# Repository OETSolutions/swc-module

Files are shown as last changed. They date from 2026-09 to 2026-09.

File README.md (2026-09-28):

# SWC — Steering Wheel Controls Adapter

A programmable interface between a vehicle's factory steering-wheel buttons and
an aftermarket Android head unit, so the buttons can be re-mapped, combined, or
given press behaviours the factory wiring never had.

**Status:** design complete and routed; 0 DRC errors, 0 unconnected, 0
schematic/PCB parity errors. **Not yet ordered.**

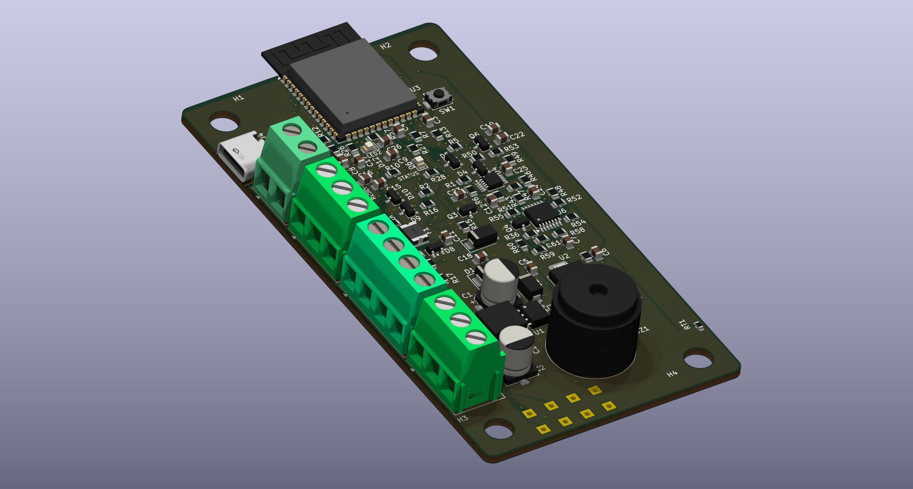
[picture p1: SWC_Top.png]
SWC adapter, top
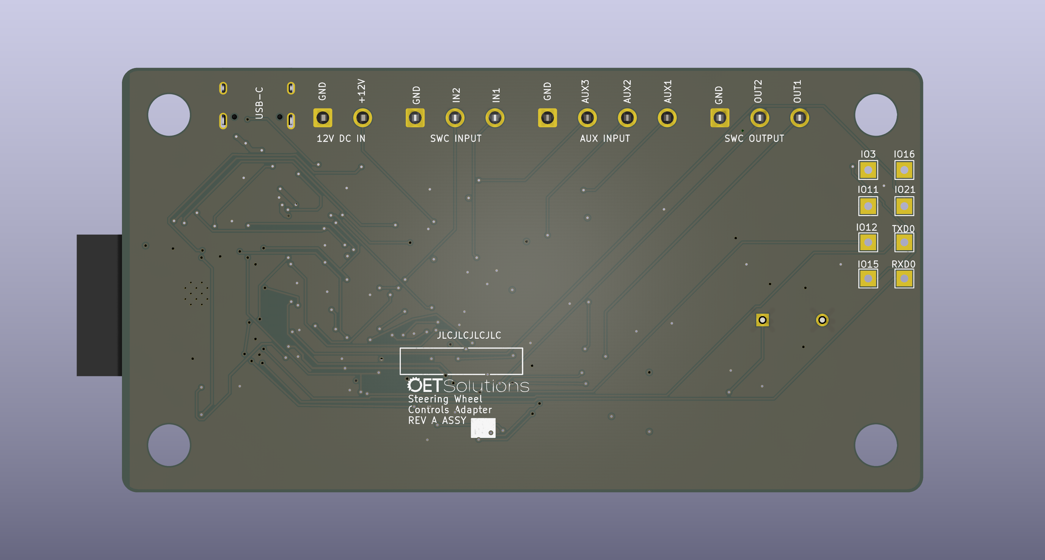
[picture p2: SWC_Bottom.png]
SWC adapter, bottom
|  |  |
| :--: | :--: |
| **Top** — ESP32-S3 module, four left-edge screw terminals, USB-C | **Bottom** — connector pinouts silkscreened on the back |

| Item | Value |
| --- | --- |
| **Board** | 54.0 × 102.0 mm, 4-layer, 1.6 mm, rounded corners r ≈ 2.83 mm |
| **EDA** | KiCad 10 (`SWC.kicad_pcb` / `.kicad_sch` / `.kicad_pro`) |
| **Assembly** | JLCPCB, Economic PCBA, 5-off |
| **Parts** | 34 unique LCSC part types, JLCPCB-assembled |
| **MCU** | DOIT ESPS3-32-N4 (ESP32-S3-WROOM-1 clone), native USB-CDC + USB-JTAG |

## Why this exists

A steering-wheel button is not a digital switch. It is a resistor dropped across
a single analog **KEY** line; the head unit pulls that line up and identifies the
pressed button from the voltage it reads. There are usually two such lines —
this board calls them **SWC1** and **SWC2** — with the buttons split between
them.

That arrangement is cheap and robust, and also completely fixed: the resistor
values, and therefore the head unit's behaviour, live in the factory button pod.
An aftermarket head unit wants a specific resistance it was taught, or one the
user can program. This adapter supplies it by reading the ladder on one side and
*servoing* the head unit's KEY line on the other, so the mapping becomes
software. It can additionally send commands to the head unit over USB when a
button is pressed, for actions the head unit's own steering-wheel input cannot
express.

## Architecture at a glance

Two identical channels. The factory ladder is read by the ESP32-S3's ADC; the
head unit's KEY line is driven by a closed-loop servo, so the output tracks what
the board actually senses rather than what it assumes.

```text
  SWC1  J2.3 ─R1 10k─┬─ /SWC1_ADC ─────────► U3 ADC1
  SWC2  J2.2 ─R2 10k─┴─ /SWC2_ADC ─────────► U3 ADC1
        (R15/R16 10k pull-ups to +3V3 · D4/D5 BAT54S clamp · C3/C4 100nF)

  AUX1  J5.4 ─R23 1k─┬─ /AUX1_F ───────────► U3 ADC
  AUX2  J5.3 ─R24 1k─┤   /AUX2_F
  AUX3  J5.2 ─R25 1k─┴─ /AUX3_F
        (R17/R18/R19 10k pull-ups to +3V3 · D8/D9/D10 BAT54S · C15–C17 100nF)

  U3 ESP32-S3 ══ I2C, 3.3 V, R5/R6 10k pull-ups ══ U4 MCP4728  (VDD = +3V3,
       │                                              VREF = VDD, 0–3.3 V FS)
       │                                              ┌ A ─ signal, ch 1
       │                                              ├ B ─ gain mode, ch 1
       │                                              ├ C ─ signal, ch 2
       │                                              └ D ─ gain mode, ch 2
       │
       └─ per channel:  U4.VOUTx ─R46 100k─► U6x− ─(C24 100nF fb)─► U6x out
                                          U6x+ ◄─ R58 82k ─ V_buf
                                              ◄─ R61 100k ─ V_ADJ (VOUTB/D)
                        U6x out ─R52 1k─► Q4 gate ─► Q4 drain = KEY line
                        KEY ─R36 1M─► U6y buffer ─┬─► R54 10k / R50 10k ─► /SENSEx ─► U3 ADC
                                                   └─► R58 (feedback above)

  12 V ─ J1 ─ F1 PPTC ─► /+12V_SW ─► D1 SMBJ18A ─► U1 XL1509-5.0 ─► L1 47µH ─┐
                                                  (D7 SS34 freewheel)         │
  USB VBUS ─ J4 ─ F2 PPTC ─► /VBUS_FUSED ─► D3 SS34 ─┐                        │
                                                     ├─► +5V ─► U2 AMS1117 ─► +3V3
                              /+5V_BUCK ─► D2 SS34 ──┘
  NTC RT1 on /TEMP_ADC · buzzer BZ1 via Q3 · LEDs D6 / D12 · VBUS detect /VBUS_VALID
```

The three ideas that make it work:

- **The ladder is read, not re-created.** 10 kΩ series (1 kΩ on the AUX inputs),
  a BAT54S clamp to +3V3/GND, a filter, and a pull-up — so a bare
  switch-to-ground button works as well as a resistor ladder.
- **The output is a servo, not a buffer.** `V_KEY = (1 + R58/R61)·V_DAC −
  (R58/R61)·V_ADJ`, so the gain is a resistor ratio and the offset is a second
  DAC channel. That gives runtime range switching between 3 V and 5 V head
  units, and it is why the ESP32 needs no DAC of its own (the S3 has none).
- **Idle is inherently high-impedance.** The sink FET only pulls down; a command
  above the head unit's own idle voltage turns it off and the line floats back up
  through a 1 MΩ sense resistor.

Full description, including the analog detail, the power path, the USB front end,
and the reasoning behind each component choice: **[DESIGN.md](DESIGN.md)**.

## Repository guide

| Document | Contents |
| --- | --- |
| **[MANUAL.md](MANUAL.md)** | How to install and use the adapter — wiring, learning buttons, bindings, the app, firmware updates, troubleshooting |
| **[DESIGN.md](DESIGN.md)** | Requirements, block diagram, theory of operation, design rules, key design decisions |
| **[MANUFACTURING.md](MANUFACTURING.md)** | BOM generation, part list, assembly-cost analysis, fabrication output, ordering decisions |
| **[CHANGELOG.md](CHANGELOG.md)** | Revision history, accepted limitations, open items |
| **[AGENTS.md](AGENTS.md)** | How to work on the files — rules, MCP servers, skills, verify loop, gotchas. `CLAUDE.md` points here. |
| **[tools/README.md](tools/README.md)** | The sanctioned direct-write scripts, in detail |

The live project is `SWC.kicad_sch` / `SWC.kicad_pcb` / `SWC.kicad_pro` /
`SWC.kicad_sym` / the two library tables. `3dmodels/` and
`footprints/logo.pretty/` are required project-local assets; `tools/` holds the
sanctioned direct-write scripts; `SWC-backups/` and `SWC2-backups/` are the
restore path; `old/` is the 2022 RP2040 design, kept for reference only. The
full annotated layout, including what is git-ignored, is in
**[AGENTS.md](AGENTS.md)**.

## Toolchain and credits

This board was developed with a small set of external tools, all worth citing:

- **[KiCad 10](https://www.kicad.org/)** — the EDA suite. All file manipulation
  in this project goes through an MCP server rather than hand-editing.
- **[mcp-server-kicad](https://github.com/ProductOfAmerica/mcp-server-kicad)**
  (`uvx --from mcp-server-kicad mcp-server-kicad`) — the MCP server providing
  byte-preserving schematic, PCB, ERC/DRC and manufacturing-export tools. It is
  the reason every change here is scriptable and repeatable.
- **[pcbparts-mcp](https://github.com/Averyy/pcbparts-mcp)**
  (`https://pcbparts.dev/mcp`) — component search, JLCPCB stock and
  cross-reference, reference-board lookup, and PCB design rules. Used for the
  part-selection and stock-availability pass.
- **[KiStack](https://github.com/American-Embedded/kistack)** by American
  Embedded — a human-written set of KiCad skills (schematic, PCB, BOM, export,
  gerbers, footprint, symbol, panelize, product render) that standardised the
  workflow. Installed with `npx skills add American-Embedded/kistack`.
- **JLCPCB component skills** — `jlcpcb-component-finder` (part search by
  keyword, package, stock and price) and `jlcpcb-bom-generate-from-kicad` (KiCad
  BOM/position → JLCPCB PCBA order format), with its database refreshed from
  [jlcparts](https://yaqwsx.github.io/jlcparts/).

The per-tool notes and the working rules for this repository live in
**[AGENTS.md](AGENTS.md)**.

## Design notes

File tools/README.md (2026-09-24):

# `tools/` — the sanctioned direct writers

The kicad MCP server covers almost everything, but a few writes have no MCP tool
at all. These scripts are the one sanctioned exception.

**Still in force:** never hand-edit `.kicad_sch` / `.kicad_pcb` / `.kicad_sym` /
`.kicad_mod` / `.kicad_pro`, and avoid running `kicad-cli` directly. Prefer an MCP
tool whenever one exists. A script here is only for the gaps below.

Every script is narrow by construction: it acts on what is named on the command
line (one footprint, one model, one via, one field) and refuses ambiguous input
rather than guessing. The read-only ones are marked; run those freely.

## Scripts

| Script | Purpose | Writes? |
| --- | --- | --- |
| `addmodels.py` | Give the six model-less footprints (J1–J5, F1) their 3D model, with measured offsets. **Re-run after any footprint-library resync.** | yes |
| `pcbfields.py` | Place every PCB reference designator in a legal, readable spot. **Re-run after any resync.** | yes |
| `fieldplace.py` | Shared CST + geometry helper — imported by 15 of the other scripts here. Run standalone it also autoplaces schematic fields (the MCP server cannot set a field's *position*). | yes |
| `setfield.py` | Pin one footprint's Reference field to an explicit board position. | yes |
| `fptext.py` | Move one footprint's own printed silk text (an `fp_text` node — BZ1's "(+)" is the one on this board). No MCP tool reaches an `fp_text`. Costs a `lib_footprint_mismatch`. | yes |
| `silksearch.py` | Find a DRC-legal spot for one footprint's Reference field. | no |
| `silk.py` | Silkscreen text audit: the drawn angle of all 140 labels, plus text-vs-pad, text-vs-text and off-board tests. | no |
| `fieldsize.py` | Set one footprint field's text size. | yes |
| `padangle.py` | Set the pad-level `at` angle of every pad in one footprint. | yes |
| `modelrot.py` | Set one footprint's 3D-model rotation (for testing a model-orientation question). | yes |
| `modelcheck.py` | Does each retrieved 3D model actually cover the footprint it sits on? | no |
| `delvia.py` | Delete vias at named coordinates. No MCP tool can remove a via. Refuses a coordinate that does not match exactly one via. | yes |
| `keepoutflags.py` | Loosen a keepout's item flags, leaving its copper restrictions alone. | yes |
| `zoneisland.py` | Show, and optionally set, a zone's island-removal mode. | yes |
| `holes.py` | Name the mounting holes and square them up against the board edge. | yes |
| `boardgeo.py` | Board-space geometry: outline, courtyards as polygons, real collisions. | no |
| `box.py` | List every segment/via/pad intersecting a box, any net. | no |
| `j4rip.py` | List J4-net copper intersecting a region, with connectivity, so the rip set can be decided precisely. | no |
| `j4new.py` | J4 fan-out design + DRC-true clearance checker. | no |

Two more scripts are **retired — SWC2-era, written against the pre-rework
board**, and both **keep** the stale `SWC2.kicad_pcb` path on purpose: it fails
loudly rather than printing confident, wrong numbers. Neither's output
describes what is on `SWC.kicad_pcb`. Kept for provenance; read the header
before trusting either.

| Script | Purpose | Writes? |
| --- | --- | --- |
| `corridor_check.py` | USB / VBUS corridor verifier: clearance, track width vs net requirement, net connectivity. Its clearance model disagrees with KiCad's DRC on the reworked board (~48 phantom violations) — see its header. | no |
| `j4fan.py` | J4 (USB-C) fan-out designer/checker for the *rejected* placement (rot 90 @ 21.35; live is rot 270 @ 19.65, 48.206). | no |

## Two conventions that keep costing rounds

Both have been re-derived from scratch at least twice, each time after a wrong
answer had already been acted on. Neither is guessable — take the constants
from `silk.py` and `boardgeo.py` rather than writing them again.

**The footprint-local → board transform.** For a footprint at `(x, y)` at stored
angle `t` and a local point `(lx, ly)`:

```
bx = x + lx*cos t + ly*sin t
by = y - lx*sin t + ly*cos t
```

Note the sign on `sin`. `silk.rot_pt`, `silksearch.rot_pt` and
`boardgeo.rot_pt` are all this function — if you need it, import it, do not
write a fourth copy. A version with the sign the other way was live in
`silksearch.py` until 2026-09-10 and silently mis-placed every obstacle
belonging to a footprint at ±90°; only parts at 0/180 came out right, which is
why it survived a whole placement pass. Three independent checks pin it:
`boardgeo`'s docstring (two DRC messages on J1 and J4), KiCad's own F.SilkS SVG
(F2's field plots at 28.619, 43.820, which the wrong sign puts at 33.619,
56.320), and `get_footprint_bounds` on F2 (30.169..32.069 × 48.390..51.750).

**The drawn angle of a footprint field is the STORED angle alone** — not
`footprint + stored`. `silk.drawn_angle` is the definition; `pcbfields.py`
writes it, and `setfield.py` and `fptext.py` used to write `ang - frot` and
turn a designator meant to lie flat into one standing on end.

When a claim about geometry is in doubt, the tie-breakers, in order, are: DRC's
own message text, `mcp__kicad__export_pcb` to SVG (text elements carry an
explicit `rotate(...)` and `textLength`), then `get_footprint_bounds`. Not
arithmetic, and not a tool's own summary of itself.

## Running them

The board path is usually the argument (some take further flags; run with no
arguments or read the docstring for usage):

```
python3 tools/addmodels.py SWC.kicad_pcb
```

The writers use the MCP server's own s-expression parser
(`mcp_server_kicad._cst`) so their output matches KiCad's byte for byte.
`fieldplace` (imported by all of them) puts that package on `sys.path` itself,
resolving it from `SWC_MCP_SERVER_KICAD` if set or otherwise from the `uvx`
cache (`~/.cache/uv/archive-v0/*/mcp_server_kicad`) — set `SWC_MCP_SERVER_KICAD`
to the directory that contains `mcp_server_kicad/` to pin it explicitly, e.g. in
CI or a checkout where the module is vendored elsewhere.
`addmodels.py`, `pcbfields.py` and friends are idempotent — running one twice
changes nothing the second time.

They self-locate their imports, so they work from any working directory.

## `addmodels.py` in particular

It carries the measured derivation of every offset, including J4's, in its
docstring. Read it before changing an offset: both previous versions of the J4
note were wrong, and each wrong version cost a full round of rework. The short
version is `rotate (0 0 180)`, `offset (0 −1.07 0)`, and the reason the offset
cannot be derived from the STEP's `CARTESIAN_POINT`s is that KiCad applies the
STEP's internal placement (~2.1 mm in Y for this vendor file).

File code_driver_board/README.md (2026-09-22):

# SWC rig driver — the second board that drives the device under test

This project is the firmware for the board that **presents stimuli to the SWC
adapter under test** so its firmware can be exercised end to end with no vehicle
and no steering-wheel pod.

It is deliberately **separate from the two other firmware projects in this repo**:

| Project | What it is | Board |
| --- | --- | --- |
| `code/` | the product firmware | the device under test (DUT) |
| `code_board_test/` | the bring-up / hardware-test tool | one board, self-contained |
| **`code_driver_board/`** | **this** — the rig driver | the second board |

It shares no build with either. The hardware facts it needs (pin map, DAC frame,
servo transfer function) are **copied** from `code_board_test`, which in turn
cross-checked them against `production/netlist.ipc`. Both boards are the same
hardware, so the pin map is identical.

## The rig

Two SWC boards. The **driver** board's analog output is wired into the **DUT**
board's analog input; the driver presents a *button* by sinking that node, exactly
as a real button on a real steering wheel does.

```
        DRIVER BOARD                            DUT BOARD (code/)
        ┌──────────────┐                        ┌──────────────┐
        │ J3.3 KEY1 ───┼──── ladder stimulus ───┼─ J2.3 SWC1   │
        │ J3.2 KEY2 ───┼────────────────────────┼─ J2.2 SWC2   │
        │ J5.4 AUX1 ───┼──── programming sw. ───┼─ J5.4 AUX1   │
        │          GND ┼────────────────────────┼─ GND         │
        └──────────────┘                        └──────────────┘
             USB (console)                    USB (console + Android app)
```

- **A press is a low KEY voltage.** The driver's servo sinks the DUT's ladder
  node; releasing lets the DUT's own 10 kΩ pull-up set the node high again. There
  is no separate "button" wire — the analog level *is* the button.
- **AUX1 is the programming switch.** The driver's AUX1 pin sinks the DUT's AUX1
  to GND (R23 is shorted on the DUT, so the 1 kΩ series resistance is gone). Closed
  = programming button held. Open = the DUT's pull-up holds it released.
- **Common ground is required.** Without it nothing reads correctly and the failure
  looks like a dead DUT.

The loopback jumpers the bring-up tool used are **not** part of this rig — those
existed only to verify a freshly-assembled board's own signal chain, and they are
not needed here.

## What it can present

| Command | Action |
| --- | --- |
| `1` | a **SINGLE** press — press, release, then wait out the DUT's double-press window |
| `2` | a **DOUBLE** press — two presses inside the window, then the window |
| `3` | a **LONG** press — hold past the DUT's long-press threshold |
| `p` / `r` | press and hold / release, for manual timing |
| `l` | **LEARN** — close AUX1 *and* hold the key, then release (the §7.4 entry gesture) |
| `L` | **MAINTENANCE** — hold AUX1 alone ~3 s (opens the ~5 min window) |
| `a` | toggle the AUX1 programming switch by hand |
| `c` | toggle which DUT channel (SWC1 / SWC2) the stimulus is presented on |
| `m` / `M` | cycle the gain mode / auto-select it from the released level |
| `+` / `-` | nudge the commanded key level by 50 mV |
| `d` | diagnostic — what the KEY line rests at, and whether a command is reachable |
| `w` | watch the DUT's KEY **output** (loopback) for ~2 s, min/max/mean |
| `s` | status |

A gesture is a **timeline**: a press of `press_on_ms`, held, at a commanded key
voltage `key_mv`, and the DUT's own limits decide whether that is a SINGLE, a
DOUBLE or a LONG. Those limits are mirrored from the product firmware
(`code/lib/Gesture/PressClassifier.h`) in `include/DriverHarness.h` and asserted
by the host tests, so a mistimed press is a **failed host test**, not a
misclassified gesture on the bench.

## Building and running

```bash
cd code_driver_board

# Host tests — the gesture-timeline geometry, no board needed (~1 s)
pio test -e host

# Device build
pio run -e swc-s3-driver
```

## The one non-obvious build fact

**`lib/swc_logic` is compiled explicitly, through `build_src_filter`, not by the
library dependency finder.** In this project LDF resolves only the framework
libraries and never the project's own `lib/` — verified by probing with a trivial
library referenced directly from `src/`, which LDF still did not find. The failure
mode is not a clear one: LDF reports success, the pure-logic sources are simply
absent from the link, and the build dies with a wall of `undefined reference to
Output::` errors that read as a code problem. Both envs compile the sources
explicitly; the device env adds `+<../lib/*/*.cpp>` to the default `+<*>`.

## Timing, and what to change when the DUT moves

`Harness::kDefaultRig`:

| Field | Default | Bound by |
| --- | --- | --- |
| `key_mv` | 1240 | the learned button's `mv_center` on the DUT channel |
| `press_on_ms` | 150 | must be ≥ debounce (25) and < long (750) |
| `inter_press_ms` | 120 | must be < the double window (500) and > 0 |
| `long_press_ms` | 750 | the DUT's long-press threshold |
| `double_window_ms` | 500 | the DUT's double-press window |

`Harness::Validate()` returns the first way the config fails to produce the
gesture it names, and `s` prints it — so a typo is a message, not a silent
misclassification.

## Reading a result

The driver only **presents** stimuli. What the DUT *does* with them it reports
itself: its buzzer and LEDs on the bench, and its USB frames (visible in the
Android app or a serial monitor on the DUT's port). The driver prints what it
drove; the DUT tells you what it resolved. Compare the two.

The **loopback** (DUT SWC out → driver SWC in) closes the other direction: `w`
reads what the DUT is actually commanding on its KEY line, so "the DUT emitted an
event but nothing reached the head unit" is told from a reporting bug.

## Findings from the first session on hardware (2026-09-24)

The rig works end to end. The analog path was proven with the DUT's own frames:
with the driver presenting 1240 mV on channel 1, the DUT's `ladder_sample`
stream read **1206 mV**, a `learn_commit` stored it as `mv_center:1205,
mv_tolerance:120`, and a subsequent synthetic SINGLE classified as
`event{channel:0, button:"rig1", gesture:"SINGLE"}` — with `config_state`
flipping `"none"` → `"ok"`.

**One DUT defect found: a learned-only button (no binding) re-emitted its gesture
every poll tick while held, and never advanced to a later gesture.** Measured on
hardware: a 2 s steady hold at the learned level produced 26–177 identical
`event{…,"gesture":"SINGLE"}` frames ~70 ms apart, versus exactly 1 at a higher
button level.

The mechanism, from the loopback (`w`): the DUT drives its KEY pulse, and its
**own** KEY sense reads that pulse below the 1800 mV envelope floor, so
`head_unit_gone` went true, the tail did `ReleaseKey + gestures.Reset()` every
tick, and the next tick re-classified the still-held press and re-emitted. A
learned-only button (the headless learn path — `ConfigDefault` ships
`binding_count = 0`) maps to the command-band floor of 1800 mV, which is what
tripped it; a bound `OUT_VOLTAGE` at a higher level did not. `gestures.Reset()` on
the recurring `head_unit_gone` condition also discarded the press state, so a held
button could never reach LONG.

Not a rig problem, and not a duplicate-emit bug in the emit path — the
head-unit-gone response acting on the DUT's own output through its own sense node.

**FIXED 2026-09-24** in `SystemOrchestrator::HeadUnitGone`. `V_KEY_idle` is the
line's IDLE, so the envelope is only meaningful on a *released* line; while the
device DRIVES, the sense node reads the device's own output and there is no
head-unit reading to take. A driven line is now judged only on a DEEP sag: every
command clamps to the band floor, so a reading at or above `kFaultSagMaxMv`
(1600 mV, the floor less a 200 mV margin) is one we produced, not a fault. A rail
collapse still drives the line far below that and still releases (FR-39's
phantom-key hazard). The verdict also now has to persist for 250 ms
(`kHeadUnitGoneSettleMs`), so a line settling after a pulse — or a rail coming up
at boot — is not mistaken for an absent head unit.

Regression test `ADrivenLineAtTheCommandFloorIsNotAHeadUnitGoneFault`
(`SystemOrchestratorTest.cpp`), mutation-checked: removing the sag guard fails
exactly that test. `ARailSagDuringAPressReleasesTheKey` still covers the deep-sag
release. Native suite 503 → 504.

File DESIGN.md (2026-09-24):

# Design document — SWC Steering Wheel Controls Adapter

Engineering description of the board: requirements, theory of operation,
component choices, and the reasoning behind them. For what the project is and
how to build it, see [README.md](README.md). For sourcing and fabrication, see
[MANUFACTURING.md](MANUFACTURING.md). For how to work on the files, see
[AGENTS.md](AGENTS.md).

- [1. Requirements](#1-requirements)
- [2. Prior design](#2-prior-design)
- [3. Block diagram](#3-block-diagram)
- [4. Theory of operation](#4-theory-of-operation)
- [5. Design rules and stackup](#5-design-rules-and-stackup)
- [6. Key design decisions](#6-key-design-decisions)
- [7. Open items](#7-open-items)

## 1. Requirements

The design brief, in full:

- ESP32 module; USB-C to the head unit (the ESP32 enumerates as a USB CDC
  serial device and takes commands).
- Two identical channels: ladder → ADC → translate → DAC → head-unit KEY input.
- The DAC range must sit **within the head-unit input range sensed at startup**.
- The output must be **isolated / high-impedance when idle**, so the head-unit
  KEY line floats to its own Vcc when not driven.
- Single, double and long-press translation, with a temperature sensor to
  compensate for ladder drift over the cabin temperature range.
- Screw terminals on the board edge for power, inputs and outputs; USB-C on an
  edge.
- JLCPCB assembly, stock parts, Economy/Basic tier where possible; **Extended
  parts only if there is absolutely no alternative.**
- Professional schematic and layout; clean ERC and DRC.

## 2. Prior design

This is a redesign of a 2022 RP2040 board. Its sources are archived under
`old/` and are reference only. Its specific failures — the reason this board
exists — were:

- it used a **digital pot**, which was not precise enough (this board uses a
  12-bit DAC with a servoed output instead);
- **no auto-ranging** to the head unit's sensed input voltage;
- **no temperature compensation**;
- it was a Pi Pico module build, not a custom PCB.

## 3. Block diagram

Two identical channels, **SWC1** and **SWC2**. Every part below is per channel
unless noted; channel 2 mirrors channel 1 with the `C`/`D` halves of the DAC and
quad op-amp.

```text
  SWC1  J2.3 ─R1 10k─┬─ /SWC1_ADC ─────────► U3 ADC1
  SWC2  J2.2 ─R2 10k─┴─ /SWC2_ADC ─────────► U3 ADC1
        (R15/R16 10k pull-ups to +3V3 · D4/D5 BAT54S clamp · C3/C4 100nF)

  AUX1  J5.4 ─R23 1k─┬─ /AUX1_F ───────────► U3 ADC
  AUX2  J5.3 ─R24 1k─┤   /AUX2_F
  AUX3  J5.2 ─R25 1k─┴─ /AUX3_F
        (R17/R18/R19 10k pull-ups to +3V3 · D8/D9/D10 BAT54S · C15–C17 100nF)

  U3 ESP32-S3 ══ I2C, 3.3 V, R5/R6 10k pull-ups ══ U4 MCP4728  (VDD = +3V3,
       │                                              VREF = VDD, 0–3.3 V FS)
       │                                              ┌ A ─ signal, ch 1
       │                                              ├ B ─ gain mode, ch 1
       │                                              ├ C ─ signal, ch 2
       │                                              └ D ─ gain mode, ch 2
       │
       └─ per channel:  U4.VOUTx ─R46 100k─► U6x− ─(C24 100nF fb)─► U6x out
                                          U6x+ ◄─ R58 82k ─ V_buf
                                              ◄─ R61 100k ─ V_ADJ (VOUTB/D)
                        U6x out ─R52 1k─► Q4 gate ─► Q4 drain = KEY line
                        KEY ─R36 1M─► U6y buffer ─┬─► R54 10k / R50 10k ─► /SENSEx ─► U3 ADC
                                                   └─► R58 (feedback above)

  12 V ─ J1 ─ F1 PPTC ─► /+12V_SW ─► D1 SMBJ18A ─► U1 XL1509-5.0 ─► L1 47µH ─┐
                                                  (D7 SS34 freewheel)         │
  USB VBUS ─ J4 ─ F2 PPTC ─► /VBUS_FUSED ─► D3 SS34 ─┐                        │
                                                     ├─► +5V ─► U2 AMS1117 ─► +3V3
                              /+5V_BUCK ─► D2 SS34 ──┘
  NTC RT1 on /TEMP_ADC · buzzer BZ1 via Q3 · LEDs D6 / D12 · VBUS detect /VBUS_VALID
```

## 4. Theory of operation

### 4.1 Inputs

**SWC1 / SWC2.** The steering-pad ladder is a **series resistor chain whose
common is tied to GND**; each button shunts a different point in the chain to
that common, so a press pulls the input **down**. Idle (no button) is therefore
the *high* state, set by the **10 kΩ pull-up** (`R15`/`R16`) to +3V3. Each input
takes a **10 kΩ series resistor** (`R1`/`R2`) into a **BAT54S** clamp
(`D4`/`D5`) to +3V3/GND (protection only, not the operating point), a 100 nF
filter (`C3`/`C4`), and that pull-up. The pull-up is what lets a bare
switch-to-ground button work as well as a ladder. Both SWC lines land on the
ESP32-S3's ADC inputs.

> **Correction (2026-09-18).** This paragraph previously said the ladder is
> "pulled to 12 V when idle", which is wrong and inverts the direction a press
> moves the input. Verified against `Tundra_SWC_steeringpadswitch.bmp` in the
> Android_Stereo_Apps working notes and with the board's owner. The ladder
> resistances are vehicle-specific, so **`R15`/`R16` may need adjusting to spread
> the buttons adequately across the ADC range** — measure before assuming.
> The firmware spec's §2.4/§6.3 carry the corrected derivation.

**AUX1–AUX3.** On the 4-pin `J5` terminal, intended for extra buttons or
programming functions. Identical conditioning but with a **1 kΩ series
resistor** (`R23`–`R25`) rather than 10 k, the same BAT54S clamp
(`D8`–`D10`), 100 nF (`C15`–`C17`) and 10 kΩ pull-ups (`R17`–`R19`). All three
sit on ADC-capable module pins.

All three terminals that carry signals — `J2` (inputs), `J3` (outputs) and `J5`
(AUX) — include a **GND pin**, so each cable carries its own reference.

### 4.2 The ESP32-S3 and its analog ceiling

Two facts drive the whole analog design, and both are worth stating explicitly
because they have been gotten wrong before:

- **The ESP32-S3 has no DAC at all.** The classic ESP32's 8-bit DAC did not
  carry over to the S3. This is why the external DAC is not optional.
- **The S3's calibrated ADC ceiling is 2.9 V**, not 3.1 V, at the 12 dB
  attenuation setting. Every divider on the board is scaled against 2.9 V.

The module's native USB provides both the CDC interface to the head unit and
USB-JTAG for debugging.

### 4.3 DAC

`U4` is an **MCP4728** quad 12-bit I²C DAC. It runs from **+3V3** with
**VREF = VDD**, so its full-scale output is 3.3 V (1 LSB = 0.806 mV) — it is
*not* the 4.096 V internal-reference mode, which would require VDD ≥ 4.096 V.
Because the DAC is on 3.3 V, it shares the ESP32's I²C bus **directly**, with
`R5`/`R6` 10 kΩ pull-ups to +3V3 — there is **no level shifter**. A level
translation stage would be needed only if the DAC ran on 5 V; it does not. Its
LDAC pin is driven from a GPIO (`R13` 10 kΩ pulldown) and its `RDY/BSY` is left
unconnected.

The four channels are paired per signal channel: **A = signal and B = gain mode
for channel 1; C = signal and D = gain mode for channel 2.**

### 4.4 Output servo

**The output is a closed-loop servo, not an open-loop buffer.** Per channel,
the DAC voltage enters `U6A`'s inverting input through `R46` (100 kΩ), with
`C24` (100 nF) as feedback — an **integrator**. At DC the integrator forces no
current through `R46`, so `U6A−` equals the DAC voltage, and the op-amp forces
`U6A+` to match. `U6A+` is the summing junction of `R58` (82 kΩ, from the
sensed KEY-line voltage `V_buf`) and `R61` (100 kΩ, from the gain-mode DAC
output). Solving gives the load-bearing relation:

```text
V_KEY = (1 + R58/R61)·V_DAC − (R58/R61)·V_ADJ
```

So **the gain is set by the resistor ratio alone, and `V_ADJ` shifts the
offset** — it does not change the gain. `U6A`'s output drives the sink FET `Q4`
gate through `R52` (1 kΩ), with `R48` (100 kΩ) holding the gate low if the
op-amp is unpowered.

**The gain-mode channel is a range selector.** `R58/R61` = 82 k/100 k gives a
gain of 1.812, which is what lets a 3.3 V DAC drive a 5 V head unit. The mode is
chosen by what the `V_ADJ` channel does:

| Head unit | `V_ADJ` channel | Mechanism | Gain |
| --- | --- | --- | --- |
| **5 V range** | powered down (`PD1:PD0 = 01`) | 1 kΩ path to GND — current flows in `R58` | **1.812** |
| **3 V range** | normal, tracking the signal channel's code | `V_ADJ = V_DAC` — no current in `R58` or `R61` | **1.000** |

This is a defined path rather than a leakage one, which is the point: the
MCP4728 has **no high-impedance state** — all three of its power-down modes are
pull-downs to GND at 1 kΩ, 100 kΩ or 500 kΩ. The 1 kΩ power-down is exactly
what the 5 V mode wants, so a DAC channel can be used as a switch without any
leakage error. A series MOSFET was considered and rejected — see
[§6](#6-key-design-decisions).

Two consequences worth knowing:

- **The real ceiling is the op-amp rail, not the gain.** `U6` runs on +5 V, so
  `V_buf` cannot exceed ~4.98 V. Gain 1.812 advertises 6.0 V but the KEY line
  can only be actively servoed to about 5 V; the extra gain is *release margin*,
  putting the release command safely above idle rather than on the boundary.
- **The ADC can never saturate.** See [§4.5](#45-sense).

### 4.5 Sense

The KEY line is buffered by `U6B`, wired as a unity-gain follower (`U6.6` tied
to `U6.7`), reading through `R36` (1 MΩ) — so the sense path presents a picoamp
load to the head-unit line and never loads it. The buffer output then feeds two
places: back into the servo as `V_buf`, and through a **10 kΩ / 10 kΩ divider**
(`R54`/`R50`) into `/SENSE1` with a 100 nF anti-alias capacitor (`C22`).

The divider is an **exact ÷2**, so `V_SENSE = V_KEY/2`. Because the op-amp rail
binds first (V_buf ≤ ~4.98 V), the sense node can never exceed ~2.49 V — safely
*under* the S3's 2.9 V calibrated ceiling. **The op-amp rail protects the ADC
for free, and the ADC can never saturate.**

Measuring `V_SENSE` at startup, with the output released, is how the firmware
learns the head unit's own idle/float voltage and so auto-ranges its output — one
of the capabilities the 2022 design lacked ([§2](#2-prior-design)).

### 4.6 Idle is inherently high-impedance

Releasing the line needs no special mode. `Q4` **only sinks**: it pulls the KEY
line down to ground. Commanding a target *above* the head unit's idle voltage
makes the servo drive the gate low, `Q4` turns off, and the line floats up to the
head unit's own pull-up through only `R36` (1 MΩ) into the follower's input.

Power-up safety follows: with the DAC at zero the loop would servo the line to a
stuck press, so the firmware programs the MCP4728's EEPROM so that channel A
resets to full scale — the maximum command — and the gain-mode channel resets
powered-down. That yields a 5 V-range command that releases both 3 V and 5 V head
units.

### 4.7 Power

Both a 12 V feed and USB VBUS can power the board, and — importantly — **the
12 V feed is optional**. Diode-OR'd at +5 V, either source alone is sufficient;
if both are present the higher one supplies the rail.

- **12 V path:** `J1` → `F1` PPTC (1.5 A) → `/+12V_SW` → `D1` SMBJ18A TVS →
  `U1` XL1509-5.0 buck with `L1` (47 µH); **`D7` (SS34) is the freewheeling
  diode** on the switch node.
- **USB path:** `J4` VBUS → `F2` PPTC (1.0 A) → `/VBUS_FUSED` → **`D3` (SS34)**.
- **Buck output:** `/+5V_BUCK` → **`D2` (SS34)**.
- `D2` and `D3` are the OR-ing diodes. Each source therefore has its own PPTC
  and its own Schottky, so a fault on one cannot back-feed through the other.
- **3.3 V:** `U2` AMS1117-3.3 from +5 V.
- Bulk 100 µF/50 V capacitors sit on the +12 V and buck-output nodes.

`/VBUS_VALID` is a divider (`R56`/`R57` 10 kΩ/10 kΩ with 100 nF `C26`) off the
fused VBUS, so the firmware can tell whether USB power is present.

### 4.8 USB

`J4` is a 16-pin USB-C receptacle feeding the ESP32-S3's **native USB**, which is
**Full-Speed / Low-Speed only — the S3 has no High-Speed PHY**. D+/D− pass
through `U8`, a `USBLC6-2SC6` ESD array, then through 22 Ω series resistors
`R11`/`R12`, then to the module.

The ordering is deliberate: **connector → clamp → series R → IC**. The transient
is diverted into the TVS *before* the resistor, leaving the resistor to limit
only the residual current into the ESP32 pin. The USBLC6-2 is flow-through
(pins 1↔6 and 3↔4 are the same channel), which is why both ends of each channel
sit on the connector-side net. `U8` is also powered from `/VBUS`, so the clamps
are referenced to the actual USB rail.

The pair is length-matched, though at Full-Speed no impedance target is owed —
USB 2.0's 90 Ω ±15 % applies to High-Speed only. It costs nothing, and the pair
is via-free on F.Cu. On the 22 Ω value itself, see
[§6](#6-key-design-decisions).

### 4.9 Thermal sensing

`RT1` (a 10 kΩ B3380 NTC, 0603) sits from `/TEMP_ADC` to GND, with `R29` (10 kΩ)
to +3V3 and `C19` (100 nF). It compensates the ladder for temperature drift, so
it must measure the *environment*, not the board: it is placed at **(68.5, 120.0)**
on the exposed right edge, roughly 33 mm from the nearest heat source, where case
ventilation reaches it, and its divider trace is kept out of thermal gradients.

The four board corners — the obvious place for an edge sensor — are unusable:
each carries an M5 mounting hole whose courtyard is a 5.55 mm radius circle.

### 4.10 Peripherals

- **Buzzer `BZ1`** on +5 V, switched low-side by `Q3` (2N7002) from `/BUZZ`
  through `R27` (100 Ω), with `R28` (100 kΩ) holding the gate low. `D11` (SS34)
  is its freewheeling diode. `BZ1` is a 5–15 V part, so it cannot run from 3V3.
- **LEDs:** `D6` (`/LED_STAT`, via `R7`) and `D12` (`/LED2`, via `R26`).
- **Buttons:** `SW1` (BOOT → module strapping pin) and `SW2` (RESET → EN).
- **Test points:** `TP1`–`TP6` on module I/O, plus `TP7`/`TP8` on the UART
  `TXD0`/`RXD0`. All eight are bare through-hole pads with no purchased part.
  `TP7`/`TP8` are **the console**: the production console is on UART0 (GPIO43/44,
  off the USB PHY), so it stays readable after TinyUSB takes the PHY for the app
  link (N-16, fixed 2026-09-25) — clip a UART adapter (`115200 8N1`) between them
  and a ground pad.

### 4.11 Interfaces

| Ref | Function | Pins | Position |
| --- | --- | --- | --- |
| `J1` | 12 V DC in | GND, +12 V | left edge |
| `J2` | SWC input | GND, SWC2, SWC1 | left edge |
| `J3` | Output to head unit | GND, KEY2, KEY1 | left edge |
| `J5` | Auxiliary inputs | GND, AUX3, AUX2, AUX1 | left edge |
| `J4` | USB-C | — | top-left edge |
| `SW1` / `SW2` | BOOT / RESET | — | — |
| `TP1`–`TP8` | Test points | — | bottom edge, B.Cu |

All four screw terminals are CUI TB007 series on 5.08 mm pitch, on the left board
edge so wire entry runs along the edge; USB-C sits on the top-left edge. The
brief allowed for separate per-channel SWC/output terminals; the two channels
instead share one input (`J2`) and one output (`J3`) terminal, each with a GND
pin.

### 4.12 The ESP32 antenna

The module overhangs the top board edge by **5.900 mm**, at the antenna end. This
is a deliberate acceptance decision, not an oversight, and it means no antenna
cutout is needed: the stock 48 × 21 mm keepout lies off the board except for a
0.25 mm sliver, so there is no copper under the antenna because there is no board
under the antenna.

| | board mm |
| --- | --- |
| Board top edge (`Edge.Cuts` y = 31.000, x 18…68) | 31.000 |
| `U3` module body (F.SilkS outline) | y 25.100 … 50.950 |
| `U3` pads (62), centres | y 32.740 … 50.500 |
| `U3` pads (62), copper edges | y 32.290 … 51.250 |
| `U3` antenna keepout (F.CrtYd stub, x 22.219 … 70.219) | y 10.250 … 31.250 |

The consequence — and the reason the board is 102 mm tall — is that the overhang
**must be supported by the enclosure**. A fully-seated module would need roughly
108 mm of board, and the pad row at y 32.740 is already only 1.740 mm from the
edge, so the module cannot simply be moved down. The two `silk_edge_clearance`
warnings on `U3` are the module outline being drawn across the edge it
intentionally crosses.

## 5. Design rules and stackup

From `SWC.kicad_pro`:

| Rule | Value |
| --- | --- |
| Minimum clearance | 0.150 mm |
| Minimum track width | 0.150 mm (default routed width 0.200 mm) |
| Copper-to-edge clearance | 0.300 mm |
| Hole-to-hole | 0.250 mm |
| Via | 0.6 / 0.3 mm (secondary 0.8 / 0.4) |

Four copper layers — F.Cu / In1.Cu (power) / In2.Cu (power) / B.Cu — with five
zones. Board outline 54.00 × 102.00 mm, 1.6 mm thick, rounded corners r ≈ 2.83 mm.

## 6. Key design decisions

| Decision | Rationale | Alternative rejected |
| --- | --- | --- |
| External 12-bit DAC | The ESP32-S3 has **no DAC at all** (the classic ESP32's 8-bit DAC did not carry over), and 8 bits would be too coarse anyway | On-chip DAC — does not exist on the S3 |
| DAC on +3V3, VREF = VDD | VDD must be ≥ 4.096 V for the internal-reference mode, so that mode is invalid here; a 3.3 V DAC also shares the ESP32's I²C bus directly | 5 V DAC + I²C level shifter — adds parts, buys nothing |
| **No I²C level shifter** | Both the ESP32-S3 and the MCP4728 are on 3.3 V, on the same bus, with `R5`/`R6` pull-ups. There is no voltage domain to translate | Level shifter — only needed if the DAC ran on 5 V |
| Closed-loop integrator servo | Regulates the KEY line against the sensed `V_buf`, so output is precise and repeatable; the 2022 design's digital pot was not | Open-loop buffer — no load regulation |
| Gain set by `R58/R61` at the summing node, offset by `V_ADJ` | Gain and offset separate cleanly: `V_KEY = (1+R58/R61)·V_DAC − (R58/R61)·V_ADJ` | Resistor change per head-unit range — not switchable at runtime |
| **`V_ADJ` driven by a DAC channel, not a GPIO** | The MCP4728 has no Hi-Z state but does have a *defined 1 kΩ* power-down, which is exactly what the 5 V range wants | Series MOSFET — off-state leakage appears at the KEY line multiplied by `R58`, and a 2N7002's `I_DSS` roughly doubles per 10 °C |
| ÷2 sense divider **after** the buffer | `V_SENSE ≤ 2.49 V`, under the S3's 2.9 V ceiling, so the ADC can never saturate; being after the buffer means it never loads the head-unit line | Divider at the input — would load the KEY line |
| 22 Ω USB series resistors | Follows ST's own USBLC6-2 application circuit (Fig. 14) and the brief, at a value that is provably harmless because the S3 never runs High-Speed. **Not an Espressif requirement** — the ESP32-S3-DevKitC-1 v1.1 runs its data lines straight to the module with no series resistors at all | Omit them — also valid; kept because they cost nothing (Basic part) and follow vendor topology |
| Connector → clamp → series R → IC ordering | Diverts the transient into the TVS *before* the resistor, leaving the resistor to limit only residual current into the pin | Series R before the clamp |
| ESP32 antenna overhangs the top edge, no cutout | The keepout lies off-board except a 0.25 mm sliver, so there is simply no copper under the antenna | Antenna cutout / slot — unnecessary |

## 7. Open items

**A project-local footprint library for `J4`, `U3` and `R60`.** Their local
edits are currently undone by any footprint-library resync or KiCad upgrade —
the same failure mode that hit the `J4` 3D model. A project-local
`footprints/<lib>.pretty` (already the pattern used for `logo.pretty`) makes the
edits durable *and* clears the three `lib_footprint_mismatch` warnings. It is
not done because there is no sanctioned way: the kicad MCP server has no
footprint-library tool and no tool writes a `.kicad_mod` at all, so it needs
either hand-written files (forbidden) or a new script under the `tools/`
exception. See [AGENTS.md](AGENTS.md).

The other open question — **4-layer vs 2-layer at order time** — is a purchasing
decision, not a design one, and lives in
[MANUFACTURING.md §5](MANUFACTURING.md#5-ordering-decisions).

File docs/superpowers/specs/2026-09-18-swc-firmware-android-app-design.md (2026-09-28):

# SWC Adapter — Firmware & Head-Unit App Design Spec

**Date:** 2026-09-18
**Status:** DRAFT — awaiting review
**Deliverable:** Working firmware for the `SWC.kicad_pcb` board (ESP32-S3), an
Android app for the head unit, and the web/BLE maintenance path — all under
`code/` in this repository.

**Companion plan:** `docs/superpowers/plans/2026-09-18-swc-firmware-android-app.md`

---

## 1. What this builds, and why

The board already exists and is ordered. It reads a vehicle's steering-wheel
button ladder on each of two channels, and drives a servo-controlled current
sink to present the head unit with a key resistance the head unit understands.
The hardware is fixed; **this document specifies the software that makes it
work**, and nothing in it may contradict the board.

Three components:

| # | Component | Runs on | Owns |
| --- | --- | --- | --- |
| A | **Firmware** | ESP32-S3 on the SWC board | Ladder acquisition, press classification, DAC/servo output, buzzer + LED feedback, config storage, USB command link, BLE provisioning, WiFi OTA |
| B | **Head-unit app** | The Android head unit | Config UI, per-vehicle ladder learning, action mapping (launch app / intent / key / media), the USB peer, USB OTA |
| C | **Maintenance web page** | Served by the ESP32 | Minimal: join WiFi, then OTA. Not a config UI |

The three requirements that shaped everything:

1. **The software is written before the board arrives.** The board is finalized
   and ordered. Every piece of logic that *can* be tested without hardware
   *must* be, so that bring-up is a tuning exercise, not a debugging one.
2. **A crash costs the user their steering-wheel controls while driving.** The
   failure mode is not a dropped request; it is a driver with no working
   buttons. Safety behavior is a first-class requirement, not a hardening pass.
3. **The USB-C port is the only connector, and it carries both power and data.**
   The same port must be the command link, the debug path, and (on the bench)
   the flashing path. There is no second connector to fall back on.

### 1.1 What is explicitly out of scope

- Any change to `SWC.kicad_pcb` / `SWC.kicad_sch`. The board is ordered. Defects
  found on the board are recorded in §12, not fixed here.
- The enclosure (`plastic_case/`) — already built, separate spec.
- A full web configuration UI. The ESP32 serves one maintenance page only (§8).
- Remote/cloud management. There is no server component.

---

## 2. Hardware contract (verified from the netlist)

**This section is the interface. Everything downstream depends on it.** Every
row is traceable to `mcp__kicad__export_netlist` output; nothing here is
inferred from prose or from part names. `DESIGN.md` §4 is the prose companion
and agrees with this table; where they ever differ, this table wins because it
was read from the netlist.

### 2.1 The MCU

| Item | Value |
| --- | --- |
| Module | `U3` DOIT `ESPS3-32-N4` (LCSC C49164655) |
| Silicon | ESP32-S3, dual-core Xtensa LX7, **no on-chip DAC** |
| Flash | **4 MB, no PSRAM** (see §9 — this is a hard budgeting constraint) |
| Footprint | `RF_Module:ESP32-S3-WROOM-1` (a WROOM-1 land-pattern clone) |
| USB | Native USB 1.1 Full-Speed only — the S3 has no High-Speed PHY |
| ADC ceiling | **2.9 V** calibrated at 12 dB attenuation (not 3.1 V) |
| Antenna | Module overhangs the board edge by 5.9 mm; keepout is off-board |

### 2.2 Complete pin map

Every GPIO the board connects, with its net, its direction and its function.
These are the only pins available — there is no spare-pin freedom here.

| GPIO | Net name | Dir | Function |
| --- | --- | --- | --- |
| IO1 | `/SWC1_ADC` | A-in | Channel 1 ladder, ADC1_CH0 |
| IO2 | `/SWC2_ADC` | A-in | Channel 2 ladder, ADC1_CH1 |
| IO7 | `/TEMP_ADC` | A-in | NTC `RT1` divider (10 k B3380) |
| IO8 | `/SENSE1` | A-in | Channel 1 KEY-line sense, KEY voltage ÷ 2 |
| IO9 | `/SENSE2` | A-in | Channel 2 KEY-line sense, KEY voltage ÷ 2 |
| IO10 | `/VBUS_VALID` | D-in | VBUS present (`R56`/`R57` ÷ 2 off fused VBUS) |
| IO13 | `/BUZZ` | D-out | Buzzer `BZ1` low-side `Q3` gate, via `R27` 100 Ω |
| IO14 | `/LED2` | D-out | LED `D12` (green), via `R26` 1 k |
| IO47 | `/LED_STAT` | D-out | LED `D6` (green), via `R7` 1 k |
| IO17 | `/I2C_SDA_3V3` | I/O | I²C SDA to `U4` MCP4728 |
| IO18 | `/I2C_SCL_3V3` | I/O | I²C SCL to `U4` MCP4728 |
| IO48 | `/DAC_LDAC_B_3V3` | D-out | MCP4728 `~LDAC` (active low), `R13` 10 k pulldown |
| IO0 | `/BOOT` | D-in | `SW1` BOOT — **strapping pin**, also usable as a user input |
| IO3 | `/IO3` | — | Spare, `TP1` test point only |
| IO4 | `/AUX1_F` | A-in | **AUX1** direct input, ADC1_CH3 |
| IO5 | `/AUX2_F` | A-in | **AUX2** direct input, ADC1_CH4 |
| IO6 | `/AUX3_F` | A-in | **AUX3** direct input, ADC1_CH5 |
| IO11 | `/IO11` | — | Spare, `TP2` only |
| IO12 | `/IO12` | — | Spare, `TP3` only |
| IO15 | `/IO15` | — | Spare, `TP4` only |
| IO16 | `/IO16` | — | Spare, `TP5` only |
| IO21 | `/IO21` | — | Spare, `TP6` only |
| IO19/IO20 | module USB | USB | `USB_D-` / `USB_D+` (not broken out as GPIO) |
| — | `/TXD0`, `/RXD0` | — | `TP7`/`TP8` only; ROM UART, no header pins |

**Constraints that follow:**

- **IO0 is a strapping pin.** It must not be held low at boot — holding it low at
  power-on enters the ROM serial-download bootloader, *not* a user action. This
  is why the programming and maintenance triggers (§7.5, §8.2) are **runtime
  long-presses on a running device**, never a hold-at-power-on.
- **AUX1–AUX3 (IO4/IO5/IO6) are fully usable analog inputs**, wired exactly like
  the SWC channels but with 1 kΩ series resistors. Together with the two SWC
  channels that is **five analog key inputs** — and the AUX inputs are the
  intended local programming/test buttons, since they need no external ladder.
- **IO4 is ADC1_CH3 on the S3.** Some Arduino cores map a DAC to IO4 on *other*
  ESP32 variants; the S3 has no DAC at all, so this is only a caution against
  copy-pasted board definitions, not a real hazard.
- **IO3, IO11, IO12, IO15, IO16, IO21 are broken out to test points only.**
  There is no header. They are not usable for user-facing features.
- **ADC1 only.** IO1, IO2, IO4, IO5, IO6, IO7, IO8, IO9 are all on ADC1. ADC2 is
  unusable while WiFi is active on ESP32-S3 — irrelevant in normal mode (the
  radio is off, §8.1) but a real constraint if any ADC2 pin is ever used later.
- There is **no external USB-UART bridge** and **no spare UART pins**. All
  serial I/O is over the native USB, and the console must live on the ROM
  USB-Serial-JTAG peripheral (§4.1).

### 2.3 The analog output stage (per channel)

The output is a **closed-loop integrator servo**, not an open-loop buffer.
Verified from the netlist and matching `DESIGN.md` §4.4:

```
V_KEY = (1 + R58/R61)·V_DAC − (R58/R61)·V_ADJ
        with R58 = 82 kΩ, R61 = 100 kΩ   →   V_KEY = 1.82·V_DAC − 0.82·V_ADJ
```

| Element | Refs (ch 1 / ch 2) | Value | Role |
| --- | --- | --- | --- |
| DAC signal channel | `U4` VOUTA / VOUTC | 12-bit, 0–3.3 V | Sets the target; drives integrator via 100 k |
| DAC gain channel (`V_ADJ`) | `U4` VOUTB / VOUTD | 12-bit, 0–3.3 V | **Gain-mode selector** |
| Integrator | `U6A` / `U6C` + 100 nF | — | Forces `U6−` = `V_DAC` at DC |
| Gain-set resistors | `R58`/`R61`, `R59`/`R60` | 82 k / 100 k | Sets gain = 1.82 |
| Sink FET | `Q4` / `Q6` (2N7002) | — | **Sinks only** — cannot source |
| Sense buffer | `U6B` / `U6D` | unity follower | Reads KEY line via 1 MΩ `R36`/`R43` |
| Sense divider | `R54`/`R50`, `R55`/`R51` | 10 k / 10 k | **Exact ÷2** → `/SENSEn` |
| Gate pulldown | `R48` / `R49` | 100 k | Holds FET off if op-amp unpowered |

**Two consequences the firmware must respect:**

1. **The gain mode is chosen by what the `V_ADJ` channel *is*, and the MCP4728
   has no high-impedance state.** Its power-down modes are 1 kΩ / 100 kΩ /
   500 kΩ pull-**downs**. The 1 kΩ one is exactly what the 5 V range needs.

   | Target head unit | `V_ADJ` channel | Gain |
   | --- | --- | --- |
   | 5 V range | powered down (`PD1:PD0 = 01`) → defined 1 kΩ to GND | **1.82** |
   | 3 V range | normal, tracking the signal channel's code | **1.00** |

   **"Tracking the signal channel's code" means `V_ADJ = V_DAC` on EVERY code
   write, not just at gain selection.** Selecting the mode only sets the ADJ
   channel's *power mode* (its code field is 0 in that write); the tracking
   relationship is a property of the two channels carrying the *same code*, so
   each KEY-line write must be paired with the matching ADJ write. Writing the
   power mode alone leaves `V_ADJ = 0` and the amplifier delivering 1.82× — the
   over-range direction §6.2 calls the only dangerous one — while every
   power-mode assertion still reads correct. (Found 2026-09-22: the firmware
   selected tracking mode and never wrote ADJ's code, so a 3 V head unit was
   driven at 1.82× and no test noticed because none read ADJ's code.)

2. **Releasing the KEY line needs no special mode.** `Q4` only sinks. To
   release, command a target *above* the head unit's own idle voltage; the servo
   drives the gate low, `Q4` turns off, and the line floats up through the head
   unit's own pull-up, loaded only by `R36` 1 MΩ. **Idle state = high impedance,
   for free.**

The op-amp runs on +5 V, so `V_buf` saturates near 4.98 V. Gain 1.82 advertises
6.0 V but the line can only be servoed to ~5 V — the surplus is deliberate
release margin, not a bug.

Because the sense divider is an exact ÷2 and the op-amp rail binds before the
ADC ceiling, **`V_SENSE` can never exceed ~2.49 V and the ADC can never
saturate.** No clamp logic is needed in firmware.

### 2.4 The ladder input (per channel)

```
steering-pad ladder (series chain, common tied to GND)
   └─ J2 ─ R1/R2 10 kΩ ─┬─ /SWC1_ADC / /SWC2_ADC ─► ESP32-S3 ADC1
                        ├─ R15/R16 10 kΩ pull-up to +3V3
                        ├─ D4/D5 BAT54S clamp to +3V3 / GND
                        └─ C3/C4 100 nF
```

**The ladder is a resistor chain with its common tied to ground, and a button
shorts the node it sits at to the chain's common — so pressing a button pulls the
input *down*, not up.** (Reference: `Tundra_SWC_steeringpadswitch.bmp` in the
Android_Stereo_Apps working notes, and the resistor-value table supplied as
`Likely Tundra Steering Wheel Switch Resistor Values.png` — both verified with
the board's owner, 2026-09-18; the table is transcribed in §2.4 below.)
This is the single most important correction in this section:

- **Idle (no button) is the *high* state:** the ladder's full series resistance
  sits between the pin node and GND, so the node is pulled up toward **+3V3**
  through `R15`/`R16`. It is **not** driven to +12 V, and the pin is therefore
  **never saturated** — the node sits inside the ADC's 2.9 V range.
- **Pressing a button lowers the node voltage** by shunting part of the ladder to
  GND. Different buttons short at different points in the chain, giving different
  resistances to GND and therefore different pin voltages.
- The **10 kΩ pull-up is what makes a bare switch-to-ground button work as well as
  a resistor ladder**, and it is what sets the idle level.
- The BAT54S clamp is **protection only** — against a miswire or a ladder that is
  externally pulled high. It is not the operating point.
- The node voltage is a function of the ladder resistance **and** of the +3V3
  rail, not the vehicle's 12 V rail. `R15`/`R16` and the ladder's own values form
  the divider, so **the pull-up value may need to be adjusted to suit the measured
  ladder resistances** — a bring-up measurement (§10.6), not an assumption.

> **This supersedes `DESIGN.md` §4.1's "pulled to 12 V when idle" prose, which is
> wrong.** An earlier revision of this section repeated that claim and derived a
> saturated-node transfer function from it; that derivation was retracted on
> 2026-09-18. §6.3 is written against the topology above.

`AUX1`–`AUX3` on `J5` are electrically identical but use a **1 kΩ** series
resistor (`R23`–`R25`) and the same pull-up/clamp/filter, on IO4/IO5/IO6.

**The vehicle's ladder values are now KNOWN (N-2, resolved 2026-09-24).** The
open item asked for the head unit's actual resistor values; they are the Toyota
Tundra's steering-pad ladder, supplied as a reference table and reproduced here
because §2.4's consequence 3 makes them load-bearing — the pull-up value and the
button separation both depend on them:

| KEY line | Button | R to ground | V_KEY (calc) |
| --- | --- | --- | --- |
| KEY 1 | SEEK+ | 0 Ω | 0.000 V |
| | SEEK− | 330 Ω | 0.105 V |
| | VOL+ | 1.00 kΩ | 0.300 V |
| | VOL− | 3.11 kΩ | 0.788 V |
| KEY 2 | MODE | 0 Ω | 0.000 V |
| | ON HOOK | 330 Ω | 0.105 V |
| | OFF HOOK | 1.00 kΩ | 0.300 V |
| | VOICE / PTT | 3.11 kΩ | 0.788 V |

Two facts fall out of the table and both were the reason the item was open:

- **The head unit's divider is a 10 kΩ pull-up to +3.3 V, the same topology as
  §2.4** — `V_KEY = 3.3 · R_switch / (10000 + R_switch)`, which is exactly §2.4's
  `V_pin` with the head unit's own 10 kΩ in the `R_pullup` slot. So the sense
  side and the drive side share a transfer function, and the adapter's DAC (which
  presents a *voltage*, §6.7) reproduces `V_KEY` directly.
- **The four levels per line are 0, 0.105, 0.300 and 0.788 V, and the worst-case
  separation is 0.105 V ≈ 105 mV** (SEEK+/SEEK−). That is comfortably inside the
  ADC's ~43 mV error (§FR-2) but it is the reason `mv_tolerance` is derived from
  the *measured* gap rather than a fixed width (§3.4): a 105 mV gap at the bottom
  of the range, where §2.4's consequence 2 says sensitivity is *highest*, is the
  easy case; the adapter's own ladder (measured at bring-up) is the one that can
  be tight. Both ladders' worst gaps are now bounded, so the "are the buttons
  resolvable" question has an answer for the head unit and a measurement for the
  adapter.

### 2.5 Power, feedback, and the one user-visible button

- **12 V is optional.** `J1` → `F1` PPTC → `D1` SMBJ18A TVS → `U1` XL1509-5.0
  buck; USB VBUS → `F2` PPTC → `D3`. `D2`/`D3` diode-OR at +5 V, then `U2`
  AMS1117-3.3. Either source alone is sufficient. `/VBUS_VALID` (IO10) tells the
  firmware which one is present.
- **Feedback is a buzzer and two LEDs.** `BZ1` is a magnetic buzzer on +5 V
  switched by `Q3` from `/BUZZ` — **a plain on/off drive, not a PWM tone
  generator.** Its frequency is fixed by the part; the firmware can only gate it.
  This is a real change from the 2022 design, which drove a PWM melody (§6.5).
- **`SW1` (BOOT, IO0) and `SW2` (RESET, EN) are recessed** and are
  "poke with a tool" controls, not thumb buttons — see the enclosure spec §5.6.
  RESET is wired to the chip's EN pin, **not to a GPIO**: the firmware cannot
  read it, and reset causes a full reboot. BOOT *is* readable, but because it is
  recessed and a strapping pin it is reserved for recovery, not user gestures —
  the user-facing physical input is **AUX1** (§2.2, §7.5).

  **The recessed BOOT pin is a *recovery* path, not the ONLY way into the ROM
  download loader** (corrected 2026-09-24, N-80). An earlier revision stated
  that entering the loader was a power-on/BOOT-pin event with no software path,
  and that was used to justify refusing `boot_target: "bootloader"` (§4.3). The
  ESP32-S3 ROM re-checks `RTC_CNTL_FORCE_DOWNLOAD_BOOT` (`RTC_CNTL_OPTION1_REG`
  bit 0) on every reset, and that bit lives in the RTC domain — it survives
  `esp_restart()` but not a power cycle. So the firmware can *request* the loader
  (`IHAL::reboot_to_download`), which is what makes the device flashable over its
  own USB cable without opening the enclosure. BOOT remains the way in for a
  blank board or firmware that predates this feature, which is the honest
  bootstrap boundary `tools/dev_flash.sh` reports rather than hides.

#### 2.5.1 The MCP4728 write frame, and why `~LDAC` is never pulsed

The DAC is driven by the **Multi-Write command** (DS22187E §5.6.2, Figure 5-8),
chosen because its single channel-select field addresses exactly one output per
transaction and, with `UDAC = 0`, that output updates on the transaction's final
ACK — **no `~LDAC` pulse is required.** The frame is **three bytes**:

| Byte | Bits | Meaning |
| --- | --- | --- |
| 0 | `0 1 0 0 0 DAC1 DAC0 UDAC` | command type `C2:C1:C0 = 010`, channel select, `UDAC` |
| 1 | `VREF PD1 PD0 Gx D11 D10 D9 D8` | reference, **power-down** (`PD1:PD0`), gain, code high nibble |
| 2 | `D7 … D0` | code low byte |

`VREF = 0` (VDD reference) and `Gx = 0` (×1) always; the gain mode lives entirely
in `PD1:PD0`, per §2.3. The bytes are built by `DacFrame::EncodeSet`
(`lib/HAL/DacFrame.h`) rather than inline in `EspHal.cpp`, **because `EspHal` is
the one `lib/` file the host build excludes** — a byte layout written inside it
is checked by no test. An earlier revision made exactly that mistake and emitted
a **four-byte** frame (an MCP4725-shaped one, command in its own byte, `PD1:PD0`
at bits 5:4), so on the wire the device read the channel-select byte as the
command byte and never addressed channels B/C/D: **no output was ever written.**
Found 2026-09-22; the host `DacFrameTest` now pins every byte to Figure 5-8.

**`~LDAC` (IO48) is therefore never asserted by the firmware.** It is configured
as an output and held HIGH at boot (so the `R13` 10 kΩ pulldown cannot latch at
an arbitrary time during start-up), and the `dac_ldac` HAL member exists for the
deferred-latch path — but with `UDAC = 0` on every write, each output latches on
its own ACK and no pulse is needed. `~LDAC` additionally has a *required*
High→Low transition mid-frame to programme the I²C address bits (§5.6.7), which
this design does not do: the address is the strap default `0x60` (§12.1, N-4).
Deferring the latch to a shared `~LDAC` pulse is explicitly rejected in §2.3
consequence 1 — it would apply both channels' new values at one instant and
destroy the intermediate state the servo depends on.

---

## 3. The data model

This is the **initial layout of the entities**, and it is the contract between
all three components. The firmware persists it in NVS, the Android app edits it
and sends it over USB, and the web page only ever touches the small subset in
§3.6. Every field is defined once, here.

### 3.1 Entity map

```
Config ──┬── schema_version, device_id, updated_at_ms
         ├── DeviceSettings          (timings, gain policy, feedback levels)
         ├── Channel ×2              (SWC1, SWC2)   ── per-channel ladder + output
         │     ├── Ladder                            ── learned per-vehicle
         │     │     └── LadderButton ×N
         │     └── OutputProfile
         ├── AuxButton ×3            (AUX1–AUX3, direct digital/analog inputs)
         └── Binding ×N              ── (input, gesture) → [Action…]
                                       └── Action ×N
```

`Binding` is the join table that makes the product work: it maps *what the user
did with their thumb* to *what should happen*. Everything else is either
calibration data or presentation.

### 3.2 Identifiers and value types

Getting these right up front prevents a class of silent bugs where an ADC
count is mistaken for a millivolt or a resistance.

| Type | Range | Meaning |
| --- | --- | --- |
| `AdcRaw` | u16, 0–4095 | Raw **12-bit** ADC count as read from the S3 at 12 dB atten |
| `MilliVolt` | u16, 0–2900 | Pin voltage in mV, after calibration, **at the pin** |
| `MilliOhm` | u32 | Ladder resistance in mΩ. Not inferred unless learned — see §3.4 |
| `DacCode` | u16, 0–4095 | MCP4728 code. `mV ≈ code × 3300 / 4095` (1 LSB = 806 µV) |
| `TimestampMs` | u32 monotonic | Milliseconds since boot |

**Rule:** the firmware stores ladder calibration as `MilliVolt` at the pin, and
**never** as a resistance, because the board does not measure resistance — it
measures a divided voltage (§6.3), and the ladder's own values are vehicle-
specific and unknown until learned. `MilliOhm` is display-only, computed for the
app's benefit **if and when** the user supplies the ladder's reference voltage.
Storing a resistance as if it were measured would be a lie.

### 3.3 Gestures

```jsonc
"gesture": "SINGLE" | "DOUBLE" | "TRIPLE" | "LONG" | "LONG_REPEAT"
```

`SINGLE`, `DOUBLE`, `LONG` are required and are what the user asked for.
`TRIPLE` and `LONG_REPEAT` are defined in the enum from day one so the schema
does not need a migration when they are implemented; the plan implements
`SINGLE`/`DOUBLE`/`LONG` first and adds the rest behind a capability flag.

A `COMBO` gesture (two ladder buttons held simultaneously — e.g. VOL_UP + VOL_DN)
is **deferred to v2** and is called out in §12. The two-channel hardware makes it
possible, but it interacts badly with the per-channel state machines and should
not be in the first cut.

### 3.4 Learned ladder

**`source` is a NUMBER, and it is a raw ADC channel index, not a name.** The
worked example below writes `"source": 0` and that is literal: both codecs
(`ConfigCodec` and the app's `ConfigJson`) encode and decode it as an integer, and
`0` is `ADC_CH_SWC1`. This paragraph exists because the example previously wrote
`"source": "LADDER_3V3"`, which **no codec accepts** — decoding that form fails
outright, so the spec's own example config was undecodable for a second,
independent reason beyond the `gain_mode` one. Nothing reads `source` at runtime
today; it is carried for round-trip fidelity and reserved for a future
source-selection feature, so a name would have been a vocabulary invented for a
consumer that does not exist.

The critical insight: **the ladder is a series chain whose common is tied to GND,
and each button shunts a different point in that chain to common, so each button
produces a distinct divider ratio against the +3V3 pull-up.** The absolute pin
voltage therefore depends on the ladder's own resistance values — which are
vehicle-specific and **not known in advance** — and secondarily on the +3V3 rail
(§6.3). Values are stored both as measured millivolts and as a **normalized
ratio**, so runtime classification does not depend on the rail or on absolute
level. See §6.3 for the topology and why an earlier revision's "divider against
the vehicle's 12 V rail" reading was wrong.

```
LadderButton {
  id           : "vol_up"          // stable slug, used by bindings
  name         : "Volume Up"        // display only
  mv_center    : 1240               // MilliVolt at the pin when this button is held
  mv_tolerance : 120                // half-width of the accept window
  learned_at_rail_mv : 3300         // +3V3 rail measured during learn (§6.3)
  temp_c_at_learn    : 23.5         // for the NTC compensation model
  sample_count : 200                // how many samples were averaged
  confidence   : 0.98               // learn-quality score, 0–1
}
```

`mv_tolerance` is **derived at learn time** as the midpoint of the gap to the
nearest neighbouring button, capped by a configurable maximum. A hand-derived
tolerance is the classic cause of "two buttons both trigger the same action".

**`Channel.enabled` gates only whether this channel's learned ladder is
CLASSIFIED, and it defaults to `true`.** It is not a binding gate, and it is not
an opt-in for the output. The distinction matters because the two gates are easy
to confuse:

- `Binding.enabled = false` (§3.5) means "this binding does not match at all", so
  a lower-priority source may claim the gesture. That check belongs to the
  binding and lives in `BindingResolve`.
- `Channel.enabled = false` means "this channel has no learned ladder to compare
  against — do not try to classify its input". The default config's channels are
  named and plausibly idle-referenced but have `count = 0`, which is precisely
  that state. Because `channel_count` (§3.8) decides how many channels are
  SERVICED at all, `enabled = false` is not the way to express "this input is
  absent" — omitting the channel from `channel_count` is.

Gating the binding resolve on `Channel.enabled` instead is a defect with a silent
and severe symptom, and it was live in this firmware until 2026-09-21. A config
written by `ConfigDefault` — which is what a fresh device replies to `config_get`,
and what a headless learn is applied to — has every channel disabled. The
resolver then returned "not found" for EVERY binding, so `SystemOrchestrator`
took §6.6 rule 4's unbound branch and presented the button's own default slot level
as though no gesture had ever been bound. A user who had bound `vol_up SINGLE → 2400
mV` got the default gesture level for that button instead: **a different key
voltage, with `KEY_ACCEPTED` feedback, and nothing anywhere reporting a problem.**
It never surfaced as "no output", which is what made it invisible — the device
looked like it was working.

### 3.5 Bindings and actions

A binding is `(channel, button, gesture)` → ordered list of actions. Most will
have exactly one action; the list exists because "emit the factory key press
**and** tell the app" is a real, wanted combination.

```jsonc
{
  "id": "b1",
  "channel": "SWC1",              // SWC1 | SWC2 | AUX1 | AUX2 | AUX3 | ANY
  "button": "vol_up",             // LadderButton.id, or "NONE" for gestures on the programming button
  "gesture": "SINGLE",
  "enabled": true,
  "actions": [ /* Action[] — executed in order, each independently failable */ ]
}
```

Two rules that matter:

- **A binding with an empty `actions` list is not the same as `enabled: false`.**
  Empty means "swallow this gesture" (recognised, does nothing). Disabled means
  "do not match this gesture at all", so a lower-priority binding may.
- **Action execution is best-effort and ordered.** If action 1 fails, action 2
  still runs (unless action 1 is a `MACRO` with `abort_on_failure: true`). A
  failed app-side action must never prevent the hardware key press.
- **Resolution takes the FIRST match, and a binding's POSITION is therefore its
  precedence.** `BindingResolve` scans the top-level `bindings` array in order and
  returns on the first binding whose `enabled`/`channel`/`button`/`gesture` all
  match; a later binding for the same triple is never reached. This matters most
  for the `ANY` wildcard, which matches from either channel: an `ANY` binding that
  sits ahead of a channel-specific one for the same `(button, gesture)` wins on
  BOTH channels, and the specific binding is dead. **The app's dispatch must
  mirror this exactly** — it runs the app-side actions of the binding the device
  resolved, not of every binding that matches, or it fires more than the device
  did (two launches for one press). A writer that appends a specific binding must
  therefore place it *ahead* of any surviving `ANY` binding for the same triple,
  or the edit saves, is reported as applied, and does nothing.

### 3.6 The action library

This is the union of "what the head unit's own SWC input can do" (the `OUT_`
family) and "the extra functions the Android app provides" (everything else) —
which is precisely the split the user described.

| `kind` | Params | Executed by | Purpose |
| --- | --- | --- | --- |
| `NONE` | — | — | Explicit no-op; useful as a placeholder |
| `OUT_VOLTAGE` | `key_mv` | Firmware | **The core function.** Drive the KEY line to a voltage the head unit reads as a key |
| `OUT_RELEASE` | — | Firmware | Force the KEY line to idle/high-Z |
| `APP_LAUNCH` | `package` | Android | Launch an app by package name |
| `APP_INTENT` | `action`, `data` | Android | Send an arbitrary intent, **including a data payload** — the user's stated example |
| `KEYCODE` | `keycode` | Android | Inject a key event (`KEYCODE_MEDIA_NEXT`, …). The media/volume keys dispatch unprivileged; others need `INJECT_EVENTS` (privileged, N-6) |
| `MEDIA` | `command` (`play`/`pause`/`next`/`prev`/`stop`) | Android | Media transport via `MediaSession<｜｜begin▁of▁sentence｜｜>`-style dispatch |
| `VOLUME` | `target` (`media`/`call`/`ring`/`alarm`) | Android | Volume, a relative step per named stream (`AudioManager.adjustStreamVolume`); an absolute set needs a second param the two-string budget does not carry |
| `SYSTEM` | `command` (`screen_off`/`night_mode`/`screenshot`/`open_settings`) | Android | Head-unit housekeeping |
| `BUZZ` | `pattern` (named, §7.2 spelling — enumerator name without the `k`) | Firmware | Local audible confirmation. **Replaces the default `KEY_ACCEPTED`**, because there is one buzzer and `Play` replaces rather than queues; a pattern name this build does not know falls back to `KEY_ACCEPTED` rather than leaving the press silent |
| `APP_RAW` | `command` | Android | Escape hatch: an app-defined command not yet promoted to a kind |

**Every action carries at most two string params, and that is a budget
constraint rather than a design preference.** An earlier revision of this table
gave `APP_INTENT` five (`action`, `data`, `mime`, `extras{}`, `flags[]`),
`KEYCODE` two, `VOLUME` two and `APP_RAW` two. None of those extra params had a
field in the shared `Action` entity, so a config carrying one could not be
stored or transmitted — `ConfigValidate` refuses it, which is the safe direction
but leaves the table describing actions the product cannot express. Closing that
gap from the other side does not work either: the worst-case `Config` already
occupies **96 % of the `nvs` partition** (the measurement below), and a per-action
params field costs a 12th NVS chunk at *any* width, because chunking is coarse —
even `params[32]` pushes two slots past the partition, and clawing it back means
cutting `kMaxBindings` from 32 to about 18. Two string params per action is what
the partition buys at this cardinality.

So the rule is: **`target` and `payload` are the action's two string slots, and
each kind names them on the wire** — `APP_INTENT`'s `action`/`data`,
`APP_LAUNCH`'s `package`, `KEYCODE`'s `keycode`, `MEDIA`/`SYSTEM`/`APP_RAW`'s
`command`, `VOLUME`'s `target`, `BUZZ`'s `pattern`. The wire key is the kind's own
name for the parameter (§3.7 is written in those names); the struct field is the
generic one. `OUT_VOLTAGE` is the exception that uses the numeric field instead.
A kind needing more than two strings is a v2 item with its own `schema_version`,
not a v1 action.

**Why the output kind is `OUT_VOLTAGE` and not `HW_KEY`.** An earlier revision
called this kind `HW_KEY` and gave it `key_resistance_mohm` or `dac_code`. Both
names were wrong, and for the same reason: **the firmware does not drive a key,
it drives a voltage.** The output stage is a closed-loop integrator servo
(§2.3) — `V_KEY = 1.82·V_DAC − 0.82·V_ADJ` — and what it controls is the voltage
on the KEY line. "Which key" is the *head unit's* interpretation of that voltage,
and it differs per head unit: the same `volume up` is a different voltage in every
car. An action that named a key would be promising an identity the firmware cannot
know, so the action names the voltage and the head unit supplies the meaning.
`dac_code` was wrong for a second, independent reason: a code is coupled to the
gain mode, so changing `gain_mode` would silently change what every stored code
means — the same "two homes for one level" defect that removed
`output.key_values` below. `key_mv` is mode-independent.

The `OUT_` prefix marks the *output* side of the device, which is the distinction
that matters here: `OUT_VOLTAGE`/`OUT_RELEASE` act on the KEY output, while the
ladder buttons and gestures act on the input side and `BUZZ` drives a different
output entirely.

**Resistance is the app's vocabulary, not the firmware's.** The head-unit profile
— its ladder's resistances, its pull-up, its idle level — lives in the Android
app, which is where a per-head-unit model belongs and where it is set up once for
the user's car. The app converts a resistance to the voltage it produces and sends
`key_mv`. The firmware never needs a head-unit constant, which is what keeps
§6.5's "unknown pull-up" from being a firmware input at all. (`test_key`'s
bench/production frame carries the same `key_mv` for the same reason.)

`MACRO` is **not** an action kind — it is a binding with an ordered `actions`
list, which is the same thing with one fewer concept to learn.

**Design note on `OUT_VOLTAGE` vs `APP_INTENT`:** a single physical button can be
bound so that `SINGLE` sends an `OUT_VOLTAGE` (so the stock head unit reacts even
if the app is not running) while `DOUBLE` sends an `APP_INTENT` (an extra function
the head unit never had). That is the whole point of the product, and the data
model expresses it without a special case.

**An action has no id.** It is identified by its `kind` (the 11 above) plus its
params. An earlier revision of the plan invented a numeric action-id table
(`1–63`) and treated ladder-button slugs (`VOL_UP`) as action *names*; the spec
defines neither, and a generated contract must not synthesize them. `VOL_UP` is
a `LadderButton.id`, used in a binding's `button` field — never an action name.

**The output level lives in the action, and there is no per-button key table.**
An earlier revision of §3.7's worked example carried an
`output.key_values: { vol_up: { dac_code: 1240 }, … }` map alongside the
bindings. That is a second home for the level: §3.6's `OUT_VOLTAGE` row already
says an action carries `key_mv`, and §3.5's whole design is
that a binding's own `actions` list is what decides what happens — including the
core case where `vol_up`'s `SINGLE` sends an `OUT_VOLTAGE` while its `LONG` sends
something else entirely. A per-button default map cannot express that, and two
places to look for one level is how they drift. The map is removed; a binding's
`OUT_VOLTAGE` action names its own level. This is also a budget fact rather than a
taste one: 32 buttons × a `{dac_code}` entry is 576 B, which takes the measured
worst case from 22,407 B to 22,983 B → **12 chunks → 50,720 B = 105 % of the
partition** — the map does not fit.

**Cardinality (v1), fixed by the NVS budget rather than by preference:**

| Limit | Value | Why |
| --- | --- | --- |
| Bindings, total | **32** | They are a top-level table, not per-channel; 32 covers 2 channels × several gestures × the AUX inputs |
| Actions per binding | **2** | Both bounds come from the partition — see below |
| Ladder buttons per channel | 16 | Fits `LadderProfile`'s fixed array |
| AUX buttons | 3 | AUX1–AUX3 |

**String field widths are also a budget input, not a preference.** A provable
staging bound has to cover every field at its declared maximum, so the widths
below are load-bearing — widening any of them re-opens the partition arithmetic:

| Field | Width | Holds |
| --- | --- | --- |
| `Action.target` | **40** | `com.oetsolutions.swc.ACTION_NAVIGATE` (34); a longer intent action must be refused by validation, not truncated |
| `Action.payload` | **48** | `geo:40.7608,-111.8910?q=Home` (28); a full street address does **not** fit and is refused |
| `Binding.id`, `LadderButton.id`, `Binding.button` | **16** | Slugs, e.g. `vol_up`, `next` |
| `ChannelConfig.name`, `LadderButton.name` | **16** | Display labels |

**Integer fields carry integers.** Every field the model declares as an integer
is refused by the codec if it arrives with a fractional part — not truncated.
Truncation is the same wrong-value-accepted class as a wrap: `long_press_ms`
sent as `750.9` would otherwise be stored as `750`, a config the device accepts
and then behaves differently from what was sent. The bound is applied before the
cast (magnitude for `uint32_t`/`uint64_t`, `0`–`3` for the levels via
`ConfigValidate`), and `config_patch` (§4.3) applies the identical rule so the
two writers of a config give one answer to "what is a legal value".

**The bounded timing scalars are bounded in RANGE, not only in width.**
`debounce_ms` and `send_duration_ms` refuse zero; the gesture timings are ordered
against each other; `send_duration_ms` and `maintenance_timeout_ms` each refuse
anything above their ceiling (`kSendDurationMaxMs`, 10 s; `kMaintenanceTimeoutMaxMs`,
1 hour, `ConfigValidate`). The magnitude check alone is not a range check, and both
ceilings guard a hazard the `uint32` maximum (~49.7 days) would create: a
`send_duration_ms` that large is the KEY line DRIVEN for a phantom press the user
cannot release (FR-15/FR-39), and a `maintenance_timeout_ms` that large is "never
closes" — the device-left-unable-to-serve state FR-38 exists to prevent. The lower
end matters too for `maintenance_timeout_ms`: a zero makes the close test
(`now - last_activity >= timeout`) true on the tick the window opens, so
maintenance appears to work and instantly closes. None is a value a user can mean,
so each is refused rather than clamped, the same answer `debounce_ms` gives.

**Measured (§3.8's method), and re-measured 2026-09-19 after a defect:** the
structural worst case is every string field at its width above, 2 channels × 16
buttons, 3 AUX, and 32 bindings × 2 actions. That is **22,407 B** as JSON →
**11 chunks**; two slots plus `cfg_seq` cost **46,496 B of the partition's 48,384
B usable bytes (96 %)**.

**An earlier revision of this paragraph quoted the same 11 chunks / 46,496 B /
96 % for a configuration it did not measure.** It said 32 bindings × 2 actions
while the figure is only reproducible at **one** action per binding (20,741 B →
11 chunks). At 2 actions with the *unbounded* widths that revision also declared
(`target[64] payload[128] name[24]`), the same arithmetic gives **30,021 B → 15
chunks → 63,392 B = 131 % — an overflow, not a fit.** Two numbers in one
paragraph describing two different data models, which is why a rewrite that
swept for contradictions *between* documents did not catch it. The widths table
above is what makes the two agree: at 40/48/16/16 the figure is real.

The step up is now measured too: 3 actions per binding at these widths needs
**14 chunks = 59,168 B = 122 %** and does not fit. So 2 is not a round number
chosen for comfort; it is the largest value the existing partition stores with
both slots present, and the string widths are what buy it. Enlarging NVS would
cost app-slot space and re-open the §9.2 partition layout — and note the 48 KB is
not the config's alone: §9.2 records that WiFi provisioning credentials live in
the same `nvs` partition, so the two-slot budget above is an upper bound on what
the config can ever have.

### 3.7 Full worked example

The user's stated scenario — "the head unit may not have a SWC to open a specific
app or a specific intent with data payload, but the Android app can" — written
out:

```jsonc
{
  "schema_version": 1,
  "device_id": "swc-a1b2c3",
  "updated_at_ms": 1700000000000,
  "settings": {
    "debounce_ms": 25,
    "double_press_off_ms": 500,
    "long_press_ms": 750,
    "send_duration_ms": 200,
    "gain_policy": "AUTO",
    "buzzer_level": 2,
    "led_level": 2,
    "temp_comp_enabled": true,
    "maintenance_timeout_ms": 300000
  },
  "aux": [
    { "id": "aux1", "source": 1, "mv_center": 100, "mv_tolerance": 1600 }
  ],
  "channels": [
    {
      "name": "SWC1",
      "enabled": true,
      "ladder": {
        "source": 0,
        "idle_mv": 2835,
        "buttons": [
          { "id": "vol_up", "name": "Volume Up", "mv_center": 1430, "mv_tolerance": 120,
            "learned_at_rail_mv": 3300, "temp_c_at_learn": 23.5, "sample_count": 200, "confidence": 0.98 },
          { "id": "vol_dn", "name": "Volume Down", "mv_center": 1785, "mv_tolerance": 120,
            "learned_at_rail_mv": 3300, "temp_c_at_learn": 23.5, "sample_count": 200, "confidence": 0.97 },
          { "id": "next", "name": "Next Track", "mv_center": 2145, "mv_tolerance": 110,
            "learned_at_rail_mv": 3300, "temp_c_at_learn": 23.5, "sample_count": 200, "confidence": 0.99 }
        ]
      },
      "output": {
        "gain_mode": "AUTO",
        "idle_dac_code": 4095
      }
    }
  ],
  "bindings": [
    { "id": "b1", "channel": "SWC1", "button": "vol_up", "gesture": "SINGLE",
      "enabled": true, "actions": [ { "kind": "OUT_VOLTAGE", "key_mv": 2400 } ] },

    { "id": "b2", "channel": "SWC1", "button": "vol_up", "gesture": "LONG",
      "enabled": true, "actions": [ { "kind": "OUT_RELEASE" } ] },

    { "id": "b3", "channel": "SWC1", "button": "next", "gesture": "DOUBLE",
      "enabled": true, "actions": [ { "kind": "APP_LAUNCH", "package": "com.spotify.music" } ] },

    { "id": "b4", "channel": "SWC1", "button": "next", "gesture": "LONG",
      "enabled": true, "actions": [
        { "kind": "APP_INTENT",
          "action": "com.oetsolutions.swc.ACTION_NAVIGATE",
          "data": "geo:40.7608,-111.8910?q=Home" }
      ] }
  ]
}
```

**This example is decoder-verified, and it was not before.** `tools/check_spec_example.py`
decodes it with the firmware's own decoder as part of CI. An earlier revision of
this block described a config **no codec would accept**, in six independent ways:
settings were nested under a `device` object the codec has no field for (spec
§3.1's entity map has no such node); five settings names (`single_press_ms`,
`double_press_gap_ms`, `long_repeat_ms`, `release_margin_mv`,
`usb_protocol_version`) appear nowhere in the code; the feedback levels were
written `"NORMAL"` where the codec's enum is numeric; `updated_at_ms` was missing
and is required (`aux` was missing too, but that one is optional — checked, since
the difference matters to anyone reading this as a template); the channel was
keyed `id` where the codec writes `name`; and `b4` still carried `extras`/`flags`,
which §3.6 had already removed as over-budget. The example is the spec's most concrete assertion about
the wire, so a stale one is worse than none: it is what a reader copies.

### 3.8 Persistence, versioning and migration

- **Storage:** NVS, namespace `swc_cfg`. The `Config` is stored as a single JSON
  blob **per slot**, with **two slot keys** (`cfg_a`, `cfg_b`) plus a small
  sequence key (`cfg_seq`) — see the A/B rule below. A partial config is worse
  than no config, which is why each slot is written and verified whole rather
  than field-by-field.
- **Blob size is a measured quantity, not an assumption.** An NVS value has a
  per-entry ceiling. The full `Config` is expected to be several KB and **may
  exceed one NVS value.** The measured serialized size therefore selects the
  strategy, and the firmware must not assume either way:
  - if a slot fits one value → one blob per slot, as above;
  - if it does not → the slot's blob is **chunked across a small fixed number of
    NVS keys** (`cfg_a_0`, `cfg_a_1`, …) with the chunk count and a per-slot CRC
    in a header chunk, so a slot is still read and validated as a unit.

  This is the one place where "measure, then decide" is mandatory rather than
  preferred, because the answer changes the persistence code.
  **Measured, 2026-09-18; re-measured 2026-09-19 — the answer is "it does not
  fit, so a slot is chunked."** On IDF 5.5.5 the ceiling is `ENTRY_SIZE ×
  (ENTRY_COUNT − 1)` = 32 × 125 = **4000 bytes** (`nvs_page.cpp` returns
  `ESP_ERR_NVS_VALUE_TOO_LONG` above it), and the worst-case `Config` — §3.5's
  cardinality (32 top-level bindings × 2 actions, 2 channels × 16 buttons, 3 AUX)
  at §3.5's string widths — is **~21.9 KB** as JSON. **Even a realistic config
  (~3.9 KB) sits on that ceiling and a moderate one (~7.9 KB) exceeds it**, so a
  single-value slot fails on the common case, not a hypothetical one; the chunked
  branch above is the one that ships. Chunk size is a fixed 2048 B and the count
  is bounded (**11 worst case**). Two worst-case slots cost **96 % of the
  partition's usable entry space** (46,496 B of 48,384 B), so it fits, but with
  almost no margin — which is why §3.5's action-per-binding cap is 2 **and** why
  §3.5 fixes the string widths. Each 2048-byte chunk is one NVS *key*, and NVS
  charges **2112 B** for it — a 32-byte metadata entry, the 2048 payload bytes,
  and a 32-byte `BLOB_IDX` entry written once per key (`nvs_storage.cpp:353`; the
  `writeItem` span at `nvs_page.cpp:185` covers only the first two). An earlier
  revision of this figure counted 2080 B and so understated the two-slot cost by
  576 B. This is recorded here because a "measure, then decide" rule with no
  recorded measurement is an assumption with extra steps.

  **Two earlier revisions of this paragraph were wrong in the same way,** and the
  correction is recorded rather than quietly applied. The first said "32
  bindings" while computing from a *per-channel* binding model (2 × 32 = 64
  bindings, ~17.8 KB). The second quoted **21,411 B → 11 chunks → 96 %** as the
  worst case at 32 bindings × 2 actions — but that figure is only reproducible at
  **one** action per binding. At 2 actions with the widths that revision declared
  (`target[64] payload[128] name[24]`) the same arithmetic gives **30,021 B → 15
  chunks → 131 %**, an overflow. The measurement and the cardinality table
  described different configurations *in the same paragraph*. §3.5's width table
  is the fix, and the figure above is now the one that table produces.
- **The HAL's NVS return contract is fixed and stated once (IHAL.h).**
  `nvs_set` returns **0 on success, nonzero on failure**; `nvs_get` returns the
  **byte count on success, -1 when the key is absent or the caller's buffer is
  too small**. This is the one part of `IHAL` `EspHal` and `MockHal` must agree on
  exactly, because `EspHal` is the only `lib/` file the host build excludes — no
  native test compiles it, so a divergence is invisible until it runs on
  hardware. It had diverged in **two** places at once: `HalNvsSet` returned the
  byte count where every caller tests `!= 0` (so **every device save looked like a
  failure** — a config or a headless learn could never persist), and `HalNvsGet`
  read a 2048-byte chunk through a 16-byte buffer (see the read-width rule above).
  `tools/check_hal_contracts.py` pins both shapes statically, and
  `test/test_hw/TestEspHal.c` asserts the same contract on real silicon.
- **A chunk is read back at FULL CHUNK WIDTH, never at the header's width.**
  `nvs_get_blob` does **not** truncate: when the caller's buffer is smaller than
  the stored value it returns `ESP_ERR_NVS_INVALID_LENGTH` (and *sets the length
  out-param to the real size*), which is **not** `ESP_ERR_NVS_NOT_FOUND`, so the
  HAL's "absent → -1" mapping turns it into a plain read failure. Reading chunk 0
  into a 16-byte header buffer is therefore a read failure for **every** config,
  not just large ones — `ReadSlot` must read chunk 0 into the full slot buffer
  (the caller's buffer is already sized to the whole blob, so no per-call chunk
  buffer is needed on the device's small stack) and then take the header from it.
  This defect class is invisible to the native suite unless the mock reproduces
  IDF's strictness: a truncating mock makes the same code pass on the host and
  fail on the device. `MockHal::NvsGet` therefore mirrors `nvs_get_blob` — a
  stored value larger than the caller's buffer is an error.
- **Dual-slot writes with a monotonic sequence number.** NVS is written **A/B**:
  write the inactive slot, verify it by read-back, bump the sequence, *then* flip
  the active marker. **A power loss mid-write must never destroy a working
  config** — this is not theoretical, because the device lives on a car's
  electrical system and can lose power at any instant, including during a save.
  The reader always takes the higher valid sequence number.
- **A CRC covers the blob.** A corrupt config must be *detected* and replaced
  with known-good defaults, never partially applied — a half-applied mapping is a
  car control that does the wrong thing.
- **Staged, then committed.** A learn run or a bulk edit writes to a staging area
  and commits only after read-back verification. Any failure keeps the previous
  table.
- **`schema_version` is mandatory and checked on read.** A config written by a
  newer firmware is **not** silently interpreted by an older one; it is rejected
  and defaults are used, with a loud log and a buzzer pattern. **The NVS is not
  overwritten until the user confirms**, so a bad flash remains recoverable.
- **Migration is forward-only and additive.** Each version bump needs a
  `migrate_vN_to_vN+1` function. Removing a field requires bumping
  `schema_version` and *keeping* the reader for the old one for at least one
  release.
- **Defaults are always valid.** With no config at all, the device must still
  pass the ladder through to the output 1:1 (§6.9). Out of the box, before any
  configuration, the adapter behaves as a transparent pass-through.
- **Also persisted:** a small learn log (the last few learn runs' raw medians,
  for drift diagnosis) and a boot counter. Nothing else — every extra persisted
  key is another migration to carry.

---

## 4. The USB link

The USB-C port is the only connector. It is simultaneously the power source, the
bench flashing/debug path, and the command link to the head-unit app. **One
transport, three jobs** — the design must not let the debug job corrupt the link
job, or vice versa.

### 4.1 Transport choice

The ESP32-S3 has **two** independent USB peripherals, and this is the design
decision that unlocks the whole thing:

| Peripheral | Use here | Why |
| --- | --- | --- |
| **USB-Serial-JTAG** (ROM) | **Console + JTAG debug only**, and bench flashing | Built into ROM; always enumerates, even with a dead app. Never carries the app protocol. |
| **TinyUSB CDC** (OTG) | **The Android command link** | Application-controlled, independent of the console. |

**Both may NOT be active at once on this board — only ONE internal PHY exists.**
Espressif's own documentation is unambiguous: for the ESP32-S3, "both controllers
share a single internal PHY, allowing only one to operate at a time", and "by
adding an external PHY, it is possible to enable the simultaneous operation of
both USB-OTG and USB-Serial-JTAG" (ESP-IoT-Solution, *USB PHY/Transceiver
Introduction*; ESP-IDF *USB Host* — both verified 2026-09-20). This board has **no
external PHY**, so **the two are mutually exclusive.**

**What the ESP-IDF documentation says must be read exactly, because it is
counter-intuitive and it decides the design:** "If there is a need to develop a
USB-OTG application using the USB Host Driver or the TinyUSB protocol stack,
**during protocol stack initialization, the USB-PHY connection will
automatically switch to USB-OTG**" (same source). So calling `tinyusb_driver_install`
— which `UsbLinkStart` does unconditionally at boot — **takes the PHY away from
USB-Serial-JTAG.** The consequences follow, and both are now answered (N-16):

- **A console left on USB-Serial-JTAG is gone at runtime** — the `ESP_LOG*` output
  the firmware is full of goes nowhere, including `UsbLinkStart`'s own "tinyusb
  driver install failed", the message that reports the link failing. **This is why
  the console PRIMARY is UART0, not Serial-JTAG** (`CONFIG_ESP_CONSOLE_UART_DEFAULT=y`);
  UART0 is off the USB PHY, so it survives TinyUSB taking it, and the fabricated
  board already pads it out (TP7/TP8).
- **ROM download mode stops using USB-Serial-JTAG.** Espressif: "In USB-OTG mode,
  if users wish to utilize the download functionality of USB-Serial-JTAG, they need
  to manually boot into download mode." **RESOLVED (N-80, 2026-09-24): a reset DOES
  enter the ROM USB download loader without a BOOT press**, via
  `IHAL::reboot_to_download` (sets `RTC_CNTL_FORCE_DOWNLOAD_BOOT`, survives a
  software reset but not a power cycle); the loader enumerates as `303A:0009` after a
  USB bus reset, and `tools/dev_flash.sh` flashes the sealed device end to end. The
  original "reflash by unplugging and replugging vs. opening the enclosure to hold
  BOOT" question is settled in favour of the software route; the eFuse route
  (`USB_PHY_SEL`) is still one-way and must not be burned to find out.

**The requirement the design actually keeps is the important one**, and it holds
regardless: the app protocol must never share a CDC interface with debug output, so
a stray `printf` can never be parsed as a protocol frame. Today that is satisfied by
`CONFIG_ESP_CONSOLE_UART_DEFAULT=y` — the console PRIMARY is **UART0**, which is not
on the USB PHY at all, so it survives TinyUSB taking the PHY.
**RESOLVED 2026-09-25 (N-16): the console is no longer dark, and it needed no
respin.** An earlier revision kept the primary on `CONFIG_ESP_CONSOLE_USB_SERIAL_JTAG`
and stated the observable console "needs header pins or test pads on a respin" —
**both halves were wrong for this board**. The S3 has one internal USB PHY shared by
USB-Serial-JTAG and USB-OTG, so `UsbLinkStart` installing TinyUSB moves the PHY to
USB-OTG and a Serial-JTAG console goes dark (that part stands, and is why the primary
must move); but the fabricated board **already breaks UART0 out to test pads TP7
(`/TXD0`)/TP8 (`/RXD0`)** — bare THT pads with nothing else on those nets — so a
UART0 console is reachable today, with no respin. The fix is `sdkconfig.defaults`
selecting UART0 as the primary console, with `CONFIG_ESP_CONSOLE_SECONDARY_USB_SERIAL_JTAG=y`
duplicating output to the USB port (so `pio test -e esp32s3` and a serial monitor
still read the log off USB until TinyUSB installs; the durable copy lives on the
pads). Output is duplicated because `ESP_ROM_CONSOLE_OUTPUT_SECONDARY` is set on the
S3. The **external PHY** option (≥6 GPIOs) is rejected as strictly worse.

**This is a hard requirement:** the console must never be configured onto the
TinyUSB CDC port in a production build. §10 tests it — as of 2026-09-25 the on-device
assertion checks `CONFIG_ESP_CONSOLE_UART_DEFAULT` (a console independent of the USB
PHY) and forbids `CONFIG_ESP_CONSOLE_USB_CDC`, and `check_sdkconfig_keys.py` gates the
same two facts in CI so a "simplify the console" edit cannot silently reintroduce the
dark-console defect.

> **Build consequence, verified 2026-09-18 (Task 1, against IDF 5.5.5): TinyUSB
> is not part of IDF — it is the managed component `espressif/esp_tinyusb`.**
> IDF 5.5.5 ships no `components/tinyusb` and defines **no** `CONFIG_TINYUSB_*`
> symbols, so any such key in `sdkconfig.defaults` is silently inert (accepted
> with no warning, and doing nothing). The app link above is therefore **not
> real until a task adds the component** — via `idf_component.yml` or
> `lib_deps` — and configures it. Until then the console on USB-Serial-JTAG
> works and there is no app interface at all. The task that owns `UsbCdc`
> (§10.1) must add it; this note exists so that task cannot be written without
> noticing.

### 4.2 Framing

Line-oriented **NDJSON** (newline-delimited JSON) in both directions, with an
explicit envelope. Chosen over a binary/COBS format deliberately:

- It is human-readable on a bus analyzer and in a terminal, which is worth a lot
  during bring-up on hardware nobody has yet.
- The payload here is button events and config — tens of bytes, a few per
  second at the very worst, on a Full-Speed link. Framing efficiency is
  irrelevant; debuggability is not.
- JSON parsers exist on both sides already.

```
frame  := object "\n"                 ; one JSON object per line, UTF-8, no embedded newline
object := { "v":1, "seq":u32, "type":TYPE, ...payload }
```

Every frame carries:

| Field | Type | Purpose |
| --- | --- | --- |
| `v` | u8 | **Protocol version.** Mismatch is handled explicitly (§4.5) |
| `seq` | u32 | Per-sender monotonic counter, for gap detection and ack matching |
| `type` | string | What this frame is |

**Line length is capped** (recommend 1024 bytes incl. newline). An over-long
line is discarded with an error frame rather than buffered — an unbounded line
buffer on a 4 MB/no-PSRAM part is a heap-exhaustion bug that a hostile or buggy
peer can trigger.

**The cap applies to every frame, including config transfer, and that is why
config transfer is chunked.** A full `Config` is several KB (§3.8) and cannot
fit one line, so `config_get`/`config_set` carry the config as an **ordered run
of chunks**, each comfortably under the cap:

```
config_get   →  fw replies  config_begin {total_len, crc32}
                            config_chunk {offset, data_b64}   × N
                            config_end   {sha256}         (or nack on failure)

config_set   →  app sends   config_begin {total_len, crc32}
                            config_chunk {offset, data_b64}   × N
                            config_end   {sha256}
                fw replies  ack | nack {err, detail}
```

`data_b64` is **base64**, spelled the same way §9.3's `ota_chunk` spells it. A
chunk is JSON, so it cannot carry raw bytes, and the config's payload is the
*UTF-8 JSON text* of §3.7 — base64 rather than a JSON string literal because the
transport must be byte-exact and must not depend on the peer's escaping rules.
`offset` is the byte offset of this chunk's first *decoded* byte, so a gap or an
overlap is detectable rather than silently concatenated.

Each chunk is sized so the **encoded frame** — envelope, offset, and the base64
expansion of the payload — stays under the 1024-byte line cap. Base64 costs 4
bytes per 3, so the decoded chunk payload is **512 bytes**, giving a frame of
roughly 750 bytes. Sizing the chunk by the *decoded* length and then discovering
the encoded frame is too long is how a chunked transport ends up unable to send
its own chunks.

`config_get` is a real frame. **`config_set` is a logical operation, not a frame
type** — it names "replace the whole config", and it is carried entirely by the
`config_begin`/`config_chunk`/`config_end` run above. There is deliberately no
single-frame `config_set`: a real config is ~22 KB and the line cap is 1024 B, so
such a frame could never carry a legal config, and a type that exists only to be
always-rejected is a trap for the app author.

The receiving side **accumulates into a fixed-size staging buffer sized to the
maximum legal config** (a compile-time constant, so the bound is provable, not
hoped for) and rejects a `config_begin` whose `total_len` exceeds it. Nothing is
committed until `config_end` validates the CRC **and** the SHA-256, which keeps
§3.8's "staged, then committed" rule intact across the wire as well as in NVS.
An interrupted run is discarded wholesale — a partial config is never applied.
`config_patch` (single field) stays on one line, which is most of why it exists.

**A committed config takes effect immediately, with no reboot.** "Committed"
means both halves: it is *persisted* AND it is the config the running device now
classifies against. The device has exactly one config, and after a successful
`config_end` (or `config_patch`) that one is the new one — so the next press is
classified, bound and gestured against what the user just saved, not against
what was loaded at boot. Deferring to the next boot is not a permissible reading
of the above: the app adopts the config it pushed as the device's live state the
moment the `ack` arrives, so a stale running config makes the app and the device
disagree about the bindings the user is looking at, and the user sees a saved
binding do nothing until they power-cycle a device the app called configured.

The refresh is therefore part of `config_end`'s commit, not a separate
operation: the same re-derivation `Boot` does for the running config — the
classifiers, the gesture machines, the timings, the feedback levels and the
per-channel output derivation — runs again over the newly committed config before
the `ack` goes out. This is the same rule the headless learn already follows
(§7.4 commits a profile and the device uses it on the next tick). A config the
device *refused* changes nothing, running or stored: rejection leaves the
previous config intact in both places.
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

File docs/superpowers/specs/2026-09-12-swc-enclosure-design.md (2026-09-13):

# SWC Adapter Enclosure — Design Spec

**Date:** 2026-09-12
**Status:** BUILT — model in `plastic_case/`; see §9.2 for the as-built corrections
**Deliverable:** A parametric FDM-printable two-part enclosure (base + screw-on lid) for
the SWC steering-wheel-controls adapter PCB, generated with FreeCAD, sliced with OrcaSlicer.

---

## 1. Goal

House the `SWC.kicad_pcb` assembly in a rugged, printable, serviceable enclosure that:

1. exposes every user-facing interface (USB-C, 4 terminal blocks, buzzer, 2 LEDs, 2 buttons);
2. keeps the ESP32-S3 antenna **inside** the box, in adequate free space;
3. lets the board's own silkscreen do the labelling;
4. vents around RT1 so the NTC senses ambient, not internal, temperature;
5. prints without supports on the user's printer.

## 2. Confirmed inputs (verified, with provenance)

### 2.1 Live board geometry

| Item | Value | Source |
| --- | --- | --- |
| Outline | **x 16.0–70.0, y 31.0–133.0** = **54.0 × 102.0 mm** | `list_pcb_graphic_items` (Edge.Cuts) **and** the STEP substrate solid (54.000 × 102.000) — two independent confirmations |
| Corner radius | 2.0 mm | `tools/holes.py` (matches the Edge.Cuts R2.0 arcs) |
| Board thickness | 1.5162 mm (nominal 1.6) | Edge.Cuts F.Fab "Board Thickness 1.6062" table; STEP substrate 1.5162 |
| Mounting holes | 4 × Ø5.3 through, at **(22,37), (64,37), (22,127), (64,127)** | footprint list (`MountingHole_5.3mm_M5`) |
| Hole inset | **6.00 mm from both nearest edges, all four** | measured against the verified outline |
| Tallest top-side part | 15.6712 mm above board top | STEP (J2–J5 terminal bodies) |
| Deepest bottom-side part | −4.3988 mm below board top | STEP (BZ1 buzzer back can) |

> **Correction to `tools/holes.py`:** its `OUTLINE = (16.0, 31.0, 79.5, 135.5)` is **stale**
> (that is a 63.5 × 104.5 board). The live outline is 54 × 102. The hole inset arithmetic
> therefore does **not** yield 6.0 mm from that constant. Do not reuse it.
> AGENTS.md's "54.00 × 102.00" is correct. (Its "110 footprints / 804 traces / 160 vias"
> is slightly stale — live is 110 / 841 / 163.)

### 2.2 STEP export frame (calibrated)

`mcp__kicad__export_3d` writes a frame rotated 90° about X, with **y negated**:

```
STEP = ( KiCad_x , −KiCad_y , KiCad_z )
```

with **KiCad z = 0 at the board's TOP face**, +z toward the components, −z toward the
back of the board. Validated by recovering the 54 × 102 substrate exactly and by
matching 4/4 mounting-hole insets.

### 2.3 Component geometry that drives the openings (from STEP solids)

| Ref | Part | Board-frame extents (kx, ky, kz) |
| --- | --- | --- |
| U3 | ESP32-S3 module | module PCB **x 37.22–55.22, y 25.25–50.75**, z 1.60–2.60. **Overhangs the board's front edge (y=31) by 5.75 mm.** |
| U3 | antenna keepout zone | **x 38.72–53.72, y 25.25–31.25** (the part off-board) |
| J4 | USB-C receptacle (HRO TYPE-C-31-M-12) | x 15.98–23.88, **y 43.74–52.68**, z 0.75–4.85. Faces **−x (left)**; housing end-face at kx = 15.98 (just proud of the board edge, so the connector body is essentially flush with the board edge). |
| J1 | TB007-508-02, 2-pole | x 16.86–26.86, y 54.11–64.87, z −1.90…15.60. Wire bores at **y 56.566, 61.500**. Pins reach z −1.90. |
| J2 | TB007-508-03, 3-pole | x 16.86–26.86, y 65.79–71.47, z 1.60–15.60. Bores at **y 68.329, 73.409, 78.489**. Pins to z −2.90. |
| J5 | TB007-508-04, 4-pole | x 16.86–26.86, y 82.64–87.72, z 1.60–15.67. Bores at **y 85.18, 90.26, 95.34, 100.42**. Pins to z −2.22. |
| J3 | TB007-508-03, 3-pole | x 16.86–26.86, y 104.58–110.26, z 1.60–15.60. Bores at **y 107.122, 112.202, 117.282**. Pins to z −2.90. |
| BZ1 | buzzer | **True part is TMB12A05 (Ø12 × 9.5), body centred on the pad midpoint (48.082, 116.356)**, z 1.6–11.1 above the board, leads ≈ z −3.9. **The 3D model on the board is a different part — see §2.6.** |
| SW1 | BOOT tact switch | x 56.51–61.51, y 47.83–50.83, z 1.60–3.60 |
| SW2 | RESET tact switch | x 30.89–33.89, y 61.77–66.77, z 1.60–3.60 |
| D6 | LED (STATUS) | x 46.34–47.59, y 60.66–62.66, z 1.60–2.70 |
| D12 | LED (LED2) | x 40.07–42.07, y 53.87–55.12, z 1.60–2.70 |
| RT1 | NTC 10k B3380 | **(68.5, 120.0)**, z 1.60–2.05 — **2.10 mm** from the board's right edge (x=70) |

> **Terminal-block screw axis — CORRECTED during build (see §9.2).** The datasheet puts the
> screw axis **2.60 mm back from the wire-entry face**. The terminal's *effective* wire-entry
> face is the upper setback face at **x = 19.047** (the lower skirt face at 16.858 is not the
> face the datasheet measures from), so `19.047 + 2.611 = 21.658`. Two independent
> confirmations. **The screw axis is therefore x = 21.658 — the pin line at 22.358 is 0.70 mm
> too far back.** (The Ø5 driver slots are placed at x = 21.658.) Screw heads take an M3 blade
> (PH1 or a 3–4 mm flat); torque 0.5 N·m.
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

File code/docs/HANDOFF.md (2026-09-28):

# SWC firmware + Android app — session handoff

> **STATUS — everything is committed and CI is GREEN.** The working tree is
> clean; `main` and `feat/swc-firmware-android-app` are at the same commit on the
> private `OETSolutions/swc-module` remote, and both workflows
> (`.github/workflows/{firmware,android}.yml`) pass on both branches — every job
> and every step `success`, nothing skipped.
>
> **History note (2026-09-25):** the git history was rewritten (`git filter-repo`)
> to strip personal identifiers, so **older commit SHAs quoted anywhere in the
> docs and memory are dead** — the tree content is unchanged (verified
> byte-identical per tip), only the hashes differ. Do not go looking for a hash
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

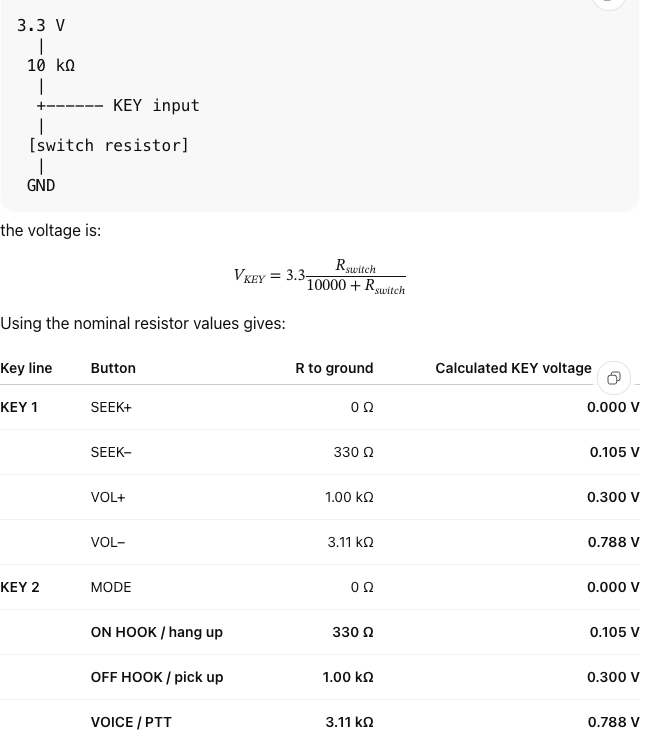
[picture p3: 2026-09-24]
Likely Tundra Steering Wheel Switch Resistor Values.png

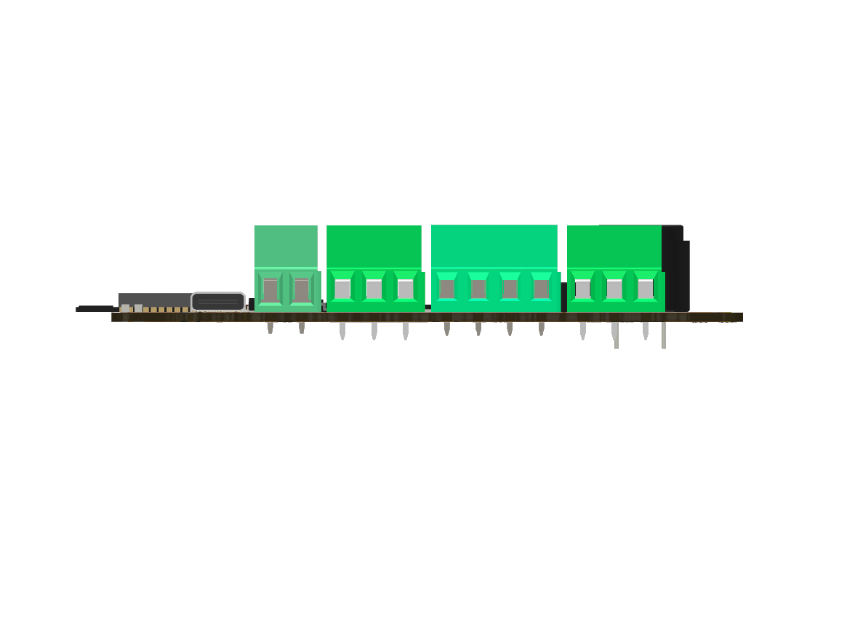
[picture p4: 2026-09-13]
plastic_case/SWC-3d-left.png

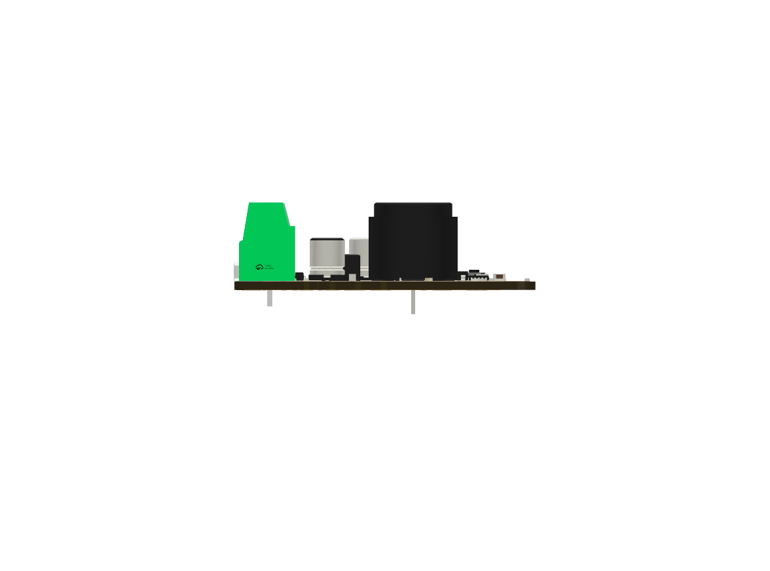
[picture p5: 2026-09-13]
plastic_case/SWC-3d-front.png

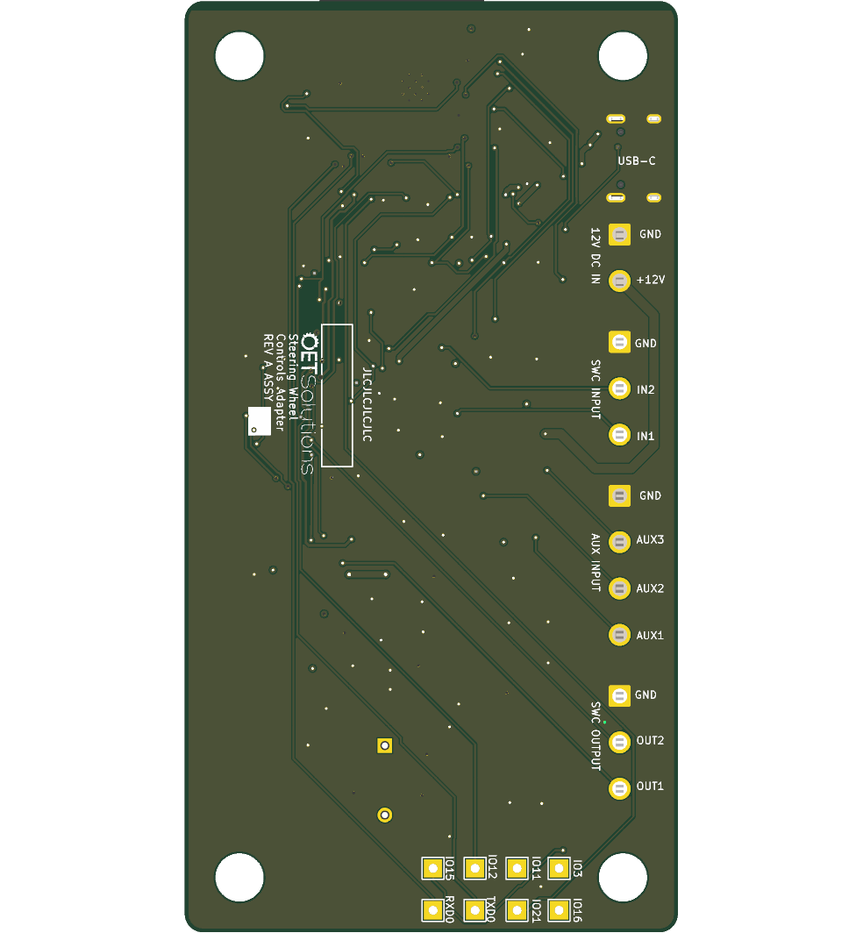
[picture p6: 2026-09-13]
plastic_case/SWC-3d-bottom.png

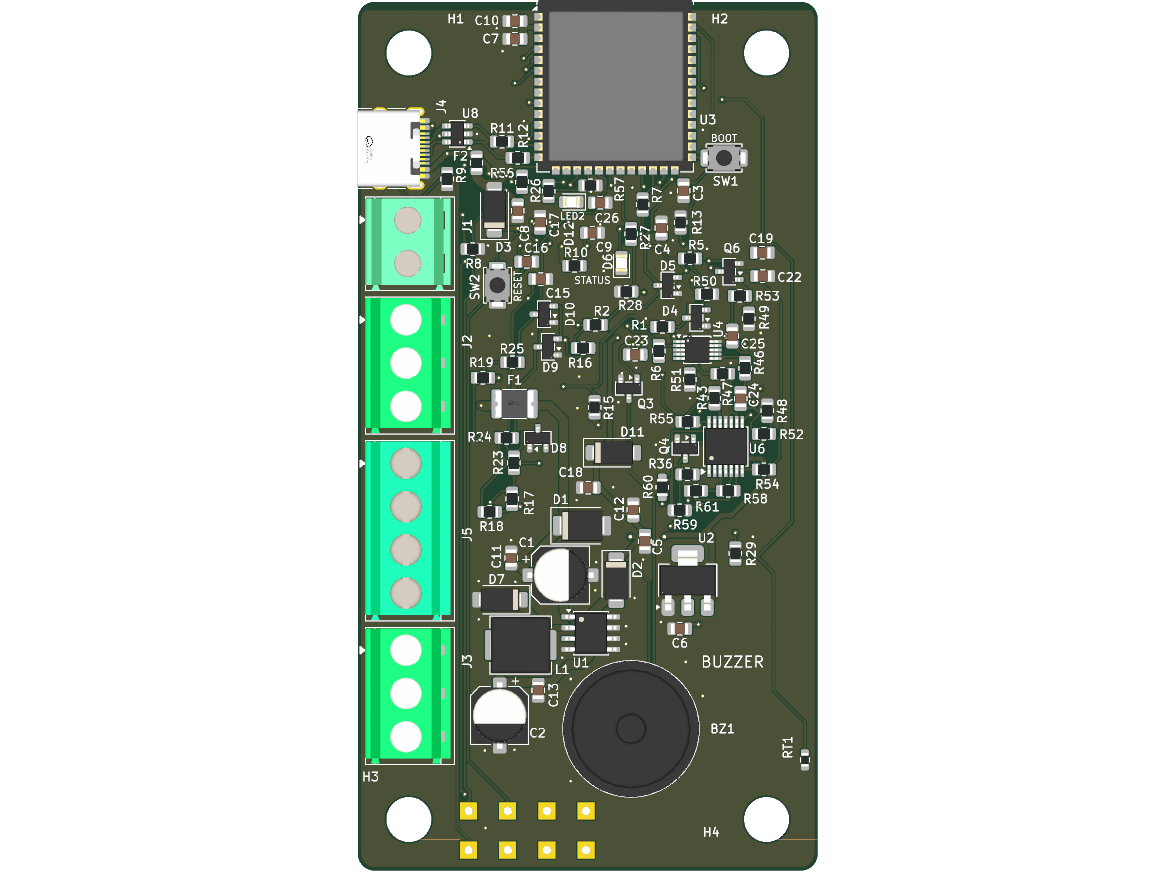
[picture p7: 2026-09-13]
plastic_case/SWC-3d-top.png

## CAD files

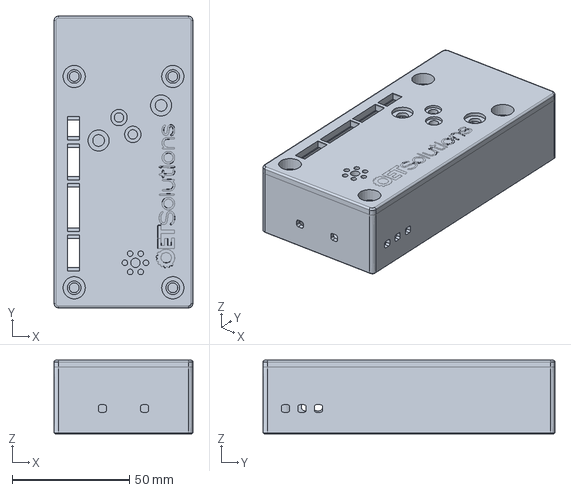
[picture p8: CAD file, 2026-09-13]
plastic_case/Case_Assembly.step
59.2 x 124.3 x 31.4 mm

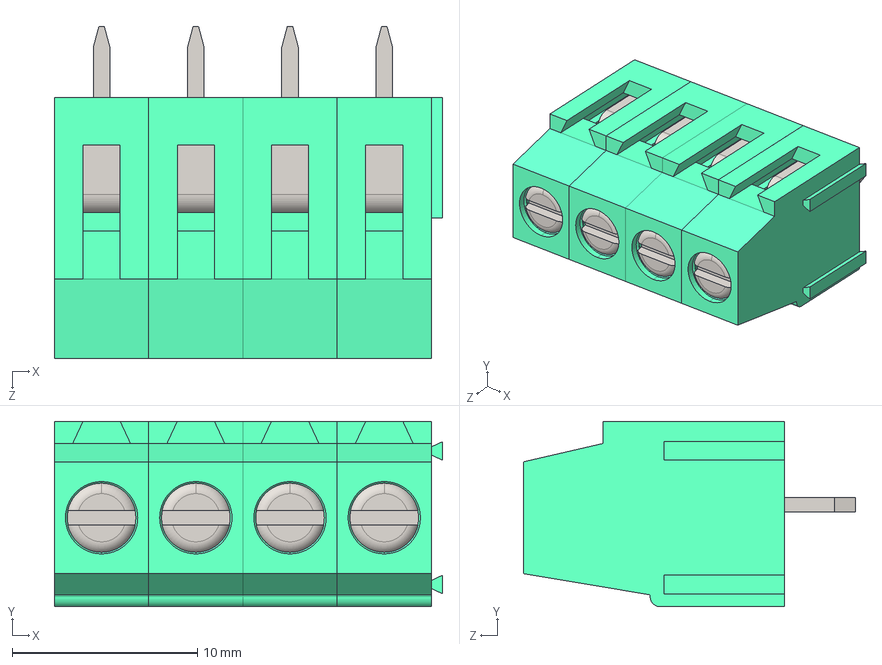
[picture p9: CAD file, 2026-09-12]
3dmodels/TerminalBlock_CUI_TB007-508-04_1x04_P5.08mm_Horizontal.step
20.9 x 10.0 x 17.9 mm

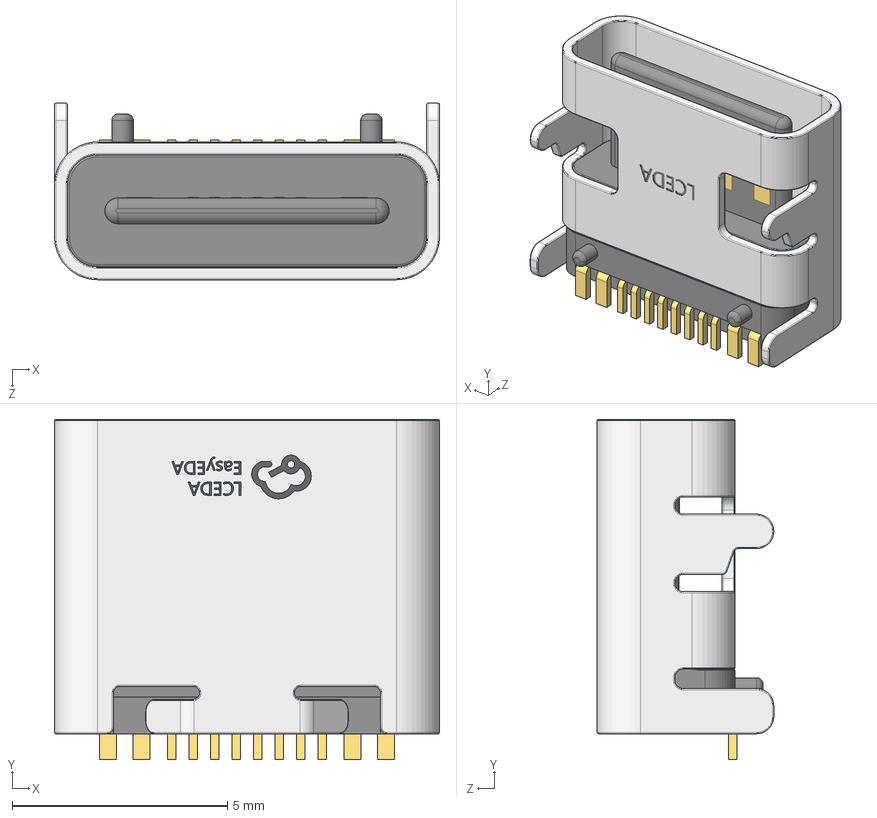
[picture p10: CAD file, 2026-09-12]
3dmodels/USB_C_Receptacle_HRO_TYPE-C-31-M-12.step
8.94 x 7.90 x 4.10 mm

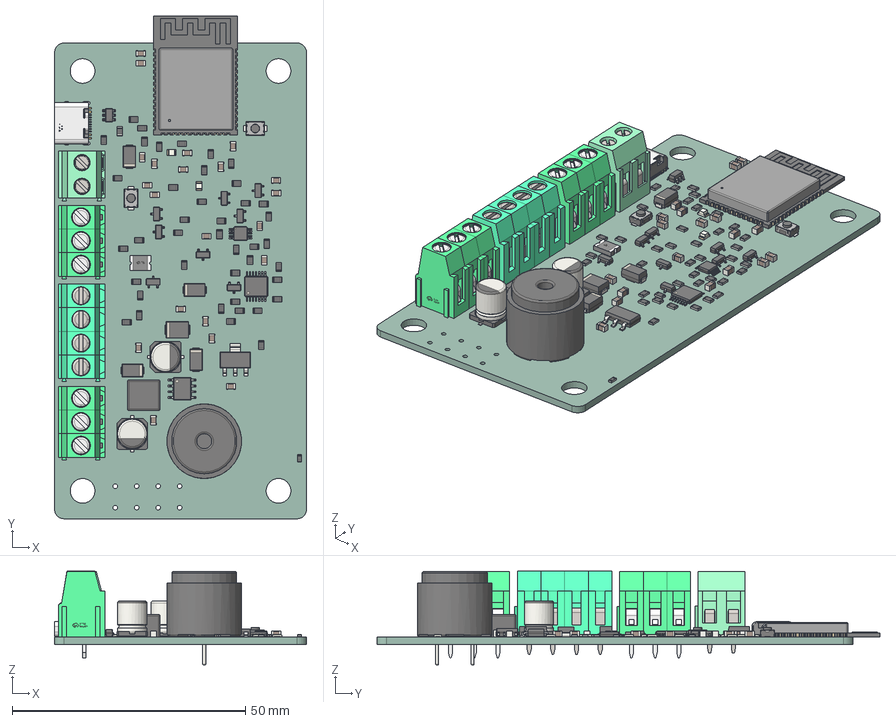
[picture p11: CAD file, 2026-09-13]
plastic_case/SWC.step
54.0 x 107.8 x 20.1 mm
C_0805_2012Metric x 21
零件1222 x 2
D_SMA x 4
CP_Elec_63x77 x 2
SOIC-8_3.9x4.9mm_P1.27mm
R_0805_2012Metric x 41
SOT-23 x 8
CONN-TH_2P-P5.00_WJ500V-5.08-2P
Fuse_0805_2012Metric
CONN-TH_WJ500V-5.08-4P
R_0603_1608Metric
TSSOP-14_4.4x5mm_P0.65mm
USB-C_SMD-TYPE-C-31-M-12
SW_SPST_TS-1088-xR020 x 2
a72dba50-8551-11ed-a139-00155d22e2d7_part
a72dbb72-8551-11ed-a139-00155d22e2d7_part
a72dbbea-8551-11ed-a139-00155d22e2d7_part
SOT-223
D_SMB
F1812_L4.5-W3.2-H1.0
LED_0805_2012Metric x 2
ESP32-S3-WROOM-1
MSOP-10_3x3mm_P0.5mm
SOT-23-6
MagneticBuzzer_StarMicronics_HMB_06_HMB_12
SWC_PCB

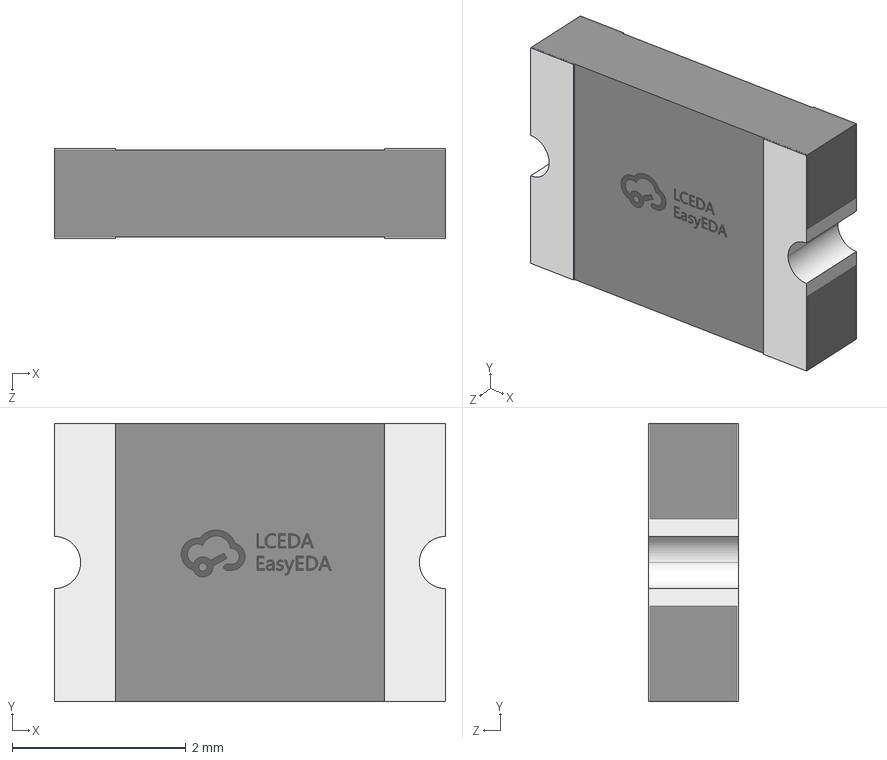
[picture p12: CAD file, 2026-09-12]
3dmodels/Fuse_1812_4532Metric.step
4.50 x 3.20 x 1.04 mm

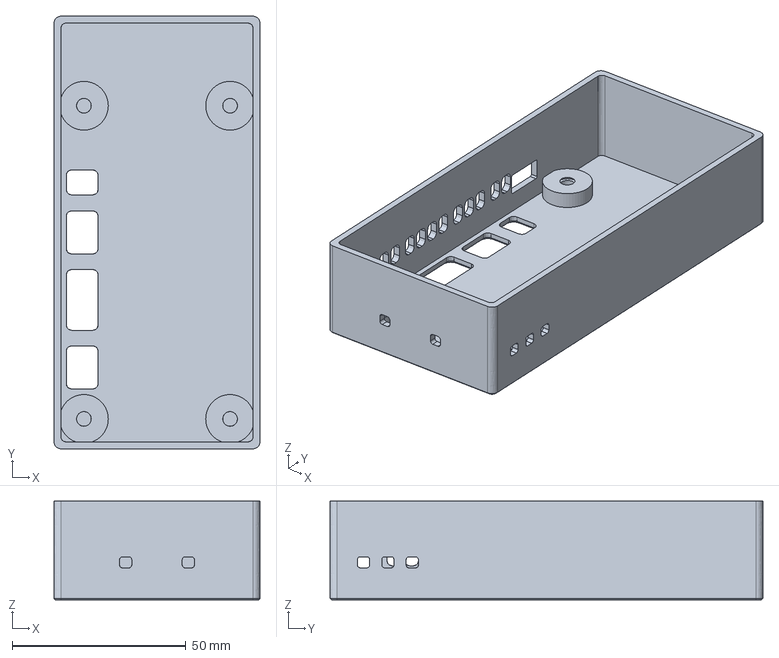
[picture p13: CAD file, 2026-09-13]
plastic_case/Case_Body.step
59.2 x 124.3 x 28.4 mm

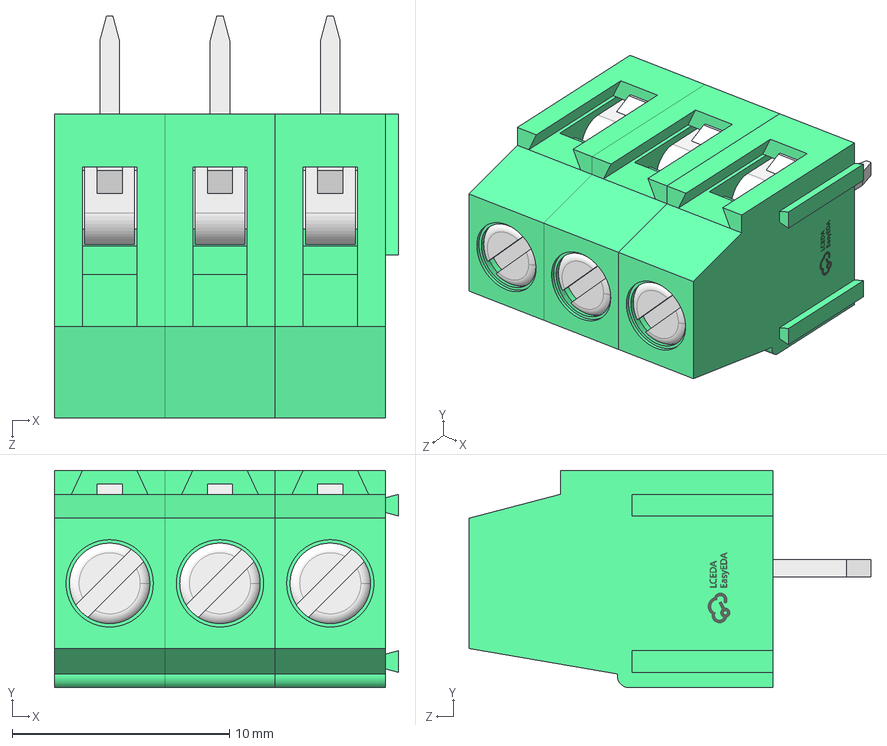
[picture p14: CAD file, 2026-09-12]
3dmodels/TerminalBlock_CUI_TB007-508-03_1x03_P5.08mm_Horizontal.step
15.8 x 10.0 x 18.5 mm

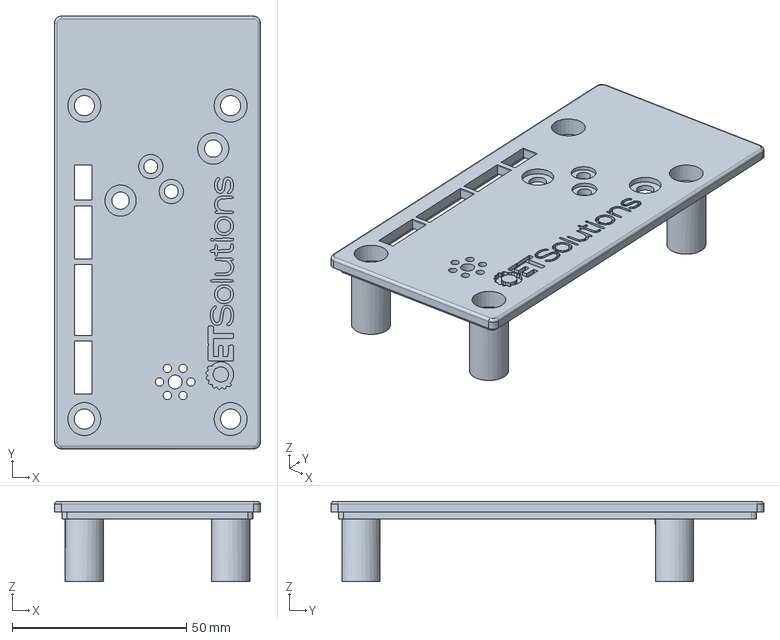
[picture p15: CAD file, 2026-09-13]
plastic_case/Case_Lid.step
59.2 x 124.3 x 23.0 mm

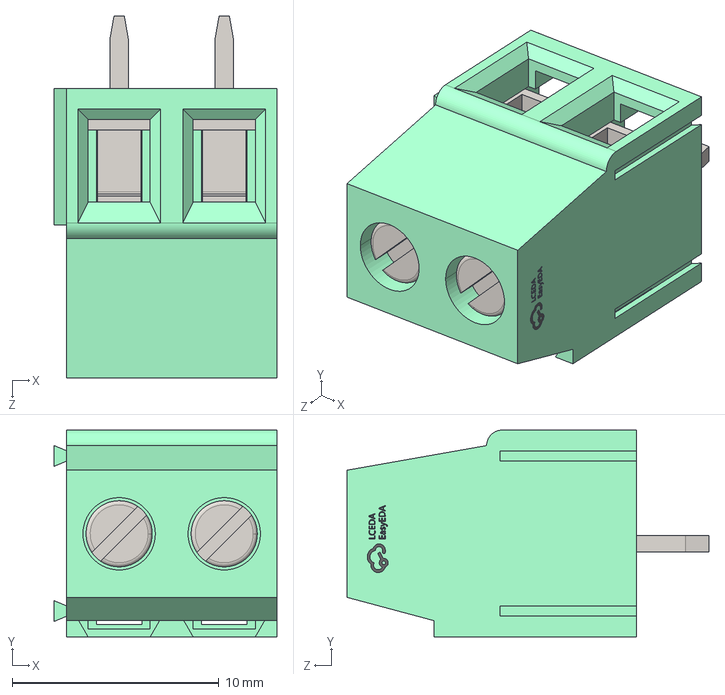
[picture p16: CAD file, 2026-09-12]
3dmodels/TerminalBlock_CUI_TB007-508-02_1x02_P5.08mm_Horizontal.step
10.8 x 10.0 x 17.5 mm

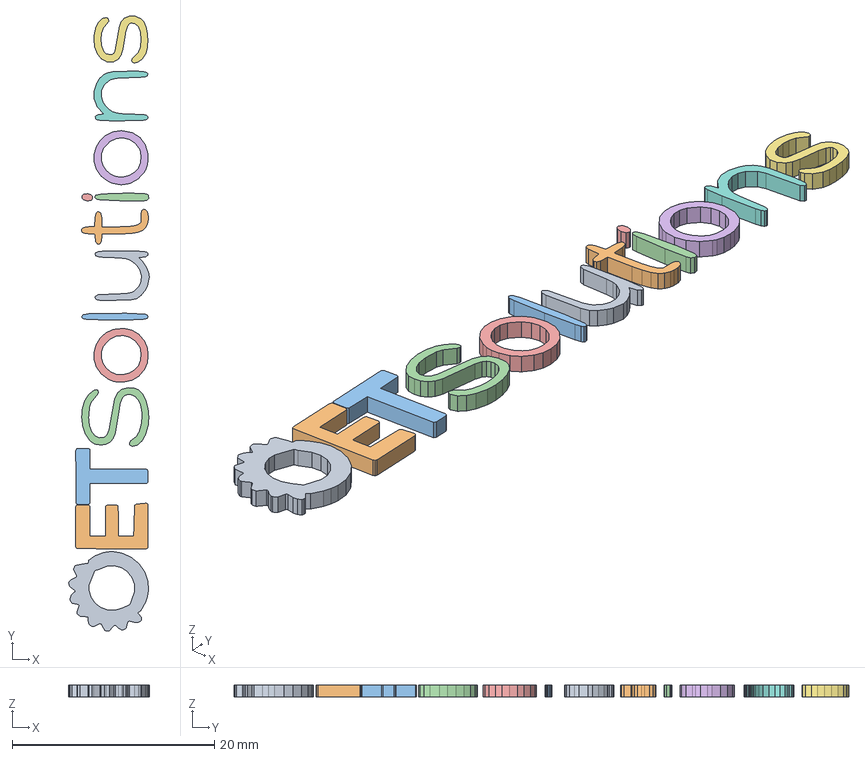
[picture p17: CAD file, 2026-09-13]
plastic_case/Logo_Inlay.step
8.00 x 60.9 x 1.20 mm

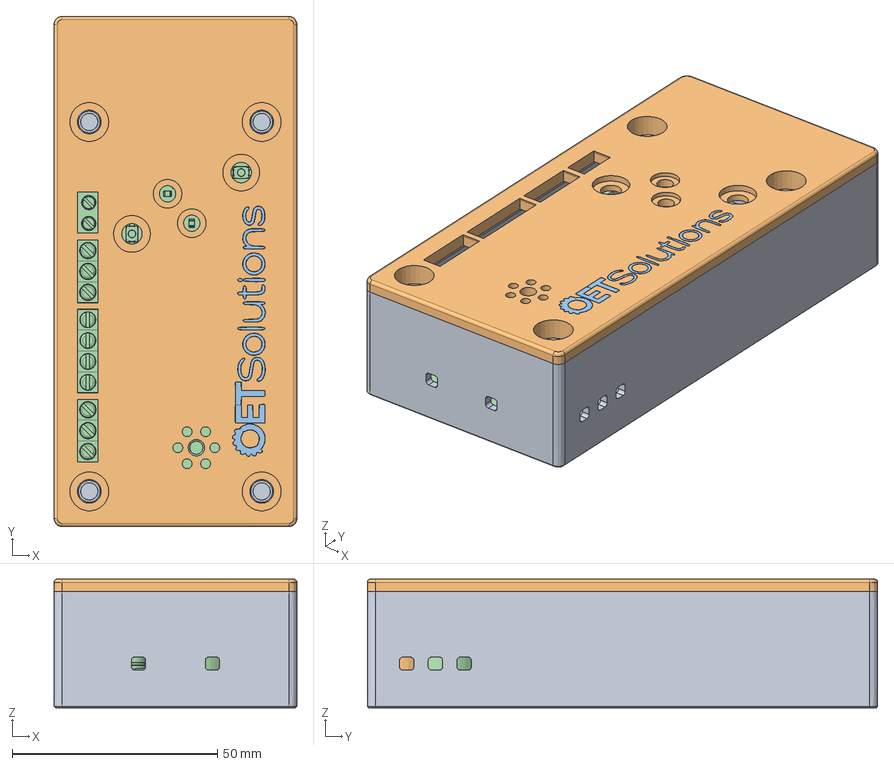
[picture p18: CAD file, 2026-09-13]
plastic_case/SWC_Enclosure.FCStd
59.2 x 124.3 x 31.4 mm
Case_Body
Case_Lid
Logo_Inlay
PCB

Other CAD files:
plastic_case/Case_Body.stl
plastic_case/Case_Lid.stl
plastic_case/Logo_Inlay.stl
plastic_case/SWC_Enclosure.3mf

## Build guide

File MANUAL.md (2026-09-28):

# SWC Adapter — User Manual

This is the operating manual for the **SWC Steering Wheel Controls Adapter**: what
it does, how to install it, how to teach it your wheel's buttons, how to give
those buttons the actions you want, and how to keep its firmware up to date. It
is written for the person using the adapter, not for the person building it.

> **Coming from the old 2022 Pico board?** The gesture-programming flow you liked
> **works here too**: hold **AUX1**, do the gesture on a wheel button, and the
> adapter **holds a distinct voltage** on the KEY line for you to teach your head
> unit — release AUX1 to release the line. See [§8.2](#82-programming-a-gesture-no-app-needed).
> The rest of chapter 5 explains what the adapter does with that.

For the engineering description see [DESIGN.md](DESIGN.md); for how the firmware
and app are structured, [AGENTS.md](AGENTS.md) and the spec under
`docs/superpowers/specs/`; for ordering, [MANUFACTURING.md](MANUFACTURING.md).

## Quickstart

The shortest path from a boxed adapter to a working steering wheel.

**What you need:** the adapter, a USB-C cable (to a phone **or** any USB power
source), and the factory wheel + head-unit wiring.

1. **Wire it up.** Factory wheel ladder → `SWC_IN` (`J2`). Adapter → head unit
   `SWC_OUT` (`J3`). Ground both. Optional: 12 V to `J1`. ([§3](#3-the-board-and-what-plugs-in-where), [§4](#4-installing-it-in-the-car))
2. **Power it on.** One short beep + slow-breathing STATUS LED = healthy. No phone
   needed. ([§6](#6-first-power-on))
3. **Teach it where your buttons are — learn each button.** Hold **AUX1** ~1.5 s
   (LEDs alternate), press **one** wheel button, release AUX1. Repeat for every
   button. Beep = `LEARN_OK`. ([§8](#8-learning-and-programming-no-app-needed))
4. **Give a button's gestures their functions — program the gestures.** Hold
   **AUX1**, do the gesture (**tap** = single, **two taps** = double, **hold** =
   long) on the button, and while still holding AUX1 teach your head unit that
   voltage (**"set key function"** on the head unit). Release AUX1. Repeat for the
   other gestures. ([§8.2](#82-programming-a-gesture-no-app-needed))
5. **That's it — no app required.** Your wheel now has single/double/long
   functions on every button. ([§5](#5-how-it-behaves--the-mental-model))

**Optional — install the Android app** for extras the head unit can't do on its
own: give a gesture a *different* function, launch a phone app, or send an
Android intent. ([§9](#9-binding-gestures-to-actions-and-using-the-app),
[§10](#10-the-android-app))

## Contents

1. [What the adapter does](#1-what-the-adapter-does)
2. [What you need](#2-what-you-need)
3. [The board, and what plugs in where](#3-the-board-and-what-plugs-in-where)
4. [Installing it in the car](#4-installing-it-in-the-car)
5. [How it behaves — the mental model](#5-how-it-behaves--the-mental-model)
6. [First power-on](#6-first-power-on)
7. [Feedback reference — the LEDs and the buzzer](#7-feedback-reference--the-leds-and-the-buzzer)
8. [Learning and programming (no app needed)](#8-learning-and-programming-no-app-needed)
9. [Binding gestures to actions (and using the app)](#9-binding-gestures-to-actions-and-using-the-app)
10. [The Android app](#10-the-android-app)
11. [Updating the firmware](#11-updating-the-firmware)
12. [Maintenance mode — WiFi and Bluetooth setup](#12-maintenance-mode--wifi-and-bluetooth-setup)
13. [Troubleshooting](#13-troubleshooting)
14. [Settings reference](#14-settings-reference)

---

## 1. What the adapter does

A steering-wheel button is not a digital switch. It is a resistor dropped across
a single analog **KEY** line; the head unit pulls that line up and works out which
button was pressed from the voltage it reads. There are usually two such lines —
this board calls them **SWC1** and **SWC2** — with the buttons split between them.

That arrangement is cheap and reliable, and also completely fixed: the resistor
values, and therefore the head unit's behaviour, live in the factory button pod.
A given aftermarket head unit wants a specific resistance it was taught, and it
has no concept of a "double press" or a "long press" — it only reads a voltage and
recognises key windows.

The adapter sits between the two. It:

- **reads** the factory ladder on the SWC1/SWC2 inputs,
- **interprets** single, double and long presses,
- **drives** the head unit's KEY line with a closed-loop servo, presenting the
  voltage the head unit expects for the action you chose.

Because the mapping is software, buttons can be **re-mapped, combined, or given
press behaviours the factory wiring never had** (a long-press on *next* that opens
an app, say). And because a press can also be reported to an **Android phone over
USB**, the adapter can trigger actions the head unit's own steering-wheel input
cannot express — launching an app, sending an intent with a data payload.

Two identical channels, **SWC1** and **SWC2**.

**The adapter works with no phone attached.** The phone app is an enhancement, not
a requirement: an unconfigured adapter passes presses straight through to the head
unit so the wheel behaves like stock, and the buttons can be taught entirely on
the device itself (chapter 8).

## 2. What you need

- The SWC adapter board (in its enclosure).
- A **USB-C cable** to a USB power source or an Android phone — the board runs
  from USB alone, or from a 12 V feed.
- **Vehicle wiring**: the factory steering-wheel ladder to the adapter's input
  terminal, and the adapter's output terminal to the head unit's SWC/KEY input.
  Both need a ground.
- Optional: **12 V** from the vehicle (switched or permanent) so the adapter is
  powered without USB.
- Optional: an **Android phone** (Android 8.0 / API 26 or later) with a USB-C
  **OTG-capable** port, to use the app.
- Optional: **wires to the AUX inputs** if you want extra buttons wired into the
  adapter (chapters 3 and 8).

## 3. The board, and what plugs in where

Four screw terminals on the board's left edge carry all the wiring, and USB-C sits
on the top-left edge. Each terminal has its own ground pin, and the pin function is
silkscreened on the back of the board — the enclosure has windows over those labels
so you can read them without opening the case.

| Terminal | Function | Pins (left to right) |
| --- | --- | --- |
| **J1** | 12 V power in (optional) | GND, +12 V |
| **J2** | Steering-wheel **inputs** | GND, SWC2, SWC1 |
| **J3** | **Output** to the head unit | GND, KEY2, KEY1 |
| **J5** | Auxiliary inputs | GND, AUX3, AUX2, AUX1 |
| **J4** | USB-C | — |

The two channels share one input terminal and one output terminal. **`SWC1`/`KEY1`
is channel 1; `SWC2`/`KEY2` is channel 2.** Match each channel's input to its own
output — a ladder on `SWC1` is served on `KEY1`.

> The pin order on each terminal matches the silkscreen under the corresponding
> floor window. Read the window rather than this table if they ever differ.

### 3.1 Power

Both a **12 V feed** and **USB power** can run the board, and the 12 V feed is
**optional** — the board works from USB alone. The two sources are diode-OR'd, so
either alone is sufficient and a fault on one cannot back-feed the other. Each has
its own self-resetting fuse (a PPTC).

Use 12 V when you want the adapter powered in the car without a cable run to a USB
port. Use USB when you are setting it up on the bench or updating firmware.

### 3.2 The two LEDs

Both LEDs are green, and they mean different things — they are distinguished by
**blink pattern and position**, not colour.

| LED | Where | Role |
| --- | --- | --- |
| **STATUS** (`D6`) | — | The adapter's overall **state** — "is this thing OK?" |
| **LED2** (`D12`) | — | **Activity** — what it is doing right now |

See chapter 7 for the full pattern tables.

### 3.3 The buzzer

A single fixed-tone buzzer carries the whole no-app experience. It can only be
switched on and off — the tone is fixed by the part — so every message is a
**rhythm**: a number of beeps in a pattern. The patterns are all in chapter 7.

### 3.4 The buttons

Two small buttons on the board:

- **RESET** — restarts the adapter. It comes back up in its safe idle state and
  resumes normal operation; nothing is lost.
- **BOOT** — for firmware recovery only. It is recessed behind a hole in the lid
  and is normally never needed (chapter 11 explains the software update routes).
  **Do not hold BOOT while powering on** — that puts the chip into its raw
  serial-download mode rather than starting the adapter.

### 3.5 Test points

Eight bare pads (`TP1`–`TP8`) exist for bench diagnostics. `TP7`/`TP8` carry the
**serial console** (`115200 8N1`) — clip a USB-UART adapter between them and a
ground pad if you ever need to read the adapter's log. You will not need these in
normal use.

## 4. Installing it in the car

1. **Identify the factory ladder.** The steering-wheel buttons are a resistor
   chain whose common is tied to ground; pressing a button pulls the input *down*
   toward ground. The buttons are split across the vehicle's two SWC lines, if it
   has two.
2. **Wire the inputs.** Factory SWC line 1 → `J2` `SWC1`; SWC line 2 → `J2`
   `SWC2`; ladder common/ground → `J2` `GND`. If the vehicle has only one SWC
   line, use `SWC1` and leave `SWC2` unconnected — the two channels are
   independent, so one unused input does not affect the other.
3. **Wire the outputs.** `J3` `KEY1` → head unit's SWC/KEY input 1; `J3` `KEY2` →
   head unit SWC/KEY input 2; `J3` `GND` → head unit ground.
4. **Wire 12 V (optional).** `J1` `+12 V` and `J1` `GND`. If you skip this, power
   the adapter over USB instead.
5. **Power it up and watch the STATUS LED.** A healthy boot gives one short beep
   and the STATUS LED breathing slowly (running, no phone connected). See chapter
   6.

> The wheel's ladder must be connected **at power-on**. The adapter measures the
> ladder's idle level when it boots and treats that as the reference; a ladder
> attached later may not be adopted until the next restart.

## 5. How it behaves — the mental model

### 5.1 The ladder and the KEY line

The adapter reads the ladder on the **input** side and *servos* the head unit's
KEY line on the **output** side. The output tracks what the board actually senses,
so the mapping holds even if the supply voltage drifts.

### 5.2 Gestures

The adapter recognises three gestures on any learned button:

| Gesture | Meaning |
| --- | --- |
| **Single** | one tap |
| **Double** | two taps inside the double-press window |
| **Long** | held past the long-press threshold |

A **double press is the same button pressed twice** in quick succession. Two
*different* buttons pressed in quick succession are two separate presses, not a
double.

### 5.3 What the head unit sees for each gesture

**Your head unit is gesture-blind.** Its SWC input reads a *voltage* and matches it
to key windows; it has no idea what a "double press" is. So the only way the head
unit can act differently for single, double and long is if the adapter presents a
**different voltage** for each.

That is what the adapter does. For each learned button it sends three distinct,
predefined voltages — one for single, one for double, one for long:

| Your gesture | What the adapter sends the head unit |
| --- | --- |
| **Single** (one tap) | the button's **single** voltage |
| **Double** (two taps) | the button's **double** voltage |
| **Long** (held) | the button's **long** voltage |

Because those three voltages are **fixed and always the same** for that button —
regardless of supply voltage or temperature — you can teach your head unit once
(§8.2) and it will keep working. This is the "compensation" that keeps the same
gesture always sending the same voltage.

The three voltages come from a **fixed ascending table** laid out **from the low end
of the output band upward**, and each is a fixed fraction of that band — so they
stay correct on either a 5 V or a 3 V unit. The steps are deliberately fine: that
way a head unit which resolves only a few distinct key windows simply will not tell
two adjacent gestures apart, which you will see as "that radio will not take three
keys on one button" rather than as a firmware fault. If a radio cannot tell two of
your gestures apart, that is the radio's resolution, not the adapter's; see
chapter 13 (troubleshooting) for that case.

**You do not have to program a gesture to use the button.** A button you have only
learned still sends its single voltage for a tap, so it works as a stock button. The
programming step (§8.2) is how you give the *extra* gestures their functions.

### 5.4 What happens on a press

1. Presses are filtered and classified into a gesture.
2. If the gesture is **bound** to something in the app, that runs. A hardware action
   (present a key voltage to the head unit) runs **first and always** — it does not
   depend on a phone being connected.
3. If the gesture is **unbound**, the adapter sends that gesture's **fixed voltage**
   (as in §5.3) — so a head unit you programmed will fire the function you taught
   it. A press matching **no learned button** is reported as "unknown" and beeps
   `KEY_UNKNOWN`; the adapter does not invent a key.
4. The press is reported to the app over USB, if one is connected, so app-side
   actions (launch an app, send an intent) can fire.

**Normal presses are silent by default.** The adapter does not beep on each press;
you can turn a per-press "click" on in the app if you want one (§14).

### 5.5 Output range — matching your head unit

The adapter **auto-detects** the head unit's key voltage at startup and picks the
output range to match:

- a **5 V** head unit is driven at gain 1.82;
- a **3 V** head unit is driven at gain 1.00 (the output tracks the signal).

The safety bias is toward the 5 V range when the measurement is absent or
ambiguous, because over-ranging a 3 V unit is the only dangerous mistake. You do
not normally need to touch this — see `gain_policy` in chapter 14 if you do.

The three gesture voltages (§5.3) are chosen as fractions of this range, so they
stay correct on either a 5 V or a 3 V unit.

### 5.6 Two ways to give a gesture a function — **read this if you used the old board**

There are **two independent ways** to give a button's gesture a function, and they
work together:

| Way | What it does | Where | Needed? |
| --- | --- | --- | --- |
| **Program the gesture** | Holds a **fixed voltage** on the KEY line so your head unit's own "set key function" learns it | **On the device**, hold AUX1 (chapter 8) | Basic use — no app |
| **Bind the gesture** | Tells the adapter to run a specific **action** (a chosen `key_mv`, launch an app, send an intent) | **In the Android app** (chapter 9) | Optional |

**This is the 2022 Pico flow, and it works here.** Hold AUX1, do the gesture on a
wheel button, teach your head unit that voltage, release AUX1. The adapter holds a
distinct voltage per gesture — single, double and long each get their own — so a
head unit you have programmed once gives you all three functions per button with
**no app at all**.

A **binding**, if you set one in the app, **overrides** the default gesture voltage
for that one gesture: the adapter then sends whatever your binding says (or runs an
app action) instead. Remove the binding and the gesture falls back to its default
programmed voltage. So the app *expands* the basic behaviour; it does not replace
it.

### 5.7 How the head unit's "function" gets chosen

The adapter **does not store a named head-unit function** ("Volume Up", "Source",
…). It sends a **voltage** on the KEY line. Which function that voltage means is
the *head unit's* interpretation, and it is different in every car — the same
"volume up" is a different voltage on a different radio — so the firmware cannot
name it and does not try.

That is why you "program" a gesture by teaching the **head unit** the voltage,
rather than picking a function from a list. It is also why an `OUT_VOLTAGE` binding
(chapter 9) asks you for a **`key_mv`** — a number of millivolts — rather than a
function from a list. There is **no built-in table of head-unit functions to pick
from**.

See chapter 9.3 for how to find those numbers, and chapter 8.2 for the no-app way.

## 6. First power-on

On a healthy boot the adapter:

1. puts the KEY output into its **safe idle state** (the line released) *before*
   it brings up anything else,
2. loads its saved configuration (falling back to defaults if it is damaged),
3. measures the ladder and the head unit,
4. then starts serving presses.

You will hear **one short beep** and see the STATUS LED **breathing slowly**. If
instead you hear a repeated pattern, see chapter 7 for what it means.

### Before it has been configured

A brand-new adapter has no learned buttons and no bindings. It runs in
**pass-through**: it mirrors what it senses on the wheel onto the head unit. Your
steering wheel works like stock, and the adapter is invisible. Everything else in
this manual is about *upgrading* that behaviour.

### First-ever power-on with no saved configuration

The adapter offers its setup window on the very first power-on with no
configuration (chapter 12), which is how you get it onto WiFi without any other
trigger. The STATUS LED double-flashes while the window is open.

## 7. Feedback reference — the LEDs and the buzzer

The LEDs are **continuous state** you can read at a glance; the buzzer is
**transient events**. Between them they carry everything the adapter needs to tell
you without a phone.

### 7.1 STATUS LED (`D6`)

| Pattern | Meaning |
| --- | --- |
| Off | No power / not running |
| **Solid** | Running, output safe, USB connected, configuration valid — all good |
| **Slow breathe (1 Hz)** | Running normally, **no phone connected** |
| **Fast blink (5 Hz)** | **Fault** — read the buzzer pattern for which one |
| Double-flash burst | **Maintenance mode** active (WiFi/Bluetooth setup) |
| Alternating with LED2 | **Learn mode** active, waiting for a press |

A **fault latches** the fast blink and outranks everything else: a device that is
faulted is not OK, whatever the link is doing. A hardware fault clears only on a
restart, because a wiring fault or a collapsed supply does not fix itself. The one
exception is a **configuration fault**, which clears as soon as a good
configuration is written.

### 7.2 LED2 (`D12`)

| Pattern | Meaning |
| --- | --- |
| Off | Idle, no recent activity |
| Flick | A gesture was recognised |
| **Solid** | A key value is currently being presented (**the line is driven**) |
| Long pulse (0.5 s) | Output range changed, or the head unit was (re)detected |

LED2's "solid while driving" is a genuine diagnostic: it shows the adapter is
holding a key, which tells you whether "the adapter is doing something wrong" or
"the head unit is ignoring it".

### 7.3 Buzzer patterns

The tone is fixed; the **rhythm** is the message. Each pattern is written as
*pulse length / gap length × repeats*.

| Pattern | Rhythm (on/off ms) | Repeats | Meaning |
| --- | --- | --- | --- |
| `BOOT_OK` | 60/60 | 1 | Power-on self-test passed |
| `BOOT_DEGRADED` | 60/60 | 3 | Booted, but with a fault (see `FAULT_*`) |
| `BOOT_ERROR` | 500/200 | 2 | Cannot serve output; needs attention |
| `KEY_ACCEPTED` | 25/0 | 1 | A gesture was recognised (deliberately short and quiet — you hear it constantly) |
| `KEY_UNKNOWN` | 120/80 | 1 | A press was seen but matches no learned button |
| `PROGRAM_ENTER` | 40/40 | 2 | Entering learn mode (or maintenance mode, from a 3 s AUX1 hold) |
| `PROGRAM_STEP` | 40/40 | 1 | *Not played* — see the note below |
| `PROGRAM_SAVED` | 40/20 | 4 | *Not played* — see the note below |
| `PROGRAM_EXIT` | 200/0 | 1 | Learn finished |
| `PROGRAM_CANCEL` | 300/100 | 1 | *Not played* — see the note below |
| `LEARN_PROMPT` | 100/100 | 1 | Waiting for you to press a button |
| `LEARN_OK` | 40/30 | 2 | That button was learned and accepted |
| `LEARN_REJECT` | 300/80 | 2 | The sample was rejected; try again |
| `FAULT_DAC` | 500/300 | 3 | Output/DAC fault |
| `FAULT_CONFIG` | 500/300 | 4 | Configuration corrupt; defaults loaded |
| `FAULT_INPUT` | 500/300 | 3 | Ladder/rail wiring fault — an open input or a short to a supply |
| `FACTORY_RESET` | 800/200 | 3 | Everything erased |
| `OTA_START` | 400/0 | 1 | Firmware update started |
| `OTA_OK` | 150/100 | 2 | Firmware update written successfully |
| `OTA_FAIL` | 80/40 | 3 | Firmware update failed; old version still running |

> The **fatal** patterns (`BOOT_ERROR`, `FAULT_*`, `FACTORY_RESET`) are longer than
> the rest on purpose — they must be unmistakable, and they are rare enough that
> nothing is delayed behind them. They also play even when the buzzer is set to
> `OFF`, because a device that cannot serve output must still be able to say so.
>
> **`PROGRAM_STEP`, `PROGRAM_SAVED` and `PROGRAM_CANCEL` are not played by this
> adapter.** They existed in the 2022 Pico design's gesture-programming flow ("*n*
> beeps announces the *n*-th gesture", escalating to a saved confirmation). This
> adapter uses the learn/programming flow in chapter 8 instead, which signals with
> `PROGRAM_ENTER` on the hold and `LEARN_OK`/`LEARN_REJECT` on the release rather
> than an escalating beep count. They are listed only so this table matches the
> firmware's full vocabulary.

## 8. Learning and programming (no app needed)

There are **two things you do on the device itself**, both driven by the **AUX1**
input, and both work with **no phone**:

| You want to… | Hold AUX1 and… | Records |
| --- | --- | --- |
| **Learn** a button | press the button once, then release AUX1 | **where** the button is (its voltage) |
| **Program** a gesture | do the gesture (tap / two taps / hold), then release AUX1 | **holds a voltage** for your head unit to learn |

You learn each button **once**; you then program its gestures to give them functions
on the head unit. Wire a momentary push-button to `AUX1` on `J5` (and its ground)
if the board does not already have one.

> **AUX1 is the programming button.** It is also the only input that is *never* a
> learn target.

### 8.1 Learning the buttons

Do this first, for every wheel button.

1. **Hold AUX1** for about **1.5 seconds**. You hear `PROGRAM_ENTER` and the STATUS
   LED starts alternating.
2. **While still holding AUX1, press and briefly hold the wheel button you want to
   teach** — on whichever input you are programming (SWC1, SWC2, AUX2 or AUX3).
   **You do not pick a channel or a menu** — the adapter watches all the inputs and
   takes the one that leaves its idle as the one being programmed. You hear
   `LEARN_PROMPT` while it measures.
3. **Release the wheel button, then release AUX1.** The button is stored and the
   adapter beeps `LEARN_OK`. If a measurement is rejected (too noisy, or the button
   barely left idle), you hear `LEARN_REJECT` — try again with a firmer press.

- **One hold = one button, learned once.**
- **Re-learning a button corrects it in place** — press the *same* physical button
  again and the adapter matches it by voltage rather than adding a duplicate.
- **Learning adds buttons; it never wipes the ones you already have.**
- **After learning, the button already works like stock** — a tap sends that button's
  fixed single voltage to the head unit.
- **Its double and long send their own fixed voltages too**, once you have taught the
  head unit what they mean (**programming**, §8.2).

### 8.2 Programming a gesture (no app needed)

This is how you give the *double* and *long* gestures their own functions on the
head unit, and it is the 2022 Pico flow. **Do this after learning the button.** You
need the head unit's own "**set key function**" / "**learn steering key**" screen
open for each step — that is where the function is stored.

1. **Hold AUX1** ~1.5 s (`PROGRAM_ENTER`, STATUS LED alternating).
2. **Do the gesture you want to program** on a button you have already learned:

   | To program | Do this on the button |
   | --- | --- |
   | the **single** function | tap it once |
   | the **double** function | tap it twice |
   | the **long** function | hold it |

   The adapter now **holds that gesture's voltage on the KEY line**, and keeps
   holding it until you release AUX1. Give it about half a second after the gesture
   so it has settled on the right voltage before you capture it (the *double*
   voltage only appears once the second tap has finished).
3. **While the voltage is being held, set the function on your head unit** — use
   its "set key function" screen and assign it to that voltage (usually you press
   "set" on the head unit and it captures whatever level it is reading).
4. **Release AUX1.** The adapter releases the KEY line.

Repeat from step 1 for each gesture. When you later do that gesture normally, the
adapter sends the **same voltage**, so the head unit fires the function you set.

- **Single, double and long get three different, fixed voltages** — that is what
  makes three functions possible on one button. They do not drift with supply
  voltage or temperature.
- **You can leave a gesture unprogrammed.** A button you have only learned still
  sends its single voltage for a tap.
- **A gesture you have *bound* in the app overrides its default voltage** — see
  §5.6 and chapter 9.
- **A press during programming is being *held* for the head unit, not driven as an
  action** — your app bindings do not fire for it.

### 8.3 AUX inputs are switches, not ladders

AUX2 and AUX3 are for extra buttons wired directly to the adapter (a switch to
ground). Learning one records the switch's own window — it is a simple pressed /
not-pressed input. You can then bind gestures on it like any other button.

### 8.4 If AUX1 is held too long

AUX1 is also the way in to **maintenance mode**, on a **longer hold**:

| Hold AUX1 for | What happens |
| --- | --- |
| ~1.5 s | **Learn / programming** |
| ~3 s | **Maintenance mode** (WiFi + Bluetooth setup) |

The two are nested deliberately so over-holding escalates cleanly: if you hold past
3 seconds, the adapter abandons the learn (nothing half-measured is saved) and opens
the maintenance window instead.

## 9. Binding gestures to actions (and using the app)

**The adapter gives you a working wheel with no app** (chapter 8). The Android app
is **optional** and **expands** on that: it lets you point a gesture at a specific
key voltage you choose, launch a phone app, or send an Android intent — things the
head unit's own input cannot do.

> **Bindings are an override, not a requirement.** A gesture with no binding uses
> its default programmed voltage (§5.3), so a device used headlessly keeps working.
> A binding on one gesture only changes that gesture.

A binding is one row of the app's **Bindings** grid: **channel + button + gesture →
action**.

- `SWC1 · Volume Up · Single` → present the key voltage for Volume Up
- `SWC1 · Volume Up · Long`   → launch your music app
- `ANY · Next · Double`       → send an intent with a data payload

**The core action is `OUT_VOLTAGE`** — present the head unit a key voltage it reads
as a key. That is what makes a *single* tap react on the stock head unit even when
no phone is running. `APP_*` actions are the phone's half.

### 9.1 Step by step — give a button a function

Worked example: make a **single tap** on **Volume Up** present the Volume Up key to
the head unit.

1. Connect the phone to the adapter (chapter 10.1).
2. Open the **Bindings** screen.
3. Find the row for **`SWC1 · Volume Up · SINGLE`**. (If Volume Up has not been
   learned yet, it will not appear — go back to chapter 8 and learn it first.)
4. **Tap the row.** The action picker opens.
5. Set **Kind** to **`OUT_VOLTAGE`**.
6. Type the **`key_mv`** value — the millivolt level your head unit reads as
   Volume Up (see 9.3).
7. Tap **Apply**. The row now shows `OUT_VOLTAGE`.
8. Repeat for the other gestures and buttons — e.g. set `SWC1 · Volume Up · LONG`
   to `APP_LAUNCH` with `package` = your music app.
9. Tap **Save to device.** Nothing is stored on the adapter until you save.

To make a gesture **stop** doing something, open the row and tap **Clear binding** —
it then falls back to its default programmed voltage (chapter 5.3).

### 9.2 The binding grid, and where buttons come from

The grid lists a row for every gesture on every button the adapter knows about:

- your **learned wheel buttons**, from chapter 8;
- your **configured AUX switches** (AUX2/AUX3).

Each row is channel-specific, because the same button name usually exists on both
ladders. **`ANY` is a real channel**: a binding on `ANY` matches the button on
*either* SWC channel.

### 9.3 Choosing `key_mv` — how a head-unit function is named

**There is no list of head-unit functions to pick from.** The adapter stores the
**voltage** to put on the KEY line, because "which key" is the head unit's
interpretation of that voltage and differs per head unit. So an `OUT_VOLTAGE`
binding asks for a **`key_mv`** — a number of millivolts.

**`key_mv` is bounded by the output stage.** The adapter can only pull the KEY line
*down*, so:

- the **lowest** level it can present is **1800 mV** (its output floor);
- the **highest** useful level is the head unit's **own idle minus 200 mV** — above
  that the line is simply released, not driven.

So for a typical head unit idling near 3.3 V, usable values are roughly
**1800–3100 mV**; for one idling near 5 V, roughly **1800–5000 mV**. A value outside
the band is clamped (with a warning on the app's Link screen) rather than silently
doing nothing.

**How to find the value for a function:**

1. The most reliable source is the head unit's own wiring sheet or a
   steering-wheel key-resistance table for your vehicle and radio — a specific
   button maps to a specific level.
2. You can narrow it experimentally: the **Ladder screen** shows what the adapter
   currently reads and classifies, so you can see the effect of a level as you
   try it. Bind it, save, press the button, and watch the radio.
3. When you don't yet know, a **safe starting point is a mid-band value** (e.g. a
   few hundred millivolts *below* the head unit's idle) and then adjust.

If a level produces **no reaction on the radio**, it is usually sitting above the
head unit's idle (so nothing was driven) or on a level that radio treats as a
different key. Move it lower within the band and try again.

### 9.4 The action library

| Action | Parameter | Runs on | What it does |
| --- | --- | --- | --- |
| `NONE` | — | — | Explicit no-op (placeholder) |
| `OUT_VOLTAGE` | `key_mv` | **Adapter** | Drive the KEY line to a voltage the head unit reads as a key — the core action |
| `OUT_RELEASE` | — | **Adapter** | Force the KEY line to idle |
| `APP_LAUNCH` | `package` | Phone | Launch an app by package name |
| `APP_INTENT` | `action`, `data` | Phone | Send an arbitrary intent, including a data payload |
| `KEYCODE` | `keycode` | Phone | Inject a key event (media/volume keys work unprivileged) |
| `MEDIA` | `command` | Phone | Media transport: `play`/`pause`/`next`/`prev`/`stop` |
| `VOLUME` | `target` | Phone | Step the volume of a named stream (`media`/`call`/`ring`/`alarm`) |
| `SYSTEM` | `command` | Phone | Housekeeping: `screen_off`/`night_mode`/`screenshot`/`open_settings` |
| `BUZZ` | `pattern` | **Adapter** | Play a named buzzer pattern instead of the default `KEY_ACCEPTED` |
| `APP_RAW` | `command` | Phone | Escape hatch for an app-defined command |

Notes:

- **Two actions per binding** at most, and **32 bindings in total** — these are
  storage limits of the adapter.
- **A hardware action runs even with no phone.** An `OUT_VOLTAGE` binding fires
  whether or not the app is running; the app-side kinds need the phone.
- **`BUZZ` replaces the default confirmation beep** — there is one buzzer, and a
  new pattern replaces rather than queues.
- **An empty cell means the default gesture behaviour.** A gesture with no binding
  presents its own programmed voltage for that gesture (§5.3), so it still reaches
  a head unit you programmed — it just does not do anything app-side.
- **Bindings are matched in order**, and a binding that appears first wins. If you
  bind a button to `ANY` and later want a *channel-specific* difference, make sure
  the specific binding is ahead of the `ANY` one.

## 10. The Android app

The app (`com.oetsolutions.swc`) is an **enhancement**: it configures the adapter,
shows you what it is doing, and can update its firmware. **The adapter works fully
without it.**

### 10.1 Installing the app

The app needs **Android 8.0 (API 26) or later** and a phone with **USB host
(OTG)** support — it talks to the adapter only over USB. Build artifacts are
published from the project's CI as a debug APK (see the repository's Actions page,
artifact `swc-app-debug`); install it with `adb install` or your phone's package
installer.

Connect the phone to the adapter's USB-C port with an OTG cable/adapter. The app
asks for USB permission the first time a device is attached — **allow it**. If no
prompt appears, replug the adapter; the prompt only shows on a fresh attach.

### 10.2 Link screen

The home screen. It shows:

- **Connection state** — Connected / Not connected / Not responding / Version
  mismatch / Failed.
- **Firmware version** the adapter is running.
- **Board temperature** and **free heap** — diagnostics; a non-zero temperature is
  not a problem.
- **Configuration problems** — e.g. the adapter lost its configuration and is
  running defaults, or it restored a backup.
- **Lost frames / adapter link loss** — a flaky USB cable. Re-seat the cable.
- **Device warnings** — e.g. a stored key level the adapter refused to drive as
  written and clamped instead.
- **A button's action did not run** — the *phone's* half of an app-side action
  failed (a permission, a missing app). The adapter still sent the key press.
- **Maintenance mode** — the button to open/close the setup window (chapter 12).

If the link fails, the screen gives you the reason and the fix, not just a red
light.

### 10.3 Ladder screen

A **live diagnostic** for the ladder channel. It shows the rail (idle) voltage,
each learned button's window as a band on a scale, and the current reading as a
marker — **with the band the adapter is currently classifying marked**. This is
what lets you tell an adapter fault from a head-unit fault:

- The adapter classifies the button you pressed, but the stereo does nothing → the
  problem is the head unit.
- The adapter classifies a *different* button than the one you pressed → the
  problem is the adapter (a window needs re-learning).

It also flags a **rail fault** — if the +3V3 supply has sagged, the screen says so
rather than misreading it as a button press.

### 10.4 Bindings screen

The bindings grid, one cell per **channel · button · gesture**. Each cell shows the
bound action, or **the default gesture behaviour** when nothing is bound. Tap a cell
to open the action picker:

- choose the **Kind** from the dropdown,
- fill in the parameter field if the kind needs one (e.g. `package` for
  `APP_LAUNCH`, or `key_mv` for `OUT_VOLTAGE`),
- **Apply** to set it, or **Clear binding** to fall back to the default gesture
  voltage.

**Save to device** writes the whole configuration to the adapter. Save is disabled
while there is a problem to fix (the screen lists them); a *save failure* (a nack,
a timeout) is shown separately and leaves Save enabled so you can retry.

> The grid lists your **learned** buttons and your configured AUX switches. **Learn
> your buttons on the device first** (chapter 8) — they appear here once learned.

### 10.5 Update screen

Shows the running firmware version and offers the update paths in chapter 11.

## 11. Updating the firmware

There are two routes, and the adapter is designed so **a failed update never
bricks it**. New firmware is always written to the *inactive* slot and only
becomes active once the adapter proves it can still drive the output; if it cannot,
the adapter restarts back into the version you were running. **A failed or
interrupted update does not leave you with a dead adapter.**

### 11.1 Over USB, from the app (in the car)

1. Open the **Update** screen.
2. **Check for updates** — the app compares the adapter against the published
   release (over the phone's own connection, which is why this works with no WiFi
   on the adapter).
3. If a newer release exists and it is built for this board, the app offers
   **Download and install** — it downloads the image, verifies it, and pushes it
   to the adapter over USB while showing a progress bar.
4. Or **Push a file over USB** to install an image you already have (a `.bin` from
   anywhere — Downloads, a USB stick).
5. When the push completes, **reboot the adapter** to run the new version.

The adapter **keeps serving button presses during the transfer** — the update
writes the inactive slot while normal operation continues on the active one.

Updates are refused, not forced, when they should not apply:

- a **downgrade** is never offered;
- an image built for **different hardware** is refused;
- a release that requires an intermediate version first (its `min_from_version`)
  is not offered, and the screen says why.

A corrupt image is refused and the running version is left untouched — nothing is
changed.

### 11.2 Over WiFi, from the maintenance page

With the adapter in **maintenance mode** and on a network (chapter 12), open its
setup page and use **firmware update** to either upload a file or **check for a
newer release** and pull it down over the network. This uses the same verification
as the USB path.

### 11.3 What keeps it safe

| Guarantee | How |
| --- | --- |
| Never install an unverifiable image | SHA-256 is checked as the image is written; a mismatch discards it and keeps the old image |
| Never brick on a bad image | Two app slots; a new image must confirm health before it becomes the default — otherwise the adapter rolls back |
| Never lose your configuration | Your configuration lives in separate storage, untouched by any update |
| Never drive a stuck key during an update | The running image keeps the safe idle state throughout |
| Never offer an incompatible jump | The release manifest carries a minimum source version |

## 12. Maintenance mode — WiFi and Bluetooth setup

**The adapter's radio is OFF in normal operation.** WiFi and Bluetooth are started
only inside a **maintenance window**, and fully shut down when the window closes.
This is deliberate: the adapter sits on a car's electrical system and its only job
is to pass button presses. A radio that is idle-but-initialised still costs power
and memory and still has a radio on — so it stays off.

A maintenance window is how you **get the adapter onto WiFi** (for firmware
updates) and **reach its setup page**.

### 12.1 Opening the window

| How | Notes |
| --- | --- |
| **Hold AUX1 for ~3 s** on the device | Works with **no app** — the fallback when you are at the car |
| **"Enter maintenance mode"** in the app's Link screen | The primary way when a phone is connected |
| **A configuration flag** | `maintenance_on_boot` — opens the window on the next boot only |
| **First-ever power-on with no config** | The adapter offers setup the first time it boots with nothing saved |

The window closes on its own after a period of inactivity (default **5 minutes**,
configurable), or immediately on exit. On close the radio shuts down and the adapter
returns to normal. The STATUS LED stops its double-flash.

### 12.2 Setting up WiFi and Bluetooth

The adapter uses **Bluetooth provisioning** (Espressif's scheme), so you can get it
onto a network with the **Espressif provisioning app**:

1. Open a maintenance window.
2. In the app's Link screen, read the **Bluetooth name** and the **BLE passcode**
   (both shown only while the window is open and the radio is up). The board has no
   screen, so the app is where these per-device secrets are shown — over the
   already-trusted USB link.
3. In the Espressif app, find the `SWC-…` device and enter the passcode when asked.
4. Enter your WiFi SSID and password.

### 12.3 The setup page

The adapter also serves a small **setup page** while its radio is up. The app's
Link screen shows the page's URL (with its access token). The page shows device
status and offers **WiFi setup** and **firmware update**. It is **not** a
configuration UI — the app owns configuration; the page exists to get you online
and updated.

The page requires a **token** (carried in the URL the app shows). There is no
default password.

> The window and the radio are separate states. If the adapter is in maintenance
> mode but its radio could not start, the app says so plainly rather than handing
> you a setup page that is not there.

## 13. Troubleshooting

| Symptom | Likely cause and fix |
| --- | --- |
| **Held AUX1, did a single/double/long on a button I had *not* learned, released — nothing happened** | Programming holds a voltage for a button the adapter already knows. If the button has no learned level there is no band to place the gesture's voltage in, so nothing is driven. **Learn the button first** ([§8.1](#81-learning-the-buttons)), then program it ([§8.2](#82-programming-a-gesture-no-app-needed)). |
| **Held AUX1 to program a gesture and expected a "saved" beep** | `PROGRAM_SAVED` is never played by this adapter (chapter 7.3). The confirmation here is the head unit capturing the held voltage, then `LEARN_OK` on release — there is no escalating beep count. |
| **A learned button is recognised but the stereo does nothing new** | A button you have only *learned* passes its single level through; its double/long need **programming** (§8.2) or an app **binding** (chapter 9). |
| **Pressed a button to program it and the head unit reacted instead** | Your press was treated as a real press, not a learn — the AUX1 hold had not armed first. Hold AUX1 for the full ~1.5 s (until `PROGRAM_ENTER` beeps) *before* pressing the wheel button. |
| **`OUT_VOLTAGE` had no effect on the radio** | The `key_mv` is probably above the head unit's own idle (so the line was released, not driven) or on a level the radio reads as a different key. Move it lower within the band (chapter 9.3). |
| **App says "No device found"** | Cable not connected, adapter unpowered, or no OTG support. Check the USB-C cable and that the adapter has power. The adapter still works without the app. |
| **App says "USB permission needed"** | Allow the Android USB prompt; replug the adapter to re-trigger it. |
| **App says "That is not the adapter"** | Another USB device is sharing the hub. Unplug it and retry. |
| **App says "Firmware and app versions differ"** | The app and adapter protocols disagree, so nothing is sent (a partial match corrupts configs). Update the app or the firmware so both match. |
| **App says "The adapter stopped responding"** | It answered then went quiet for 10 s. Check the cable and power — **a button press still works even while the app cannot see it.** Reopen the app or tap Try again. |
| **STATUS LED fast-blinking** | A fault. Listen to the buzzer: `FAULT_DAC` (output/DAC), `FAULT_CONFIG` (configuration corrupt — defaults loaded), `FAULT_INPUT` (ladder/rail wiring fault). A configuration fault clears once a good config is written; a hardware fault needs a restart and a wiring check. |
| **Buzzer plays `FAULT_INPUT`** | An open input or a short to a supply on the ladder wiring. Check `J2`/`J5` wiring. |
| **`KEY_UNKNOWN` on a button you pressed** | That button has not been learned (or the press did not match its window). Learn it (chapter 8). |
| **A button does nothing** | It is learned but its gesture is not **programmed** (§8.2) and not **bound** (chapter 9), so the adapter is presenting the gesture's default voltage and the *head unit* decides the effect — and a head unit that was never taught that voltage does nothing. Program the gesture, or bind it to a `key_mv`. |
| **App warns "lost frames"** | A flaky USB cable. Re-seat it and retry the operation; a dropped frame can make a command fail with no error otherwise. |
| **A button's action did not run** | The **phone's** half of an app-side action failed (a permission, a missing app). The adapter still sent the key press; the button itself is configured correctly. |
| **Learn keeps rejecting (`LEARN_REJECT`)** | The press was too light (barely left idle) or too noisy. Press the button firmly and hold it steady while AUX1 is held. |
| **The adapter behaves as if a button is held** | Check the ladder wiring — an open input can float high. Restart the adapter; it re-establishes the safe idle state on every boot. |
| **Nothing responds at all** | Press **RESET**. The adapter comes back in its safe idle state and resumes. |

## 14. Settings reference

Settings live in the adapter's configuration. They are written as part of a config
save; the app's screens cover bindings and the maintenance window, while the
timing/gain/feedback settings below are carried in the configuration and honoured
by the adapter.

| Setting | Default | Meaning |
| --- | --- | --- |
| `debounce_ms` | 25 | Contact debounce for a press |
| `double_press_off_ms` | 500 | Window in which a second tap counts as a **double** |
| `long_press_ms` | 750 | Hold time that counts as a **long** press |
| `send_duration_ms` | 200 | How long a presented key is held (bounded) |
| `gain_policy` | `AUTO` | Output range: `AUTO` detects the head unit; force **tracking** (3 V, gain 1.00) or **amplified** (5 V, gain 1.82) to override |
| `buzzer_level` | 2 | `OFF` / `QUIET` / `NORMAL` / `LOUD`. `OFF` silences everything except `BOOT_ERROR` and `FAULT_*` |
| `led_level` | 2 | `OFF` / `QUIET` / `NORMAL` / `LOUD` |
| `temp_comp_enabled` | — | Temperature compensation of the ladder (a stated v1 gap — see [CHANGELOG.md](CHANGELOG.md)) |
| `key_click_enabled` | **off** | Beep on every normal press, as a key-click confirmation. **Off by default** so ordinary switch operation stays silent; switch it on in the app if you want it |
| `maintenance_timeout_ms` | 300000 (5 min) | Maintenance window length; measured from the last activity (bounded to one hour) |
| `maintenance_on_boot` | off | Open the maintenance window on the next boot only |

Per-channel configuration includes the channel **name**, whether it is **enabled**,
its **learned ladder** (the buttons you taught), and its **output** profile (gain
mode and the idle DAC code).

---

*Connector pin details, the analog design, and the reasoning behind each choice are
in [DESIGN.md](DESIGN.md). Ordering and part information are in
[MANUFACTURING.md](MANUFACTURING.md). Revision history is in
[CHANGELOG.md](CHANGELOG.md).*

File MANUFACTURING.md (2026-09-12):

# Manufacturing — SWC Steering Wheel Controls Adapter

Sourcing, BOM generation, assembly cost and fabrication output. For the circuit
itself see [DESIGN.md](DESIGN.md); for the front page see [README.md](README.md).

Target: **JLCPCB, 4-layer, 5-off, Economic PCBA.** Both parts that had forced
Standard PCBA have now been cleared (see §3), so Economic is reachable — confirm
on the quote at order time.

- [1. BOM generation](#1-bom-generation)
- [2. Part list](#2-part-list)
- [3. PCBA type — the Economic/Standard decision](#3-pcba-type--the-economicstandard-decision)
- [4. Assembly cost](#4-assembly-cost)
- [5. Fabrication output](#5-fabrication-output)
- [6. Ordering decisions](#6-ordering-decisions)

## 1. BOM generation

The BOM is built by **parsing the schematic's own symbol properties**, because
`export_bom` emits only `Refs, Value, Footprint, Qty, DNP` — no LCSC or MPN.
Every one of the 101 placed symbols with a purchased part carries `LCSC`, `MPN`,
`Manufacturer` and `Datasheet`; the 8 test points carry none by design.

That yields **34 unique LCSC types across 96 packages**. Plus 4 mounting holes
and the copper logo gives the board's 104 footprints, which is why DRC reports
no parity error.

Two wrinkles worth knowing before regenerating it:

- `U6` is one quad TSSOP-14 package driven by a five-unit symbol, so its
  designator list must be deduped to `U6`, not `U6,U6,U6,U6,U6`.
- `J2`/`J3` and `SW1`/`SW2` share an LCSC code, so their BOM `Comment` falls back
  to the MPN — their schematic values are net names, not part names.

## 2. Part list

Extended-tier parts, most expensive first:

| Ref | Value | LCSC | Mfr | $/1 |
| --- | --- | --- | --- | --- |
| U4 | MCP4728T-E/UN | C478093 | Microchip | 2.6141 |
| U3 | ESPS3-32-N4 (ESP32-S3) | C49164655 | DOIT | 2.4787 |
| J5 | AUX_IN, 4P | C42377749 | Kangnex | 0.3250 |
| U6 | TLV9004IPWR (quad, 1 pkg) | C2058050 | TI | 0.2413 |
| J2, J3 | SWC_IN / SWC_OUT, 3P | C72334 | Kangnex | 0.2143 |
| L1 | 47 µH | C408471 | Sunlord | 0.1939 |
| BZ1 | TMB12A05 | C96093 | Huaneng | 0.1919 |
| J4 | USB-C 2.0 16P | C165948 | Korean Hroparts | 0.1856 |
| U8 | USBLC6-2SC6 | C7519 | ST | 0.1825 |
| J1 | 12V_DC_IN, 2P | C8465 | Kangnex | 0.1336 |
| C1, C2 | 100 µF/50 V | C46550415 | jieerrui | 0.0815 |
| F1 | 1.5 A, 1812 | C883154 | BHFUSE | 0.0792 |
| F2 | 1.0 A, 0805 | C46640991 | hongjiacheng | 0.0429 |
| RT1 | 10 k B3380 NTC | C316397 | Sunlord | 0.0179 |

Three *other* BOM parts are Preferred Extended and therefore already exempt on
Economic: C17840 (82 k), C19077573 (SMBJ18A) and C7420333 (BAT54S, five
placements). Seventeen more codes are Basic.

## 3. PCBA type — the Economic/Standard decision

This is a **different axis from the Extended tier above**, and it is the one that
decides which assembly service the order can use.

Every JLCPCB part carries a **`PCBA Type`** field, with two values:
`Economic and Standard`, or **`Standard Only`**. A single `Standard Only` part
forces the **whole order** onto Standard PCBA. Being *Extended* does **not** do
this — an Extended part with `Economic and Standard` is fine on Economic, it
just costs one feeders-loading fee (below). The tier tables in §2 and the fee
table in §4 say nothing about this flag; only the part's own page does.

The board had **two** `Standard Only` parts. Both are now cleared:

| Ref | Was | Now | PCBA type |
| --- | --- | --- | --- |
| C1, C2 | C3151829 (ROQANG RVT1H101M0607) | **C46550415** (jieerrui JVJ50V100M6x8) | `Standard Only` → **Economic and Standard** |
| U3 | C2913197 (Espressif ESP32-S3-WROOM-1-N4) | **C49164655** (DOIT ESPS3-32-N4) | `Standard Only` → **Economic and Standard** |

**C1/C2** are the same 100 µF/50 V, ±20 %, 2000 hrs @105 °C,
`SMD,D6.3xL7.7mm` part in the identical `CP_Elec_6.3x7.7` footprint — **no
layout change**. The replacement adds a published ripple rating (140 mA @120 Hz)
the ROQANG part never listed, and widens operation to −55…+105 °C. Alternatives
in the same class: C47023117, C3445238, C42389919, C2980173.

**U3** is a genuine drop-in, not a redesign. Every Espressif ESP32-S3 in the
WROOM-1, WROOM-1U and MINI-1 families is `Standard Only` (all nine WROOM-1
variants, all five WROOM-1U, all MINI-1), so the replacement is a third-party
module that clones the WROOM-1 land pattern. The DOIT `ESPS3-32-N4` is verified
against its own datasheet as identical on all three axes:

- **Size** 18 × 25.5 × 3 mm — the WROOM-1 drawing, same orientation, PCB antenna
  at the module top and therefore away from the pads.
- **Pinout** all 41 pins identical by number and function, including
  IO19 = `USB_D-`, IO20 = `USB_D+`, pin 15/16 = IO3/IO46, pins 36/37 =
  `RXD0`/`TXD0` (= IO44/IO43), pin 41 = `EPAD` (ground).
- **Land pattern** pad 0.85 × 1.2 mm on 1.27 mm pitch, 1.5 mm pad, 2.015 mm
  edge setback, EPAD span 10.29 mm offset 7.5 mm from the edge, nine 0.9 × 0.9 mm
  EPAD vias at 1.4/1.4/0.5 mm spacing.

So `RF_Module:ESP32-S3-WROOM-1` is the correct footprint for it and **no PCB
change is required**. Caveats to weigh before ordering, none of them mechanical:
it is a third-party module (single-source, 645 in stock vs the WROOM-1's 5084,
and DOIT's own FCC ID rather than Espressif's — relevant if the product is ever
certified); it is −40…+85 °C, the same as the WROOM-1; and DOIT has no module
with PSRAM that is `Economic and Standard`, so this route assumes 4 MB flash and
no PSRAM.

The only `Economic and Standard` alternative family is the **ESP32-C3-WROOM-02**
(C2934560, verified `Economic and Standard`), but it is a different, smaller
module (20 × 18 mm, 19 pads) and a different chip — no native USB-OTG
peripheral, a single core, and it does not support PSRAM — so it is a board
redesign *and* a firmware port. Not recommended.

**With both parts cleared, nothing on the BOM is `Standard Only`, so the order
should qualify for Economic PCBA.**

## 4. Assembly cost

The charge from JLCPCB is a **feeders-loading fee per unique Extended part
type** on Economic PCBA, **$3.07 each** as of its 2026-09-09 pricing table.
Basic parts are free, and Preferred Extended parts are exempt — but **only on
Economic**. Standard PCBA charges $1.53 on *every* part type including Basic, so
Economic is both cheaper per type and cheaper in setup ($8.18 vs $25.56) and
stencil ($1.53 vs $8.21).

This board has **14 Extended part types**, so the loading line is
**14 × $3.07 ≈ $43**.

The brief asked for Extended parts only when there is no alternative, so this was
tested rather than assumed. The **~$43 loading line itself** cannot be designed
away by substitution, and the earlier assessment that it could was wrong on both
count and premise. Thirteen of the fourteen sit in subcategories that contain
**no no-fee part at all**:

| Subcategory | Basic | Preferred | Extended |
| --- | --- | --- | --- |
| Screw Terminal Blocks | 0 | 0 | 1604 |
| USB Connectors | 0 | 0 | 6075 |
| NTC Thermistors | 0 | 0 | 1647 |
| Aluminum Electrolytic SMD | 0 | 0 | 5977 |
| Power Inductors | 0 | 0 | 863 |
| Resettable Fuses | 0 | 0 | 665 |
| Buzzers | 0 | 0 | 36 |
| WiFi Modules | 0 | 0 | 232 |
| DACs | 0 | 0 | 842 |
| TVS/ESD, SOT-23-6 | 0 | 0 | 24 |
| **Operational Amplifier** | **3** | **3** | 5153 |

The op-amp is the only category with no-fee stock, and the substitution still
fails: of the six no-fee op-amps, LM358 / LM2904 / NE5532 / MCP6002 are **dual**
(`U6` is one quad TSSOP-14, so each would become two packages and a board
change), LMV321 is a **single**, and LM324 is a quad but **not rail-to-rail** and
needs 3 V minimum, which breaks a 3.3 V single-supply rail-to-rail signal chain.
The nearest on paper is the MCP6002 — viable only as part of a deliberate
two-package redesign, not a substitution.

The ~$43 is therefore a **purchasing decision, not a design one**. (Note that
this is a separate question from §3: the loading line is what it is, but the
*service level* it is charged under is set by `PCBA Type`, not by the count.)

## 5. Fabrication output

Gerbers, drill, position files and the assembly BOM are produced by the kicad MCP
server's export tools with the project as the default export directory — see
[AGENTS.md](AGENTS.md) for the tool names. Export artifacts belong in `attic/` or
`/tmp`, not the repository root.

Board data: 54.00 × 102.00 mm outline, 4-layer (F.Cu / In1.Cu / In2.Cu / B.Cu),
1.6 mm, rounded corners r ≈ 2.83 mm, five copper zones. Fabrication and
solder-mask minimums are in [DESIGN.md §5](DESIGN.md#5-design-rules-and-stackup).

## 6. Ordering decisions

### 4-layer vs 2-layer

The board is already 4-layer. Whether the delta is worth it is an ordering
decision, and it is not obvious from the ordering page: a 54 × 102 mm outline is
outside JLCPCB's ≤100 × 100 mm promotional tier and is area-priced, so the
difference shown **may not hold**.

Reaching 100.000 mm in y means finding 2.000 mm, and the copper is not there:

- the nearest copper above is `U3`'s pad copper edge at y 32.290 — 1.290 mm of
  margin;
- below is a trace at y 132.002 — 0.998 mm.

Taking it off the bottom alone breaks the clearance rule before the trim is half
done. Measure pad **edges**, not centres, or the margin is overstated by
0.450 mm. This is reported as a priced option only; **nothing was changed to
chase it**, and the trim should not be attempted unprompted.

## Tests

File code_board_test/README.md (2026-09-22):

# SWC adapter — bring-up and hardware-test firmware

A PlatformIO project that turns a freshly-assembled **SWC steering-wheel-controls
adapter** board into a self-testing bench instrument. It runs one hardware
function at a time, prints what it measured, and says whether that is what the
design predicts.

This is **not the product firmware**. The product lives in
`../code` (ESP-IDF, TinyUSB CDC link to an Android head unit).
Nothing here ships.

| | |
| --- | --- |
| **Board** | 54 × 102 mm, 4-layer, ESP32-S3 (DOIT ESPS3-32-N4), MCP4728 DAC, TLV9004 servos |
| **Framework** | Arduino (deliberate — see below) · ESP-IDF 5.5.5 underneath |
| **Tests** | 32 on-device + 48 host unit tests |
| **Console** | ROM USB-Serial-JTAG (`ARDUINO_USB_MODE=1`) |
| **Front ends** | serial menu **and** web page — both optional, both drive the same tests |

---

## Contents

- [Quick start](#quick-start)
- [Why these choices](#why-these-choices)
- [How to step through it](#how-to-step-through-it)
- [The wiring: what to attach when](#the-wiring-what-to-attach-when)
- [The 30 tests](#the-30-tests)
- [Reading a result](#reading-a-result)
- [What is machine-checked and what is not](#what-is-machine-checked-and-what-is-not)
- [Where every constant came from](#where-every-constant-came-from)

---

## Quick start

```sh
# 1. Host unit tests — no board needed, ~2 seconds
pio test -e host

# 2. Build for the board
pio run -e swc-s3-test

# 3. Flash (hold BOOT only if the ROM loader does not catch the reset)
pio run -e swc-s3-test -t upload --upload-port /dev/tty.usbmodem113101

# 4. Open the menu
pio device monitor -b 115200 -p /dev/tty.usbmodem113101
```

The board prints a boot banner, brings up the ADC and the DAC, blinks both LEDs
twice, and then presents a menu. Type a **test number** and press ENTER.

WiFi credentials are read from `../code/.env` at build time by
`tools/gen_secrets.py` and written to a **git-ignored** `include/Secrets.h`.
Nothing in this repository contains a credential. If the `.env` is missing the
build still succeeds and test 25 reports "not configured".

---

## Why these choices

**Arduino, not ESP-IDF.** The product firmware is IDF and should stay that way.
This tool needs a serial menu, an HTTP page and a WiFi client with minimum
ceremony, and it never ships. One consequence is worth stating because it is the
only place the two diverge in a way that could mislead: the *analog measurements*
do **not** use Arduino's `analogRead()`. They use the ESP-IDF `adc_oneshot` +
`adc_cali` path directly (`src/Adc.cpp`), because Arduino's wrapper hides whether
the eFuse calibration was actually available — and that is a fact this tool exists
to report.

**Console on USB-Serial-JTAG, not TinyUSB.** The ESP32-S3 has **one internal USB
PHY**, shared between the ROM's USB-Serial-JTAG peripheral and the USB-OTG
controller TinyUSB drives. Only one can be active (spec §4.1). The product puts
its link on TinyUSB, which means **a production build has no console at all** —
the message reporting a link failure is itself unreadable. This tool takes the
other one on purpose: USB-Serial-JTAG enumerates before `setup()` runs, survives a
crashed application, and is the peripheral ROM download mode uses, so a bad build
can always be reflashed and always be read. Test 24 documents this rather than
performing the handover, because a handover mid-suite would kill the console and
take the remaining tests with it.

**Two front ends.** A serial-only tool goes dark whenever the native USB
re-enumerates (any reboot, any crash), and this board has no UART header to fall
back to. A web-only tool cannot test the radio that serves it. So both exist,
driving the same registry through the same runner.

---

## How to step through it

### Serial menu

```
  type a NUMBER to run that test (1-30)
  a  = run all, in order        s  = summary
  c  = clear the capture buffer n  = reprint this menu
  r  = reset all outcomes       w  = web UI address
  ?  = full detail for every test (what each needs)
  h  = hardware info dump
```

Every command prints a **result line** and then reprints the menu, so you always
know where you are:

```
TEST 14  Channel 1 loopback: SWC_OUT1 to SWC_IN1
  covers: End-to-end: DAC -> servo -> Q4 -> KEY1 -> SWC1 -> R1 -> ADC
  needs : JUMPER from J3 pin 3 (KEY1) to J2 pin 3 (SWC1)
------------------------------------------------------------------------
  [ok]   released: SWC_IN sits high on its 10k pull-up (the ladder is released)
  [ok]   driving the output pulls SWC_IN materially down (press direction)
  [ok]   SWC_IN falls monotonically as the commanded KEY voltage rises
------------------------------------------------------------------------
RESULT 14: PASS  (412 ms)  all checks passed
```

### Web UI

Once WiFi associates the menu prints an address:

```
  web UI:  http://192.168.2.x/
```

That page lists every test with its **needs** column, a clickable link per test,
a live log pane that refreshes every 2 s, and buttons for *Run all 30*,
*Summary*, *Clear log* and *Identify*. It survives USB re-enumeration, which the
serial menu does not — so if the serial console drops part-way through a run, the
log is still there.

Tests requested from the web page are **deferred** to `loop()` rather than run
inside the HTTP handler, because test 30 takes minutes and running it inline would
block the response for that whole time.

---

## The wiring: what to attach when

You do not need everything at once. The tests are grouped by what has to be
attached, and that grouping is the recommended order.

```
                 ┌─────────────────────────────────────────────┐
   J1  +12V ─────┤ 1=GND  2=+12V      (OPTIONAL — USB powers it)│
                 │                                             │
   J2  SWC in ───┤ 1=GND  2=SWC2  3=SWC1                      │
                 │                                             │
   J3  SWC out ──┤ 1=GND  2=KEY2  3=KEY1                      │
                 │                                             │
   J5  AUX in ───┤ 1=GND  2=AUX3  3=AUX2  4=AUX1              │
                 └─────────────────────────────────────────────┘
                J4 USB-C  (power + console + flasher)
```

| Stage | Attach | Run | Why |
| --- | --- | --- | --- |
| **1** | *nothing* | 1–10 | power, identity, GPIO, I2C, DAC, ADC calibration |
| **2** | *J3 open* | 11 | the sense path, floating |
| **3** | a voltmeter on J3.3 / J3.2 | 12–13 | the servos, open-loop |
| **4** | **jumper J3.3 → J2.3** and **J3.2 → J2.2** | 14–15 | the whole analog chain, end to end |
| **5** | the vehicle button pod on J2 (or nothing) | 16–18 | ladder inputs, AUX, NTC |
| **6** | *listen / watch* | 19–20 | buzzer, LEDs |
| **7** | stage-4 jumpers + a 10 kΩ pull-up J3.3→3V3 | 21–23 | gain auto-select, trim loop, idle safety |
| **8** | *nothing* | 24–26 | USB, WiFi, NVS |
| **9** | stage-4 jumpers | 27–28 | press shaping, full sweep |
| **10** | jumpers as each step asks | 29 | connector continuity |
| **11** | both jumpers | 30 | endurance (minutes) |
| **12** | 3 test wires + something warm | 31–32 | AUX driven automatically, RT1's curve |

**The one jumper that matters most** is stage 4. Two wires:

```
   J3 pin 3 (KEY1) ────── J2 pin 3 (SWC1)
   J3 pin 2 (KEY2) ────── J2 pin 2 (SWC2)
```

That single loop closes the entire signal chain — DAC → integrator → sink FET →
KEY line → series resistor → ADC, with the sense buffer in parallel — so tests 14,
15, 22, 27, 28 and 30 all become possible with no head unit and no meter. It is
also the **only** way to test the input voltage sensing without a vehicle.

### If a test says a jumper is missing

Several tests check for their own prerequisites first and report `BLOCKED` with
the reason rather than failing on a downstream measurement. If test 14 reports
that SWC1 does not read high with the output released, the jumper is not fitted —
that is the diagnosis, not a board fault.

---

## The 30 tests

| # | Test | Needs | Asserts |
| --- | --- | --- | --- |
| 1 | Boot identity, flash, PSRAM, heap | — | 4 MB flash, **no PSRAM**, ESP32-S3 silicon, no panic reset |
| 2 | Rails, VBUS detect, NTC reference | USB or J1 | `/VBUS_VALID` divider, pulled-up inputs rest high |
| 3 | Spare test-point GPIOs | — | each follows both internal pulls; **pairwise short test** |
| 4 | I2C scan + DAC address | — | a device answers; adopts a non-0x60 strap (spec N-4) |
| 5 | DAC write / read-back | — | 7 codes round-trip; frame is **3 bytes** |
| 6 | DAC power-down modes | — | all four PD1:PD0 modes read back |
| 7 | ADC calibration + stability | — | eFuse curve-fit or the **reported** fallback; channel settling |
| 8 | Every ADC input is live | jumper (opt.) | all 8 inputs in range; pull-ups alive |
| 9 | DAC EEPROM power-on state | — | what a cold start would actually do |
| 10 | `~LDAC` idle-high, never pulsed | — | two channels hold **independent** values |
| 11 | Sense path | J3 open | readings captured; channel-to-channel comparison |
| 12 | Servo channel 1 | voltmeter J3.3 | sweep both modes; **gain ratio is 1.82, not 1.812** |
| 13 | Servo channel 2 | voltmeter J3.2 | same, channel 2 |
| 14 | **Loopback ch 1** | jumper J3.3→J2.3 | released = high; driving = pulled down; **monotonic** |
| 15 | **Loopback ch 2** | jumper J3.2→J2.2 | same, channel 2 |
| 16 | SWC ladder inputs | pod (opt.) | idle is the HIGH state; `R_ladder ≤ pullup·7.25` |
| 17 | AUX1–AUX3 | jumper (opt.) | all idle high; **AUX1 (the programming button) alive** |
| 18 | NTC temperature | — | plausible °C; **the cost of a wrong rail assumption** |
| 19 | Buzzer | listen | gate toggles; rhythm **+ a 200 Hz–5 kHz sweep**; sound = operator |
| 20 | LEDs | watch | both polarities; **1–60 Hz pulse sweep**; which lit = operator |
| 21 | Gain auto-selection | loopback + pull-up | envelope, guard band, **safe 1.82 default** |
| 22 | Servo trim loop **and response time** | loopback | bounds are the spec's; loop **disabled**; **settles inside the 200 ms key-send budget**, and a 120 ms double press resolves as two keys |
| 23 | **Idle is high-Z** | loopback + pull-up | release needs no mode; sink-only proven both ways |
| 24 | USB link configuration | — | console is on the recoverable peripheral |
| 25 | WiFi radio + credentials | AP in range | **radio / scan / association** reported separately |
| 26 | NVS | — | `nvs_set`=0; `nvs_get`=length; **never truncates** |
| 27 | Press classification | loopback | single/double/long shapes present in real samples |
| 28 | Full pass-through sweep | both jumpers | whole chain, both modes, command-tracking |
| 29 | Connector continuity map | jumpers | all 5 inputs alive; outputs independent |
| 30 | Endurance | both jumpers | repeatability, write errors, **self-heating** |
| 31 | **AUX1-AUX3 driven low and released** | 3 test wires (see below) | each input **collapses and recovers**, unattended |
| 32 | RT1 temperature scale | something warm (optional) | **two-point beta** — the curve, not one plausible reading |

Run them in the numbered order on a fresh board — the early tests establish the
preconditions (power, DAC, ADC calibration) that the later ones are read through.

---

## Reading a result

| Result | Meaning |
| --- | --- |
| `PASS` | every assertion held |
| `FAIL` | an assertion failed — the summary line carries the **first** failure and its numbers |
| `BLOCKED` | a *precondition* was absent (no DAC, no jumper). The premise is void; fix the note and re-run |
| `SKIP` | ran, but the condition under test was not present |
| `WARN` | measured, outside the expected window, not a defect |

Three conventions worth knowing:

**Numbers, not adjectives.** `[FAIL] measured 4550, wanted 2500 +/- 2 (off by 2050)`
— the failure tells you what it saw.

**The first failure wins the summary.** The one-line summary a table shows is the
*root* failure, not the last thing that happened to be checked.

**`note:` lines are prose, not assertions.** They explain a measurement, name the
suspects when something failed, and say when a surprising reading is actually
correct. Read them — the important caveats live there.

### Two examples of a note doing real work

Test 11, with J3 open:
> `With nothing on J3 the KEY lines float near 0 V (no pull-up of their own), so a
> near-zero reading here is CORRECT, not a dead channel.`

Test 21, no head unit:
> `an out-of-envelope measurement must NOT be classified, and the asymmetry
> defaults to 1.82 because over-ranging a 3 V unit is the only dangerous mistake.`

Both are cases where the *correct* result looks like a fault. Saying so is the
difference between a tool and a red light.

---

## What is machine-checked and what is not

The board can see its own pins and its own ADC/DAC. It cannot see light, hear
sound, or know whether a wire is attached. Every test says which half is which
rather than implying a completeness it does not have.

| Machine-checked | Operator-checked |
| --- | --- |
| pin levels, pull-ups, bridges | whether an LED lit |
| ADC readings and their ranges | whether the buzzer sounded |
| DAC write/read-back and gain modes | which LED polarity phase lit it |
| the full analog chain (via loopback) | whether a jumper is actually fitted |
| NVS, WiFi association, USB config | — |

The operator-checked tests still do everything they can: test 20 drives **both**
polarities so a wrong `LED_ON` looks like a polarity bug rather than a dead LED,
and test 19 drives a rhythm before asking.

---

## Where every constant came from

No hardware fact in this project was inferred from prose or from a part name.
Each was read from a primary source and is cited at its definition.

| Source | What it is | Used for |
| --- | --- | --- |
| `../production/netlist.ipc` | IPC-D-356 netlist exported from the live PCB | **every pin assignment**, including that `R15`/`R16` return to net `3V3` and not 12 V |
| `../DESIGN.md` | engineering description | topology, divider ratios, the servo relation |
| spec §2.1–2.5 | the firmware spec's verified hardware contract | pin map, DAC frame, envelope, guard band |
| `../code/lib/HAL/*` | the product's own HAL | the NVS contract, the DAC frame history |
| `../code/lib/HAL/DacFrame.h` | the product's frame encoder | the **3-byte** Multi-Write layout |
| `DS22187E` (MCP4728) | the DAC datasheet | PD1:PD0, channel-select, read-back layout |
| installed Arduino-ESP32 3.3.11 / IDF 5.5.5 | the actual toolchain | API signatures, enum names |

Where the sources disagreed, the **netlist won**. That rule is not decorative:

- `DESIGN.md` §4.1 once claimed the ladder is "pulled to 12 V when idle". The
  netlist shows the pull-ups on net `3V3`. An inverted topology would make every
  press-direction assertion backwards.
- The product firmware once shipped a **4-byte** MCP4725-shaped frame, so no DAC
  channel was ever addressed and nothing reported an error. The 3-byte layout is
  pinned by host tests (`test_host/test_dacframe`) that assert every byte.
- The product firmware once selected tracking mode **without writing the ADJ
  channel's code**, driving a 3 V head unit at 1.82× — the dangerous direction —
  while every power-mode check still read correct. In this project that bug is
  **unrepresentable**: `Dac::SetSignal()` is the only way to change a channel, and
  it always writes both halves.

That last one is the design principle throughout: where a defect is known, prefer
making it impossible to express over documenting the rule that avoids it.

---

## Repository layout

```
platformio.ini              two envs: swc-s3-test (device), host (unit tests)
boards/swc-s3-test.json     board definition (4 MB, no PSRAM)
include/
  BoardPins.h               every pin and constant, each with its provenance
  Adc.h  Dac.h  Log.h       the device-side modules
  TestRunner.h              the registry and the assertion helpers
  Secrets.h                 GENERATED, git-ignored — never commit
lib/swc_logic/              pure logic, host-testable, no Arduino/IDF
  DacFrame.h                the MCP4728 wire frames
  Output.{h,cpp}            servo transfer function, gain selection, command band
  Temp.{h,cpp}              NTC math
src/
  main.cpp  FrontEnd.cpp    entry points, serial menu, web UI
  TestRunner.cpp            the runner and assertions
  tests/
    TestDecls.h             declarations shared by the registry and the bodies
    TestList.cpp            THE ordered registry — tests 1..30
    TestsA/B/C.cpp          the bodies
test_host/
  test_dacframe/  test_output/  test_temp/   48 host unit tests
tools/gen_secrets.py        .env -> include/Secrets.h, pre-build
```

Each host suite is its own directory because PlatformIO builds **one binary per
suite**; three files in one directory would collide on `_main`, `setUp` and
`tearDown`.

---

## Test 31's rig: three wires, then it runs unattended

```
   J5.4 (AUX1)  <-->  IO43 / TP7
   J5.3 (AUX2)  <-->  IO21 / TP6
   J5.2 (AUX3)  <-->  IO16 / TP5
```

**The order does not matter.** Test 31 *discovers* which spare pin reaches which AUX
input before it measures anything, so any input may go to any test point. That is not
a convenience — the first version hard-coded the pairing, the real rig had two wires
crossed, and it reported "no response" for two perfectly healthy lines. The `p` menu
probe prints the measured response matrix if you ever want to see it.

With the wires fitted, test 31 **drives its own stimulus**: pulling the spare pin LOW
pulls the AUX input to GND (the "button pressed" state), and floating it lets the
board's own 10 kΩ pull-up set the level (released). No operator prompts, **~400 ms
instead of ~180 s**.

Without the wires it reports **SKIP** rather than failing; with only some fitted,
**WARN** naming which responded.

**IO43 is safe to drive here.** It is UART0 TX, but this build sets
`ARDUINO_USB_MODE=1`, so the console is the USB peripheral and UART0 is free. Two
things had to be got right for it to work as a stimulus: `gpio_reset_pin()` to detach
the UART peripheral from the pad, and `gpio_set_pull_mode()` (not `pinMode`) to clear
an internal pull that an earlier test had left on it.

**Measured on this board:** IO21→AUX2 and IO16→AUX3 both work. **IO43/TP7 drives
correctly** (its pin reads back HIGH=1/LOW=0) **but pulls no AUX input**, so the wire
from IO43 to AUX1 is not making contact — the board and the firmware are both fine,
and test 31 reports WARN naming AUX1 as unexercised.

## Findings from the first bring-up (2026-09-21)

All 30 tests pass on the assembled board. Three things were learned that the tests
now encode, and one that is worth knowing about the hardware.

**The KEY line does not rest at 0 V.** With J3 open the line has *no* pull-up of its
own — the 3V3 pull-ups are on the ladder pins, not here — so it settles at ~3.26 V
(R36's 1 M path and the op-amp bias), and `Q4` can only *sink*. That level is the
**ceiling** on what the servo can command on an open line: any target above it makes
the servo turn the FET off and float the line, which is the *release* behaviour and
not a fault. Several tests originally asserted against fixed expected voltages and
reported a correctly-released line as broken. They now measure the float level
(`include/KeyLine.h`) and derive their command ceiling from it, which is what the
real firmware must do anyway (spec 6.2's headroom rule).

**The MCP4728's read response is not laid out as the datasheet phrasing implies.**
Mapping it with four distinct per-channel patterns showed a **6-byte stride** —
A at byte 2, B at 8, C at 14, D at 20 — not the 2-byte stride that "each channel is
two bytes" suggests. The decoder, and the host tests that pin it, were corrected to
the measured layout. Separately, **the power-down field could not be located at
all**: writing all four `PD1:PD0` values changes no byte in the response. That field
is therefore reported `UNKNOWN` and never asserted against — and the mode is instead
verified *behaviourally*, by the KEY voltage it produces, which is stronger evidence
anyway.

**Through the loopback, `KEY` and `SWC` are the same node.** So `SWC` *tracks* the
command and rises with it — the opposite of the vehicle case, where a button pulls
the ladder down. One test had the sign inverted from reasoning about the real
system and applying it here.

Hardware note, not a fault: **BZ1 is an *active* buzzer** (Huaneng TMB12A05) with its
own oscillator at a fixed ~2.4 kHz, so it cannot follow a drive frequency. The
200 Hz–5 kHz sweep is kept anyway — it exercises the drive path across the audio
band, and a passive buzzer (which *can* follow it) is a likely future change, so the
capability is tested now and will already be correct when the part changes.

## Web UI and the serial monitor

**The web UI.** A sticky status bar at the top is always visible: a pulsing dot and
"Running test N" while work is in flight, "Ready" otherwise. When a test needs you,
a yellow **Action required** banner appears with the exact instruction and a
**Done — continue ▶** button. Tests are clickable rows; long ones show `RUNNING` in
the table.

**Why it used to lock up, and what actually fixed it.** Tests ran synchronously
inside `loop()`, so for the whole duration of a test (9 s for test 20, 12 s for test
22, up to 90 s for the operator tests) the HTTP server was never serviced — the page
could not load, could not refresh, and clicks did nothing. Patching around that (a
pump inside the wait, a deferred-request flag, a spinner) treated the symptom.

The fix is architectural: **tests run on their own FreeRTOS task**
(`include/TestTask.h`), while `loop()`'s task does only the web server and the serial
menu. A test can now block as much as it likes. The page polls `/state` and
re-renders from the server's own answer, so a dropped request self-corrects instead
of leaving the page stuck — and it reloads **once**, only when a test *ends*.

**The serial monitor shows nothing until you type.** The board cannot detect that a
terminal *attached* — USB-Serial-JTAG gives no such event — so a monitor opened on an
already-running board sees a blank screen. Type any character and the menu appears.
The menu prints before the WiFi association too, so a monitor attached at power-on
sees it immediately rather than after up to 15 s of silence.

**Two more stale behaviours that are not faults:

**The serial monitor shows nothing until you type.** The board cannot detect that a
terminal *attached* — USB-Serial-JTAG gives no such event — so a monitor opened on an
already-running board sees a blank screen. Type any character and the menu appears
(with a note saying so). The boot banner is not resent, because there is nothing to
resend it to. The menu also prints *before* the WiFi association now, so a monitor
attached at power-on sees it immediately instead of after up to 15 s of silence.

**Clicking a test in the web UI takes up to ~15 s to show anything.** A test runs
synchronously, so while one is running the HTTP server does not answer — the page
shows a "working..." status and picks up the result when it finishes. That is by
design; see below.

**The real bug: a web-triggered test used to wedge the HTTP server permanently.**
Running a test from `/run` left a half-closed client connection that the Arduino
`WebServer` never recovered from, so HTTP stayed dead *indefinitely* — while the
identical test run from the serial menu was fine. That asymmetry is what located it.
Fixed by responding, releasing the socket, and only then running the test. Verified:
after a web-triggered run the page is unreachable for the duration and then returns
200 again.

The page also no longer reloads on click. A reload issued while the server is busy
hangs for the whole test, which is exactly what "clicking does nothing" looked like.
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

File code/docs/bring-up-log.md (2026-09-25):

# Bring-up log — SWC adapter firmware

Task 1 (PlatformIO environment for the ESP32-S3). Measurements here are
**observed**, not derived. Every number below came out of a real command run on
this machine on 2026-09-18; re-run the command rather than trusting the figure.

## Resolved toolchain

| Item | Value | Source |
| --- | --- | --- |
| PlatformIO Core | 6.2.0 (`/opt/homebrew/bin/pio`) | `pio --version` |
| Platform | pioarduino `espressif32` **55.03.311** | build header |
| `framework-espidf` | **3.50505.0 (IDF 5.5.5)** | build header |
| Toolchain | `toolchain-xtensa-esp-elf @ 14.2.0+20260121` | build header |
| `tool-scons` | 4.41101.0 (SCons 4.11.1) | build header |
| Host Python | 3.14.7 | `python3 --version` |

Build succeeds: `pio run -e esp32s3` → `[SUCCESS]`.

## size-baseline:

`size-baseline: text=156257, data=59116, bss=375761, dec=591134 (0x9051e) bytes — firmware.elf, pio run -e esp32s3 -t size, 2026-09-18`

The linked `firmware.bin` is **215,488 bytes** (0x349C0) — a scaffolding image
with no application code, so this is a floor, not a budget. Every later budget
comparison is against these numbers.

App partition is **1920 KB (1,966,080 bytes)** per slot; the scaffolding image
occupies 10.96 % of one slot. **Note the slot is 1920 KB, not the 1952 KB the
spec §9.2 states** — see "Defect 2" below.

## The Xtensa toolchain is DELETED on every build (Defect 1's sibling)

**Symptom:** `Error: Missing toolchain directory 'None'`, or with `-v` a
`FileNotFoundError: ... 'package-postinstall.py'`. It recurs on every build, and
retrying does not help.

**Three defects stack here. The third is the one that wastes an hour.**

1. **`platform.json` points at a 2-FILE STUB.** The pioarduino registry zip
   (`.../0.0.1/xtensa-esp-elf-14.2.0_20260121.zip`) unpacks to `package.json` +
   `tools.json` and nothing else — 4,133 bytes, no `bin/`. Exactly the
   `tool-scons` stub of Defect 1, now on the toolchain. `install_required_packages`
   reports success and leaves an unusable directory.

2. **The version strings disagree, so the check never passes.** Both halves were
   measured:

   | Source | Says |
   | --- | --- |
   | `platform.json` `package-version` | `14.2.0+20260121` |
   | the stub's `package.json` | `14.2.0+20260121` |
   | the crosstool-NG tarball's own `package.json` | `14.2.0_20260121` (underscore) |
   | IDF's own install (`.piopm`) | `14.2.0+20260121` |

   So `_check_tool_version` can never be satisfied by anything the tarball
   provides: a manual install always mismatches, and PlatformIO then runs
   `safe_remove_directory` and re-unpacks the stub. **Deleting the tool is the
   steady state, not a transient fault.**

3. **IDF and PlatformIO install the same toolchain under DIFFERENT names.** IDF's
   `idf_tools.py` (driven by `_run_idf_tools_install`) puts a complete, working
   toolchain at `~/.platformio/packages/xtensa-esp-elf/` — note, **no
   `toolchain-` prefix** — with the correct `package.json` version. The
   PlatformIO/CMake side resolves `toolchain-xtensa-esp-elf`. So a fully working
   compiler can be sitting right there while the build reports it missing. That is
   the red herring: the fix looks like "reinstall the toolchain" when the
   toolchain is fine and simply is not where the build looks.

**The fix** (keep the working one, put it where it is expected, label it with the
exact string the checker wants):

```
cp -R ~/.platformio/packages/xtensa-esp-elf/* ~/.platformio/packages/toolchain-xtensa-esp-elf/
# then set package.json "version" to EXACTLY "14.2.0+20260121"
```

Verified: two consecutive `pio run -e esp32s3` builds succeed and the toolchain's
`bin/` stays at 116 entries. Before the label fix, every build emptied it.

**The label is load-bearing.** It looks like a cosmetic edit and it is not: it is
what makes `_check_tool_version` return true, which is the early-return that
skips the destructive reinstall.

### `IDF_MAINTAINER=1` is needed for the build

IDF's `tools/cmake/tool_version_check.cmake` runs
`idf_tools.py check-tool-supported`. **This IDF does not implement that
subcommand** — it exits with an argparse error, the check reads the empty stdout
as "unsupported", and it raises a FATAL_ERROR naming
`Tool doesn't match supported version from list ['esp-14.2.0_20260121']`. The
installed compiler *is* that version; the check cannot tell, because its own
helper is missing. The check's message documents the override, so builds here run
as `IDF_MAINTAINER=1 pio run -e esp32s3`.

Neither edit is in the repo (they live in the PlatformIO package cache), so
**neither survives a platform reinstall and neither is reproduced by a fresh
clone.** If the toolchain error reappears, apply both before debugging anything
else.

## size-after-tasks-1-14b: the real number

`size-after-tasks-1-14b: text=218361, data=71716, bss=531253, dec=821330 (0xc8852) bytes — firmware.elf, pio run -e esp32s3 -t size, 2026-09-19`

`firmware.bin` is **290,045 bytes** — 14.8 % of the 1,966,080-byte slot. This
supersedes the scaffolding figure above as the comparison baseline: Tasks 1–14b
are implemented (HAL, orchestrator, gesture, config, NDJSON, feedback, EspHal)
and this build *does* link them, which the scaffolding build did not.

**Read this number carefully, because it proved to be a trap.** The step from
215,085 → 289,789 bytes was the FIRST evidence that `lib/` had finally been
compiled into the image (Defect 44): an eleven-task build had previously weighed
exactly what a one-task build weighed, because IDF's component model was never
told that `lib/` existed and the linker had nothing to link. A budget gate cannot
detect that class of failure at all — it is an upper bound, and "no code" is
always under it. The size moving is a symptom; the check that means something is
that the object files exist and are referenced.

Two `text` measurements disagree (218,361 here vs. 290,045 total image) because
the size tool reports `.bin` size separately from ELF `.text`. Use the `.bin`
figure for the CI budget gate, which is what actually has to fit in the slot.

## Verification targets

- `pio run -e esp32s3 -t size` → prints the table above. **Works.**
- `pio run -e esp32s3 -t partition-table` → **does not exist** in pioarduino
  55.03.311. It fails with `*** Do not know how to make File target
  'partition-table'`. The brief's Step 8 names a target this platform version
  does not define. Verified equivalently instead (see Defect 2):
  `.pio/build/esp32s3/partitions.bin` is **3072 bytes** and decodes to exactly
  the CSV, ending at `0x400000`:

```
# ESP-IDF Partition Table
# Name, Type, SubType, Offset, Size, Flags
nvs,data,nvs,0x9000,48K,
otadata,data,ota,0x15000,8K,
phy_init,data,phy,0x17000,4K,
app0,app,ota_0,0x20000,1920K,
app1,app,ota_1,0x200000,1920K,
coredump,data,coredump,0x3f0000,64K,
```

## Defects found in the brief (all fixed, all verified)

### Defect 1 — `framework = espidf` could not build at all (BLOCKING)

`ModuleNotFoundError : No module named 'SCons.Tool.FortranCommon'` on every
run, from `SCons/Tool/linkCommon/__init__.py:132 smart_link` (reached via
`SCons/Subst.py` during link-action signature expansion).

Root cause: `~/.platformio/platforms/espressif32/platform.py` sets
`COMMON_IDF_PACKAGES = ["tool-cmake", "tool-ninja", "tool-scons",
"tool-esp-rom-elfs"]` and installs them **only** under
`if "espidf" in frameworks:` (line 845). For `tool-scons`, pioarduino's
`platform.json` pins `package-version 4.40801.0`, whose artifact
(`pioarduino/registry/.../scons-4.8.1.zip`) is a **2-file stub** containing only
`package.json` + `tools.json` — no `SCons/` tree at all. PlatformIO Core
separately requires `tool-scons ~4.41101.0`. The two owners fight over the same
`packages/tool-scons` directory: it is installed, then deleted and reinstalled
several times *during a single build*, and SCons dies on the lazy import when it
loses the race.

Evidence it is not caused by this project's files: the same failure reproduces
with the **stock `esp32-s3-devkitc-1` board** on the **other** pioarduino tag
(55.03.39), and in a **completely fresh core dir**
(`PLATFORMIO_CORE_DIR=/tmp/pio_cleancore`), and with `platform_packages =
platformio/tool-scons@~4.41101.0` set. `framework = arduino` on the same
platform builds fine — the defect is specific to the ESP-IDF branch, which is
exactly risk R-9 / N-8.

Resolution: PlatformIO's own pin won. Once the `packages/tool-scons` directory
settled at `4.41101.0` (SCons 4.11.1, which *does* contain
`SCons/Tool/FortranCommon.py`), the build compiles the full IDF tree. No change
to the platform pin was made — the framework choice stands.

#### Defect 1 recurrence — 2026-09-19, and the actual mechanism

Defect 1 came back with the *same* error text but a different cause, and the
earlier "it settles" conclusion was wrong: it does not settle, it converges on
the directory being **deleted**.

Measured by polling `packages/tool-scons` every 250 ms during a build. The
directory is created, removed, recreated with `scons.py` present, then removed
and **left removed**. The build then dies at the lazy `FortranCommon` import
because `scons.py` itself is gone.

The mechanism is a version skew between the two owners, and this is the part the
first write-up missed:

- pioarduino's `platform.json` pins `tool-scons` **`package-version 4.40801.0`**.
- PlatformIO Core's own `dependencies.py` pins `tool-scons` **`~4.41101.0`**.

`_handle_existing_tool` (`platform.py:595`) compares the installed
`package.json` version against the platform's `package-version`. Installed is
`4.41101.0` (Core won the install), required is `4.40801.0` (pioarduino), so the
comparison **always fails**, on every build, forever. It then runs
`safe_remove_directory(tool_path)` and calls `self.install_tool()` to put it
back.

That reinstall cannot succeed. `install_tool` picks a branch from
`_check_tool_status`:

- Case 1 (`has_idf_tools and has_tools_json`) — needs `tools.json` in
  `packages/tool-scons`, which the real SCons tree does not contain.
- Case 2 (`has_idf_tools and has_piopm and not has_tools_json`) — true *before*
  the delete, which is how it got here.
- Fallthrough — "already configured", returns `True`.

After `safe_remove_directory` the directory is empty, so Case 1 and Case 2 are
both false and it takes the **fallthrough: logs success and returns without
reinstalling anything**. The directory stays deleted, and the next build fails
at the import. Nothing re-creates it, because every subsequent run takes the
same path.

Fix applied (machine-local, and it is a workaround, not an upstream fix): edit
`~/.platformio/platforms/espressif32/platform.json` to set `tool-scons`
`package-version` to **`4.41101.0`**, matching Core's pin. The version check then
passes, `_handle_existing_tool` returns early, and the directory is left alone.
Verified: `pio run -e esp32s3` → `[SUCCESS]`, and three consecutive builds are
green with `tool-scons` intact at 7 entries each.

**This edit lives in the PlatformIO package cache, not in the repo, so it does
not survive a platform reinstall and is not reproduced by a fresh clone.** If
the `FortranCommon` error reappears, re-apply it before debugging anything else:

```
python3 - <<'EOF'
import json, os
p = os.path.expanduser("~/.platformio/platforms/espressif32/platform.json")
d = json.load(open(p))
d["packages"]["tool-scons"]["package-version"] = "4.41101.0"
json.dump(d, open(p, "w"), indent=2)
EOF
```

A durable fix would be to pin `platform_packages = platformio/tool-scons@~4.41101.0`
in `platformio.ini`, but that was **tested and does not work** — it was one of
the conditions in which the original Defect 1 reproduced. The `platform.json`
edit is what is verified.

#### Defect 5 — the host test env never compiled any `lib/` source (BLOCKING)

`build_src_filter = -<*>` excludes the whole project tree, which is right for a
host build, and the plan added exactly one `+` line to put `test_native/*.cpp`
(MockHAL.cpp) back. **No source under `lib/` was ever compiled on the host**, so
every suite that tests real library code — not just the mock — failed to link:

```
Undefined symbols for architecture arm64:
  "LadderClassify(LadderProfile const&, int, int)", referenced from: ...
```

This was latent until Task 3 added the first `lib/` module with a `.cpp`. The
LDF cannot rescue it: the finder scans `src_dir`, which `-<*>` has emptied, so
`lib/Analog` is never detected as a dependency.

Fix: a second include line.

```
build_src_filter =
    -<*>
    +<../test_native/*.cpp>
    +<../lib/*/*.cpp>
```

Verified load-bearing by deleting the new line, cleaning `.pio/build/native`,
and watching `test_analog` fail to link; restoring it gives 19/19 PASSED. Note
`lib/*/*.cpp` (not `lib/*.cpp`) — sources live one level down, in per-module
directories.

#### Defect 6 — a suite's `#include` did not match the plan (data loss)

`test_native/test_analog/LadderDecodeTest.cpp` was found on disk with
`#include "LadderDecode.h"` where the plan specifies `"Analog/LadderDecode.h"`,
and `lib/Analog/` was **absent from the filesystem entirely** — it had been
deleted between two builds. Neither file had ever been committed, so git held no
copy: a scan of all 462 blobs and 30 dangling commits found no trace.

Recovered from a Time Machine local snapshot
(`com.apple.TimeMachine.2026-09-18-233541.local`, mounted read-only with
`mount_apfs -s`). Both `LadderDecode.h` and `LadderDecode.cpp` were present
there, and after restoring them all three files diff **byte-identical** against
the plan's code blocks.

The lesson worth keeping: the recovery window was ~70 minutes wide, and the only
reason it existed is that the files sat uncommitted long enough to be caught by
an automatic snapshot. **An uncommitted file on this machine is one snapshot
generation from gone.** Commit verified work promptly.

### Defect 2 — `partitions.csv` is rejected by IDF (BLOCKING)

`Partition app1 invalid: Offset 0x208000 is not aligned to 0x10000`

`gen_esp32part.py` sets `ALIGNMENT[APP_TYPE] = 0x10000`, so an **app**
partition's offset must be 64 KB aligned. The spec's `app1` offset `0x208000`
is not. Spec §9.2's own "Arithmetic, checked exactly" note verifies only that
the table *ends* at `0x400000`; it never checks the 64 KB alignment rule, so the
table is self-consistent and still invalid.

Fix applied: `app0`/`app1` size `0x1E8000` → `0x1E0000` (1920 KB, was 1952 KB)
and `app1` offset `0x208000` → `0x200000`. `0x3E0000–0x3EFFFF` is left reserved
so `coredump` stays at its specified `0x3F0000`/64 KB, and the table still ends
at `0x400000`.

**This costs 32 KB per slot — the app budget is 1920 KB, not the 1952 KB the
spec states throughout.** That is a spec change, not just a build fix: spec
§9.2, the N-3 risk and the §10.5 CI budget gate all quote 1952 KB. 1920 KB is
still above IDF's own `partitions_two_ota_large.csv` (1700 KB), so the design
intent holds, but **the plan owner should update those spec figures.**

### Defect 3 — flash size silently stayed at 2 MB

`Warning! Flash memory size mismatch detected. Expected 4MB, found 2MB!`

`platformio.ini`'s `board_build.flash_size = 4MB` is **not** honoured on the
ESP-IDF path. The board→sdkconfig injection that reads it
(`generate_board_specific_config`) is called from `HandleArduinoIDFsettings`,
which is Arduino-gated, so IDF fell back to its own default
(`ESPTOOLPY_FLASHSIZE` defaults to `ESPTOOLPY_FLASHSIZE_2MB`).

`ESPTOOLPY_FLASHSIZE` is a Kconfig **choice**; the string form
`CONFIG_ESPTOOLPY_FLASHSIZE="4MB"` is silently ignored (tested — the generated
value stayed `2MB`). Fix applied: `CONFIG_ESPTOOLPY_FLASHSIZE_4MB=y` in
`sdkconfig.defaults`. Verified: generated `ESPTOOLPY_FLASHSIZE = 4MB`, warning
gone, and `main.c`'s 4 MB runtime assertion now agrees with the image it was
built into.

### Defect 4 — `-t partition-table` target does not exist

See "Verification targets" above. Step 8's command cannot run as written on
55.03.311; the partition table was verified by decoding `partitions.bin`.
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

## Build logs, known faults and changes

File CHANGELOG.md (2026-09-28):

# Changelog

Revision history for the SWC Steering Wheel Controls Adapter.

Format follows [Keep a Changelog](https://keepachangelog.com/en/1.1.0/).
This is a hardware project, so "version" is the board revision; the project is
not yet ordered and carries no assigned revision letter (`REV ${REVISION}` on
the F.Fab block is still an unresolved text variable).

The **firmware and Android app are versioned separately** from the board, and
their releases are published as GitHub Releases (see "Software releases" below) —
a release is what the device's OTA check (spec §9.5) and the app fetch from
`releases/latest/download/version_manifest.json`, so it is a protocol artifact,
not just a tag.

## Software releases

### [1.0.1] — 2026-09-28

**Fix: "check for updates" now works in production.** The WiFi OTA release fetch
(FR-35) had never succeeded against the real GitHub release host — it was only ever
proven against a Cloudflare tunnel. Three independent, host-dependent reasons, all
found and fixed (defect N-92):

- **The release repository was private.** GitHub serves release assets to
  anonymous clients only on public repos, so the device and the app both received
  HTTP 404 (neither sends a credential). The repository is now **public**.
- **The redirect target's CA was not pinned.** A GitHub release URL 302-redirects
  to `release-assets.githubusercontent.com`, signed by Let's Encrypt (ISRG Root
  X1) — a different CA than `github.com` (Sectigo E46). The firmware pinned only
  the latter, and `esp_http_client` reuses its certificate across the redirect, so
  the fetch died on the redirect hop. `ReleaseCa.h` now pins **both** roots.
- **The HTTP request buffer was too small.** The redirect URL carries a long
  signed query string, so the request first line is ~900 bytes — over IDF's
  512-byte default, which refuses it ("Out of buffer"). The check path set no
  buffer size; it now matches the install path (`buffer_size_tx = 1024`).

**Diagnostics**: `OtaWifiLastError()` now reports *why* a release check failed
(the transport error and HTTP status) instead of the single, uninformative "the
release manifest could not be read" — the ambiguity that hid all three causes.

**Guards** (CI-wired, mutation-tested): `check_release_ca.py` asserts the pin's
count, both subjects and both expiries; new `check_ota_buffer.py` requires every
OTA HTTP config to size its TX buffer.

**Verification**: 612/612 native tests; 71 tools tests; all 11 static gates; device
build 71.9 % of the app slot. **Proven on the DUT** with the production URL
compiled in (no override): `POST /api/ota/check` → *"an update is available: 1.0.0
(1410368 bytes)"*, the exact size of the published asset.

### [1.0.0] — 2026-09-28

The first release with the complete **no-app** feature set: a head unit can be
given single, double and long functions on every steering-wheel button with no
phone attached.

**Firmware** (version reported in `hello` = the release tag):

- **Headless gesture programming — the 2022 Pico flow, restored.** Hold `AUX1`,
  perform the gesture on a learned wheel button (tap = single, two taps = double,
  hold = long), and the adapter **holds that gesture's voltage on the KEY line**
  while the head unit's own "set key function" screen learns it; releasing `AUX1`
  releases the line. Previously the output was suppressed during the hold, so
  there was nothing on the line to program — the "it doesn't work" the user
  reported. (Spec §7.5; defect N-89.)
- **An unbound gesture now presents its own gesture's voltage**, not the button's
  single level for all three gestures. This is what makes three head-unit
  functions per button possible with no app: the head unit is gesture-blind, so
  it can only tell the gestures apart by a different voltage. The levels come from
  a predefined ascending table (`Output/GestureLevels`) mapped as a fraction of
  the output band, so they are correct on both 5 V and 3 V head units. (Spec §6.6
  rule 4; defect N-89.)
- **`key_click_enabled` setting** (default **off**): an optional per-press
  acknowledgement beep, enabling it in the app. Normal switch operation is silent
  by default. An explicit `BUZZ` action and `KEY_UNKNOWN` still play.

**Android app** (`com.oetsolutions.swc` 1.0.0): a **Key click** switch on the
Bindings screen for `key_click_enabled`, matching the firmware setting.

**Documentation**: a new end-user **[MANUAL.md](MANUAL.md)** (wiring, the on-device
learn, programming and binding, the app, firmware updates, feedback reference,
troubleshooting).

**Verification**: 612/612 native tests; the rig driver's 10/10 host tests; the
Android JVM suite; the device build at 71.7 % of the app slot; and every static
gate. The board itself was re-flashed with this image and reports `config_state:
ok` / `output_safe: true`. The "three distinct levels reach the head unit" half
is covered by the host suite only — reading a driven level on the bench needs the
per-channel loopback wire, which is not fitted here (defect N-90).

## [Unreleased] — 2026-09-11

Full redesign of the 2022 RP2040 reference board. Design complete and routed;
**not yet ordered**. See [DESIGN.md](DESIGN.md) for the architecture and
[MANUFACTURING.md](MANUFACTURING.md) for the order.

### Added

- **ESP32-S3-WROOM-1-N4** (`U3`) replacing the Pi Pico module, with native
  USB-CDC and USB-JTAG.
- **MCP4728 quad 12-bit I²C DAC** (`U4`) on +3V3 with VREF = VDD — the ESP32-S3
  has no DAC of its own, and 8 bits would have been too coarse.
- **Closed-loop integrator servo** output stage (`U6` quad op-amp): the DAC
  drives an inverting integrator whose summing node sets
  `V_KEY = (1 + R58/R61)·V_DAC − (R58/R61)·V_ADJ`. Gain is a resistor ratio
  (82 k / 100 k → 1.812), and `V_ADJ` shifts the offset, giving runtime range
  switching that the 2022 design did not have.
- **Auto-ranging** — the KEY line is sensed through a 1 MΩ / unity-gain buffer
  and an exact ÷2 divider (`R54`/`R50`), so firmware can learn the head unit's
  own idle voltage at startup.
- **Temperature compensation** — `RT1`, a 10 kΩ B3380 NTC on the exposed right
  edge.
- **Three auxiliary inputs** (`J5`, `R23`–`R25` 1 kΩ + 10 kΩ pull-ups,
  BAT54S-clamped) for extra buttons or programming functions.
- **`J1` 12 V input** making external power optional — the board runs from USB
  VBUS alone.
- **Per-source protection**: `F1`/`F2` PPTCs and `D2`/`D3` SS34 OR-ing diodes,
  so a fault on one source cannot back-feed the other.
- Test points `TP1`–`TP8`; buzzer `BZ1` on +5 V via `Q3`; status LEDs `D6`/`D12`.
- `tools/` direct-write scripts, `AGENTS.md`, `CLAUDE.md`, `DESIGN.md`,
  `MANUFACTURING.md`, this changelog.

### Changed

- **Input conditioning** for a 12 V-idle factory ladder: 10 kΩ series, BAT54S
  clamp to +3V3/GND, 100 nF filter, 10 kΩ pull-up — so a bare switch-to-ground
  button works as well as a ladder.
- **USB.** `J4` USB-C through `U8` (USBLC6-2SC6) and 22 Ω series resistors
  `R11`/`R12` to the module's native USB. Ordering is connector → clamp →
  series R → IC.
- **Power.** `U1` XL1509-5.0 buck (`L1` 47 µH, `D7` freewheel) and `U2`
  AMS1117-3.3; `D2`/`D3` diode-OR at +5 V.
- **C1/C2 bulk input caps re-sourced** from `C3151829` (ROQANG RVT1H101M0607) to
  **`C46550415`** (jieerrui JVJ50V100M6x8). Same 100 µF/50 V ±20 %,
  2000 hrs @105 °C, `SMD,D6.3xL7.7mm` part in the identical `CP_Elec_6.3x7.7`
  footprint, so **no layout change** — it adds a published 140 mA @120 Hz ripple
  rating the ROQANG never listed, and widens operation to −55…+105 °C. The
  motive was JLCPCB's **`PCBA Type`** field: the ROQANG part is `Standard Only`
  and forced the order onto Standard PCBA.
- **`U3` MCU module re-sourced** from `C2913197` (Espressif ESP32-S3-WROOM-1-N4)
  to **`C49164655`** (DOIT `ESPS3-32-N4`), also to clear a `Standard Only`
  flag — every Espressif ESP32-S3 WROOM-1/‑1U/MINI-1 variant is `Standard Only`.
  The DOIT module is a verified clone of the WROOM-1: 18 × 25.5 × 3 mm, all 41
  pins identical by number and function (IO19/IO20 = USB D−/D+, `RXD0`/`TXD0` =
  IO44/IO43, EPAD = GND), and the same land pattern, so it fits
  `RF_Module:ESP32-S3-WROOM-1` with **no PCB change**. Trade-offs: third-party
  single source (645 stock), DOIT's own FCC ID, and no PSRAM option that is
  Economic-eligible. With both flags cleared the order should qualify for
  Economic PCBA — see [MANUFACTURING.md §3](MANUFACTURING.md#3-pcba-type--the-economicstandard-decision).
- **Connectors onto the board edge**: all four screw terminals on the left edge,
  USB-C on the top-left edge. The 2022 design's separate per-channel terminals
  were consolidated into one input (`J2`) and one output (`J3`), each with a GND
  pin.

### Fixed

- **USB D+/D− corridor re-routed.** An earlier "provably un-routable" conclusion
  was wrong: it came from a BFS that treated every SMD pad as an obstacle on
  **both** layers, when an F.Cu pad never blocks B.Cu. With that corrected and
  placement treated as the free variable it is, the pair routes cleanly and is
  **via-free on F.Cu**. `/VBUS` moved out of the corridor and was widened to
  0.50 mm. Board DRC went 50 → 19 violations and unconnected 27 → 0; the 27 were
  collateral from the rip's bounding box, and all were restored.
- **Silkscreen pass.** All 108 reference designators re-placed against a
  DRC-accurate obstacle model, and 140 labels now sit at 0° or 90° with no
  text-over-text overlap. Four defects in the placement tooling were found and
  fixed — most notably a sign error in the rotation transform that had been
  mirroring every obstacle of a ±90° footprint, and the discovery that unprinted
  F.Fab `Value` fields and tented vias were being treated as hard obstacles when
  neither can ever be flagged.
- **`J4` (USB-C) orientation** corrected to `(at 19.65 48.206 270)` with its 3D
  model set to `rotate (0 0 180)` / `offset (0 −1.07 0)`, so the shell lands on
  the footprint's own F.Fab body instead of hanging off the board.
- **`RT1` re-placed** to the exposed right edge — the four board corners are
  unusable, each carrying an M5 mounting hole with a 5.55 mm-radius courtyard.
- **BOM regenerated from the schematic.** The archived CSV predated the
  output-stage rework and listed `R50`/`R51` as 13.7 k; they are **10 k**, which
  is what makes the sense divider an exact ÷2.
- **Documentation corrected against the netlist.** Several confident earlier
  notes were wrong: `U4` runs on **+3V3** (VREF = VDD, 0–3.3 V FS), so there is
  **no I²C level shifter**; the op-amp is an **integrator servo**, not an
  open-loop buffer; and there are **five** BAT54S positions
  (`D4`/`D5`/`D8`/`D9`/`D10`), not three.
- **Board renders added to the front page.** `SWC_Top.png` and `SWC_Bottom.png`
  (3616 × 1936) show the current design top and bottom; the README previously
  had no image of this board at all.

### Removed

- **Digital potentiometer** — the 2022 design's core weakness; not precise
  enough, and it could not auto-range. Replaced by the DAC + servo.
- **Pi Pico module** — replaced by the ESP32-S3 module.

## [2022] — baseline

The original RP2040 reference design, archived under `old/` (`swc_module_pcb.*`
plus a per-block sheet set: `power`, `mcu`, `usb`, `lora`, `sensors`,
`ssr_switches`, `ac_switching`, `light_control`, `door_motor_drive`). Reference
only — not input to the current design. Its failures are the reason this board
exists: digital pot, no auto-ranging, no temperature compensation, module build
rather than a custom PCB.

## Accepted limitations

Deliberate, not defects:

- **The ESP32 antenna overhangs the top board edge by 5.900 mm.** No antenna
  cutout is needed as a result — the keepout lies off-board except for a 0.25 mm
  sliver — but the overhang **must be supported by the enclosure**. A fully
  seated module would need roughly 108 mm of board. Accounting in
  [DESIGN.md §4.12](DESIGN.md#412-the-esp32-antenna).
- **`hole_to_hole` on the `/VBUS` vias**, 0.2408 mm apart — 0.0092 mm under the
  0.25 mm rule. Accepted because nudging one shifts the whole VBUS elbow and
  re-opens a clearance violation elsewhere, which is a worse trade than a 9 µm
  hole-spacing warning on a hand-assembled board.
- **`lib_footprint_mismatch` on `J4`, `U3` and `R60`** — deliberate local edits
  to stock footprints. These are currently undone by any footprint-library
  resync; making them durable is the first open item below.
- **`silk_edge_clearance` on `J4` and `U3`** and **`silk_over_copper` on `BZ1`'s
  "(+)"** — excluded by design, geometrically impossible to clear.

## Open

1. **Project-local footprint library for `J4`, `U3` and `R60`** — makes their
   local edits durable and clears the three mismatch warnings. Blocked: the
   kicad MCP server has no footprint-library tool and nothing writes a
   `.kicad_mod`, so it needs either hand-written files (forbidden) or a new
   script under the `tools/` exception. Detail in
   [DESIGN.md §7](DESIGN.md#7-open-items).
2. **4-layer vs 2-layer at order time** — see
   [MANUFACTURING.md §5](MANUFACTURING.md#5-ordering-decisions).

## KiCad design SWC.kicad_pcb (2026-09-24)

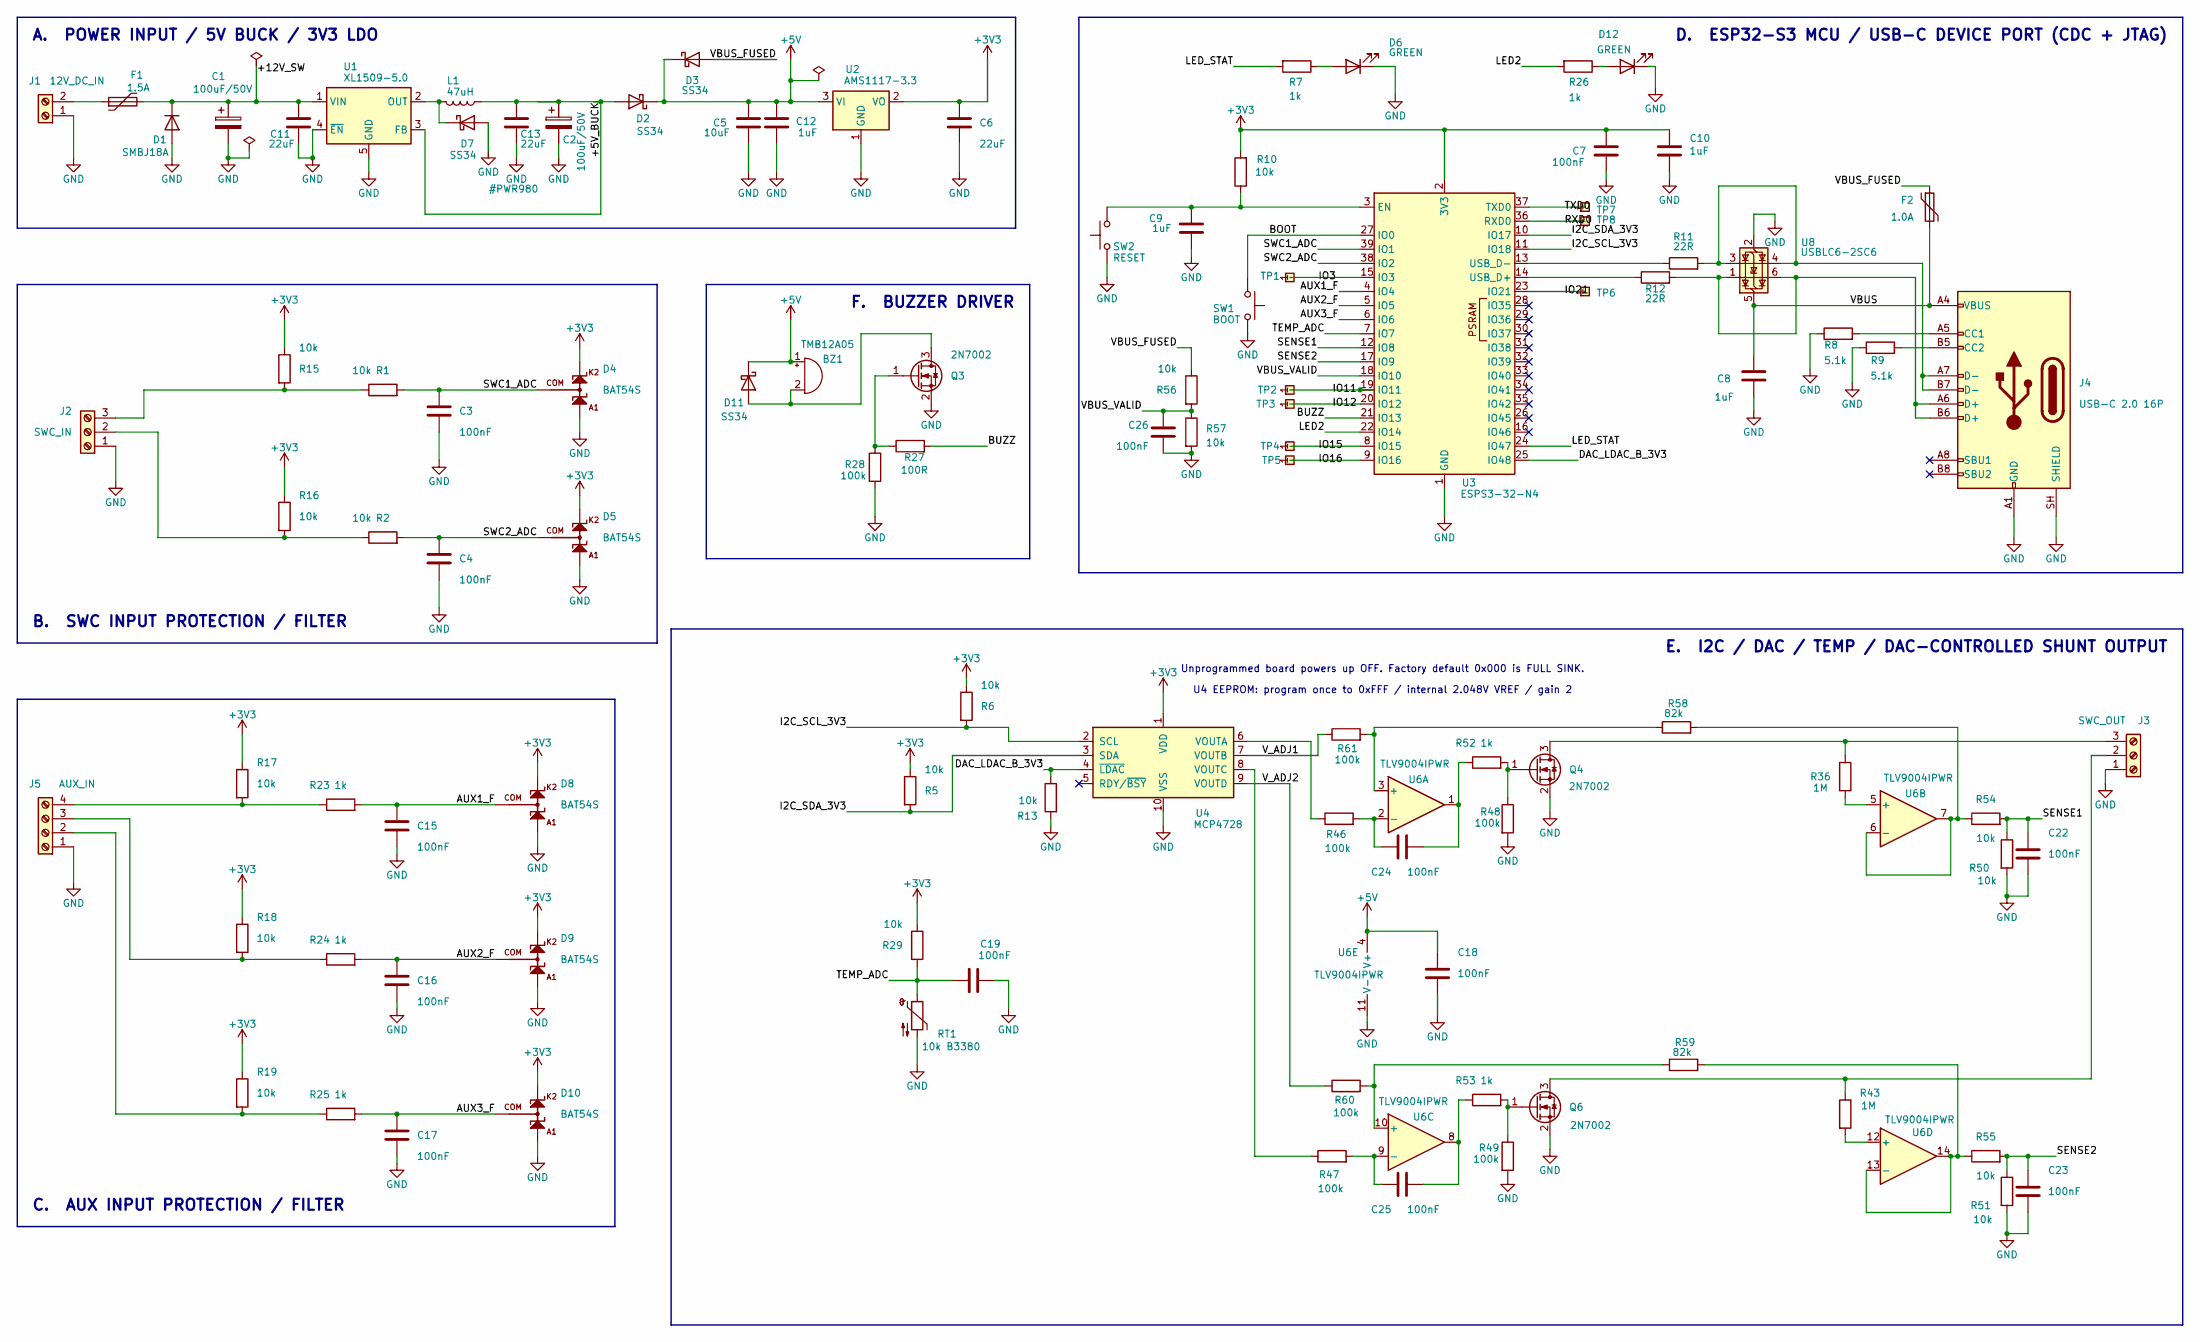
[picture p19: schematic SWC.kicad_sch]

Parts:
BZ1: TMB12A05; MagneticBuzzer_StarMicronics_HMB-06_HMB-12; MPN TMB12A05; LCSC C96093
C1, C2: 100uF/50V; CP_Elec_6.3x7.7; MPN JVJ50V100M6x8; LCSC C46550415
C3, C4, C7, C15, C16, C17, C18, C19, C22, C23, C24, C25, C26: 100nF; C_0805_2012Metric; MPN CC0805KRX7R9BB104; LCSC C49678
C5: 10uF; C_0805_2012Metric; MPN CL21A106KAYNNNE; LCSC C15850
C6, C11, C13: 22uF; C_0805_2012Metric; MPN CL21A226MAQNNNE; LCSC C45783
C8, C9, C10, C12: 1uF; C_0805_2012Metric; MPN CL21B105KBFNNNE; LCSC C28323
D1: SMBJ18A; D_SMB; MPN SMBJ18A; LCSC C19077573
D2, D3, D7, D11: SS34; D_SMA; MPN SS34; LCSC C8678
D4, D5, D8, D9, D10: BAT54S; SOT-23; MPN BAT54S; LCSC C7420333
D6, D12: GREEN; LED_0805_2012Metric; MPN KT-0805G; LCSC C2297
F1: 1.5A; Fuse_1812_4532Metric; MPN BSMD1812-150-33V; LCSC C883154
F2: 1.0A; Fuse_0805_2012Metric; MPN SMD0805-100-12; LCSC C46640991
J1: 12V_DC_IN; TerminalBlock_CUI_TB007-508-02_1x02_P5.08mm_Horizontal; MPN WJ500V-5.08-2P; LCSC C8465
J2: SWC_IN; TerminalBlock_CUI_TB007-508-03_1x03_P5.08mm_Horizontal; MPN WJ500V-5.08-03P; LCSC C72334
J3: SWC_OUT; TerminalBlock_CUI_TB007-508-03_1x03_P5.08mm_Horizontal; MPN WJ500V-5.08-03P; LCSC C72334
J4: USB-C 2.0 16P; USB_C_Receptacle_HRO_TYPE-C-31-M-12; MPN TYPE-C-31-M-12; LCSC C165948
J5: AUX_IN; TerminalBlock_CUI_TB007-508-04_1x04_P5.08mm_Horizontal; MPN WJ500V-5.08-04P; LCSC C42377749
L1: 47uH; L_Sunlord_MWSA0605S; MPN MWSA0605S-470MT; LCSC C408471
Q3, Q4, Q6: 2N7002; SOT-23; MPN 2N7002; LCSC C8545
R1, R2, R5, R6, R10, R13, R15, R16, R17, R18, R19, R29, R50, R51, R54, R55, R56, R57: 10k; R_0805_2012Metric; MPN 0805W8F1002T5E; LCSC C17414
R7, R23, R24, R25, R26, R52, R53: 1k; R_0805_2012Metric; MPN 0805W8F1001T5E; LCSC C17513
R8, R9: 5.1k; R_0805_2012Metric; MPN 0805W8F5101T5E; LCSC C27834
R11, R12: 22R; R_0805_2012Metric; MPN 0805W8F220JT5E; LCSC C17561
R27: 100R; R_0805_2012Metric; MPN 0805W8F1000T5E; LCSC C17408
R28, R46, R47, R48, R49, R60, R61: 100k; R_0805_2012Metric; MPN 0805W8F1003T5E; LCSC C149504
R36, R43: 1M; R_0805_2012Metric; MPN 0805W8F1004T5E; LCSC C17514
R58, R59: 82k; R_0805_2012Metric; MPN 0805W8F8202T5E; LCSC C17840
RT1: 10k B3380; R_0603_1608Metric; MPN SDNT1608X103F3380FTF; LCSC C316397
SW1: BOOT; SW_SPST_TS-1088-xR020; MPN TS-1088-AR02016; LCSC C720477
SW2: RESET; SW_SPST_TS-1088-xR020; MPN TS-1088-AR02016; LCSC C720477
TP1, TP2, TP3, TP4, TP5, TP6, TP7, TP8: TestPoint; TestPoint_THTPad_2.0x2.0mm_Drill1.0mm
U1: XL1509-5.0; SOIC-8_3.9x4.9mm_P1.27mm; MPN XL1509-5.0E1; LCSC C61063
U2: AMS1117-3.3; SOT-223-3_TabPin2; MPN AMS1117-3.3; LCSC C6186
U3: ESPS3-32-N4; ESP32-S3-WROOM-1; MPN ESPS3-32-N4; LCSC C49164655
U4: MCP4728; MSOP-10_3x3mm_P0.5mm; MPN MCP4728T-E/UN; LCSC C478093
U6: TLV9004IPWR; TSSOP-14_4.4x5mm_P0.65mm; MPN TLV9004IPWR; LCSC C2058050
U8: USBLC6-2SC6; SOT-23-6; MPN USBLC6-2SC6; LCSC C7519

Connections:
+3V3: C6.1, C7.1, C10.1, D4.2 (K2), D5.2 (K2), D8.2 (K2), D9.2 (K2), D10.2 (K2), R5.1, R6.1, R10.2, R15.1, R16.1, R17.1, R18.1, R19.1, R29.1, U2.2 (VO), U3.2 (3V3), U4.1 (VDD)
/+5V_BUCK: C2.1, C13.1, D2.2 (A), L1.1, U1.3 (FB)
/AUX1_F: C15.1, D8.3 (COM), R23.2, U3.4 (IO4)
/AUX2_F: C16.1, D9.3 (COM), R24.2, U3.5 (IO5)
/AUX3_F: C17.1, D10.3 (COM), R25.2, U3.6 (IO6)
/BOOT: SW1.1, U3.27 (IO0)
/BUZZ: R27.2, U3.21 (IO13)
/DAC_LDAC_B_3V3: R13.1, U3.25 (IO48), U4.4 (~LDAC)
/I2C_SCL_3V3: R6.2, U3.11 (IO18), U4.2 (SCL)
/I2C_SDA_3V3: R5.2, U3.10 (IO17), U4.3 (SDA)
/IO3: TP1.1 (~_1), U3.15 (IO3)
/IO11: TP2.1 (~_1), U3.19 (IO11)
/IO12: TP3.1 (~_1), U3.20 (IO12)
/IO15: TP4.1 (~_1), U3.8 (IO15)
/IO16: TP5.1 (~_1), U3.9 (IO16)
/IO21: TP6.1 (~_1), U3.23 (IO21)
/LED2: R26.2, U3.22 (IO14)
/LED_STAT: R7.2, U3.24 (IO47)
/RXD0: TP8.1 (~_1), U3.36 (RXD0)
/SENSE1: C22.1, R50.1, R54.2, U3.12 (IO8)
/SENSE2: C23.1, R51.1, R55.2, U3.17 (IO9)
/SWC1_ADC: C3.1, D4.3 (COM), R1.2, U3.39 (IO1)
/SWC2_ADC: C4.1, D5.3 (COM), R2.2, U3.38 (IO2)
/TEMP_ADC: C19.1, R29.2, RT1.1, U3.7 (IO7)
/TXD0: TP7.1 (~_1), U3.37 (TXD0)
/VBUS: C8.1, F2.2, J4.A4 (VBUS), J4.A9 (VBUS), J4.B4 (VBUS), J4.B9 (VBUS), U8.5 (VBUS)
/VBUS_FUSED: D3.2 (A), F2.1, R56.1
/VBUS_VALID: C26.1, R56.2, R57.1, U3.18 (IO10)
/V_ADJ1: R61.1, U4.7 (VOUTB)
/V_ADJ2: R60.1, U4.9 (VOUTD)
unnamed: BZ1.2 (-), D11.2 (A), Q3.3 (D)
unnamed: C24.2, R52.1, U6.1
unnamed: C25.2, R53.1, U6.8
unnamed: D6.2 (A), R7.1
unnamed: D7.1 (K), L1.2, U1.2 (OUT)
unnamed: D12.2 (A), R26.1
unnamed: F1.1, J1.2
unnamed: J2.2, R2.1, R16.2
unnamed: J2.3, R1.1, R15.2
unnamed: J3.2, Q6.3 (D), R43.1
unnamed: J3.3, Q4.3 (D), R36.1
unnamed: J4.A5 (CC1), R8.2
unnamed: J4.B5 (CC2), R9.2
unnamed: J4.A6 (D+), J4.B6 (D+), R12.2, U8.1 (I/O1), U8.6 (I/O1)
unnamed: J4.A7 (D-), J4.B7 (D-), R11.2, U8.3 (I/O2), U8.4 (I/O2)
unnamed: J5.2, R19.2, R25.1
unnamed: J5.3, R18.2, R24.1
unnamed: J5.4, R17.2, R23.1
unnamed: Q3.1 (G), R27.1, R28.1
unnamed: Q4.1 (G), R48.1, R52.2
unnamed: Q6.1 (G), R49.1, R53.2
unnamed: C9.2, R10.1, SW2.2, U3.3 (EN)
unnamed: R12.1, U3.14 (USB_D+)
unnamed: R11.1, U3.13 (USB_D-)
unnamed: R46.1, U4.6 (VOUTA)
unnamed: R47.1, U4.8 (VOUTC)
unnamed: R58.1, R61.2, U6.3 (+)
unnamed: C24.1, R46.2, U6.2 (-)
unnamed: R36.2, U6.5 (+)
unnamed: R54.1, R58.2, U6.6 (-), U6.7
unnamed: R59.1, R60.2, U6.10 (+)
unnamed: C25.1, R47.2, U6.9 (-)
unnamed: R43.2, U6.12 (+)
unnamed: R55.1, R59.2, U6.13 (-), U6.14

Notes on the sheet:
A. POWER INPUT / 5V BUCK / 3V3 LDO
F. BUZZER DRIVER
C. AUX INPUT PROTECTION / FILTER
B. SWC INPUT PROTECTION / FILTER
U4 EEPROM: program once to 0xFFF / internal 2.048V VREF / gain 2
E. I2C / DAC / TEMP / DAC-CONTROLLED SHUNT OUTPUT
D. ESP32-S3 MCU / USB-C DEVICE PORT (CDC + JTAG)
Unprogrammed board powers up OFF. Factory default 0x000 is FULL SINK.

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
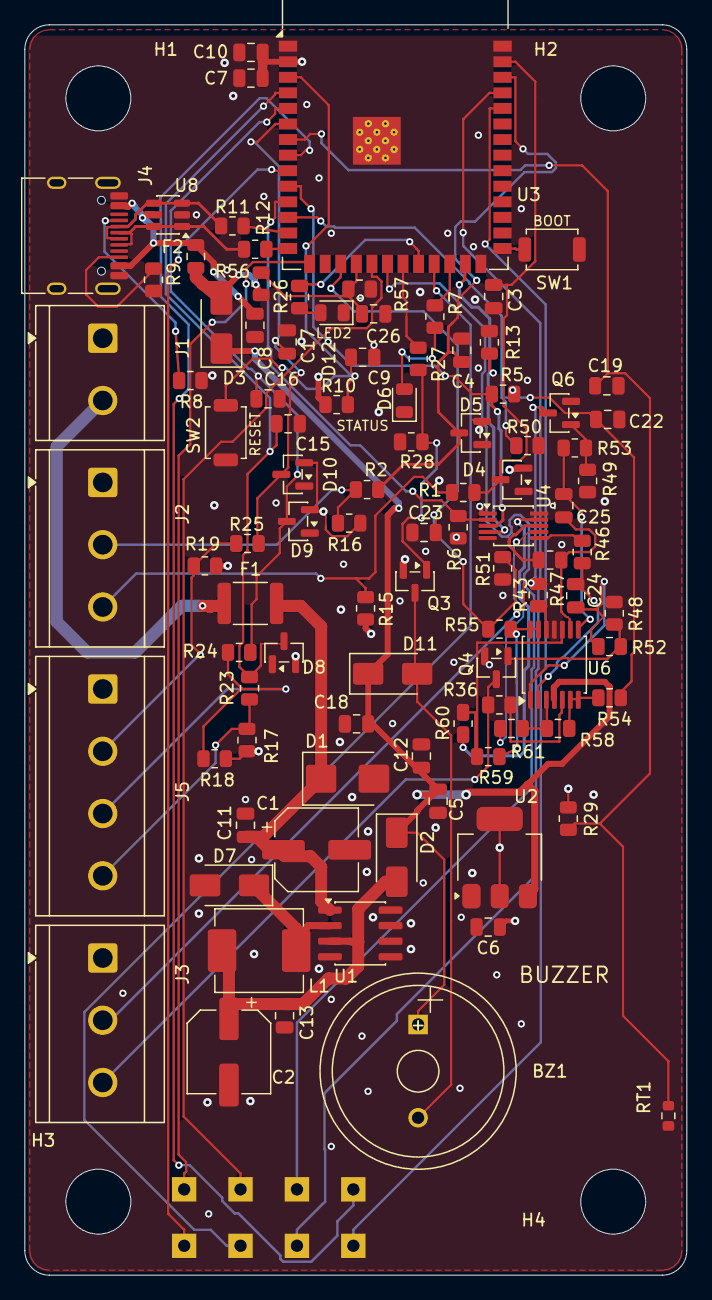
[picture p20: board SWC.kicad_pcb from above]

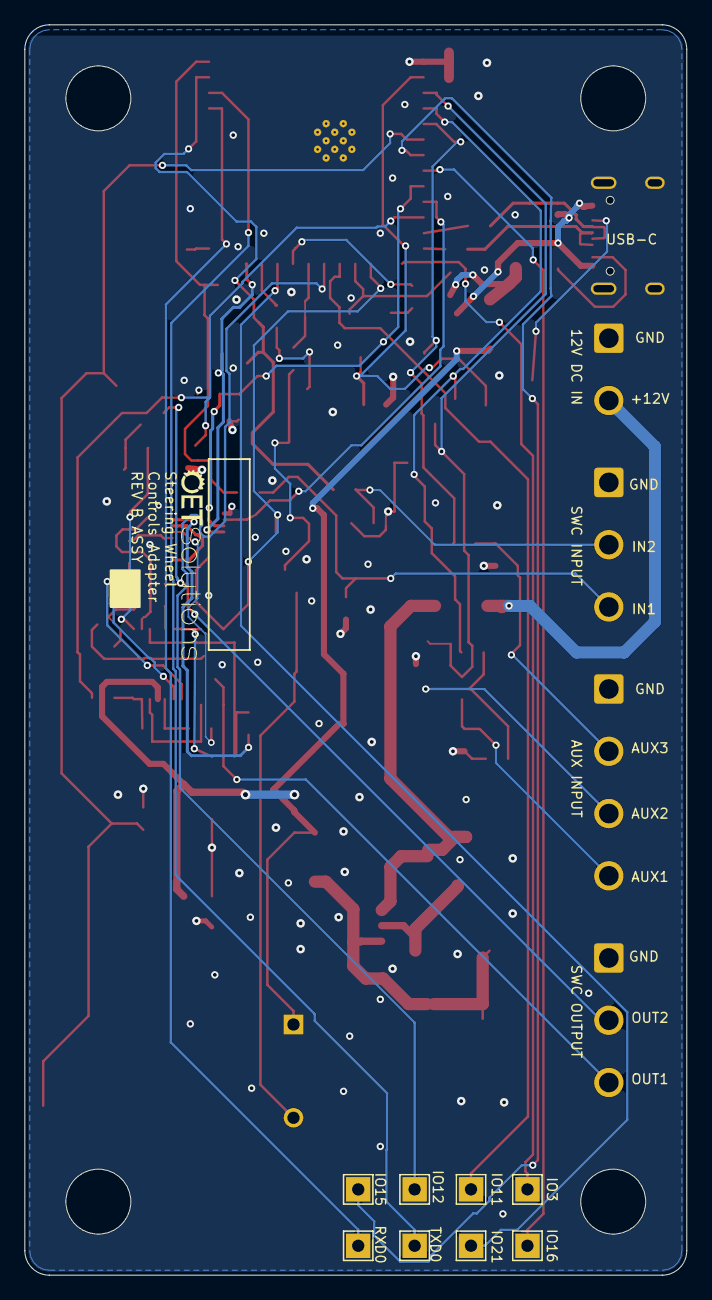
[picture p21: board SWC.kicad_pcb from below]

Board: 4 copper layers, 54.0 x 102.0 mm, 110 parts (9 on the bottom side), 67 nets.

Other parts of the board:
G1: LOGO
H1, H2, H3, H4: MountingHole_5.3mm_M5

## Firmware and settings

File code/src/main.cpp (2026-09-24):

#include <stdio.h>

#include "esp_attr.h"
#include "esp_chip_info.h"
#include "esp_flash.h"
#include "esp_log.h"
#include "esp_ota_ops.h"
#include "esp_system.h"
#include "freertos/FreeRTOS.h"
#include "freertos/task.h"

#include "HAL/EspHal.h"
#include "Link/UsbLink.h"
#include "Maintenance/MaintenanceRadio.h"
#include "System/SystemOrchestrator.h"

static const char *TAG = "swc-boot";

// The poll cadence. 10 ms is what the gesture tests assume: LONG must fire
// within one tick of its 750 ms threshold (spec 11's FR-10 test), and the
// double-press boundary is asserted at 499/500 ms, so a coarser poll would make
// those thresholds unreachable.
#define SWC_POLL_MS 10

// Board identity is asserted BEFORE anything else runs, because every budget and
// every pin in this firmware assumes it. A wrong board fails loudly here instead
// of as a mysterious analog fault later.
static bool VerifyBoard(void)
{
    esp_chip_info_t chip;
    esp_chip_info(&chip);

    uint32_t flash_size = 0;
    ESP_ERROR_CHECK(esp_flash_get_size(NULL, &flash_size));

    ESP_LOGI(TAG, "chip=%s cores=%d rev=v%d.%d", CONFIG_IDF_TARGET, chip.cores,
             chip.revision / 100, chip.revision % 100);
    ESP_LOGI(TAG, "flash=%" PRIu32 " bytes idf=%s", flash_size, esp_get_idf_version());

    if (flash_size != 4 * 1024 * 1024) {
        ESP_LOGE(TAG, "flash is %" PRIu32 " bytes, build assumes %d", flash_size,
                 4 * 1024 * 1024);
        return false;
    }
    if (chip.cores != 2) {
        ESP_LOGE(TAG, "expected 2 cores for ESP32-S3, got %d", chip.cores);
        return false;
    }
    return true;
}

// IDF's startup (freertos/app_startup.c) is C and calls `app_main` by that exact
// symbol, so it must have C linkage. Without this guard the C++ definition
// mangles to `_Z8app_mainv` and the link fails with
// "undefined reference to `app_main`".
extern "C" void app_main(void)
{
#ifdef SWC_BENCH_PANIC_IMAGE
    /*
     * A deliberately BROKEN image, for spec §10.4's level-4 rollback test: "flash
     * a deliberately-faulting image (compiles, panics at startup), assert the
     * bootloader rolls back and the device comes up on the old image. **This must
     * be tested with a genuinely broken image**, not a mocked failure, or it
     * proves nothing."
     *
     * The panic is FIRST, before any HAL or orchestrator work, so the image can
     * never reach `esp_ota_mark_app_valid_cancel_rollback` -- which is the whole
     * point: an image that panics after confirming itself would test nothing. It
     * is guarded by a compile-time define that no shipping env sets, so the
     * product image cannot contain this code path; `tools/bench_rollback.py`
     * builds it with `-D SWC_BENCH_PANIC_IMAGE`.
     *
     * A NULL dereference rather than `abort()`: `abort()` is a straight
     * exception/panic that CONFIG_ESP_SYSTEM_PANIC_PRINT_REBOOT also reboots, but
     * a real crash is the more faithful "faulting image", and it also proves the
     * panic HANDLER (not just an explicit call) leads to the rollback path.
     */
    volatile int *broken = (volatile int *)0;
    *broken = 1;
#endif
    if (!VerifyBoard()) {
        // A board that does not match the build must not drive the KEY line at
        // all. Halt rather than loop: a wrong board is a bench condition.
        abort();
    }

    IHAL *hal = EspHalInit();
    if (hal == NULL) {
        // The DAC or ADC did not come up, so the output cannot be reached or its
        // state cannot be read. Do NOT proceed to serve presses (spec 6.8: never
        // drive a guessed code). Reboot after a delay so a transient bus fault
        // recovers, which is what the maintainer will expect at the bench.
        ESP_LOGE(TAG, "HAL init failed; not serving output. Rebooting in 5s.");
        vTaskDelay(pdMS_TO_TICKS(5000));
        esp_restart();
    }

    if (EspHalCalibrationIsDegraded()) {
        // Reported, not silent (spec 3.2). This console log names the cause at
        // init; the orchestrator ALSO plays BOOT_DEGRADED for this class of
        // condition, and the flag below is how it learns -- the buzzer is the
        // signal a user at the bench hears with no host attached. It is passed
        // rather than read inside the orchestrator because the orchestrator's
        // translation unit is host-compiled and cannot name EspHal.
        ESP_LOGW(TAG, "ADC calibration degraded: linear approximation in use");
    }

    // Create establishes the safe idle output before returning (FR-13), which is
    // why the link is started only after this call and never before it.
    SystemOrchestrator *sys = SystemOrchestratorCreate(hal, EspHalCalibrationIsDegraded());
    if (sys == NULL) {
        ESP_LOGE(TAG, "orchestrator alloc failed; cannot reach safe idle. Rebooting.");
        vTaskDelay(pdMS_TO_TICKS(5000));
        esp_restart();
    }
    if (!SystemOrchestratorOutputVerified(sys)) {
        ESP_LOGE(TAG, "output NOT verified -- safe idle unestablished or a DAC write failed");
        // Deliberately NOT marked valid: see the mark-valid call below.
    }

    // FR-37: mark valid only once the device has PROVEN it can do its job --
    // the safe idle is established AND the output is actually reachable. Marking
    // this at the top of app_main would confirm an image that boots but cannot
    // drive the DAC, stranding the user with a bricked-but-"valid" device and no
    // rollback.
    //
    // **The condition must be able to be FALSE, and that is the whole point.**
    // It used to read `SystemOrchestratorSafeIdle()`, which returns
    // `safe_idle_established_` -- a flag assigned `true` once, at the end of an
    // `EstablishSafeIdle()` that returns void and cannot fail. The gate was a
    // compile-time constant `true` on the device path, so spec §9.8's "an image
    // that boots but cannot drive the DAC is not healthy" was exactly the case it
    // could not detect: a dead I2C bus still cancelled the pending rollback.
    // `SystemOrchestratorOutputVerified` folds in the HAL's latched
    // `dac_faulted`, which a failed `i2c_master_transmit` sets and nothing
    // clears -- that is the signal the gate needed to be able to say NO.
    //
    // `esp_ota_mark_app_valid_cancel_rollback` is a no-op when the running image
    // was not started from a pending-verify state (the normal case after a
    // successful boot), so calling it unconditionally on the good path is correct.
    if (SystemOrchestratorOutputVerified(sys)) {
        const esp_err_t mark = esp_ota_mark_app_valid_cancel_rollback();
        if (mark != ESP_OK) {
            // Not fatal: the device works, it just will not be treated as
            // confirmed if this boot came from an OTA. Say so rather than hide it.
            ESP_LOGW(TAG, "could not mark the image valid: %s", esp_err_to_name(mark));
        } else {
            ESP_LOGI(TAG, "image confirmed valid; rollback cancelled");
        }
    }

#ifdef SWC_BENCH_WDT_RESET
    /*
     * FR-40's WATCHDOG reset source, forced on the bench. The shipped build never
     * sets this define (like the other `SWC_BENCH_*` switches).
     *
     * Spec §10.4 wants the WDT reset proven, but this build cannot get one:
     * `CONFIG_ESP_TASK_WDT_PANIC` is UNSET, so a TASK-watchdog timeout only prints
     * a backtrace and never resets, and the board's 12 V supply cannot be cut from
     * software for a brownout. The **interrupt** watchdog, however, DOES panic and
     * reboot by default (`CONFIG_ESP_SYSTEM_PANIC_PRINT_REBOOT`), and it is easy to
     * trigger: its timeout only fires from the FreeRTOS tick, so a task that
     * disables interrupts and spins never feeds it and the WDT reboots the chip.
     *
     * The hook is SELF-LIMITING, keyed on the reset reason: on any boot that is NOT
     * already a watchdog reset it stalls (forcing the WDT), and on a watchdog-reset
     * boot it falls through to normal operation. So one flash produces exactly the
     * sequence the requirement describes -- a boot that watchdog-resets, then a
     * boot that comes up safely -- and a re-run repeats it without a reflash or a
     * power cycle. `tools/bench_wdt_reset.py` observes the recovery over USB.
     */
    {
        const esp_reset_reason_t why = esp_reset_reason();
        if (why == ESP_RST_INT_WDT || why == ESP_RST_TASK_WDT || why == ESP_RST_WDT) {
            ESP_LOGW(TAG, "SWC_BENCH_WDT_RESET: recovered from a watchdog reset "
                          "(reason=%d); safe idle established before this point",
                     static_cast<int>(why));
        } else {
            ESP_LOGW(TAG, "SWC_BENCH_WDT_RESET: forcing a watchdog reset now "
                          "(reset reason was %d)", static_cast<int>(why));
            portDISABLE_INTERRUPTS();
            for (;;) {
                // Spin with interrupts off: the tick never runs, so the interrupt
                // watchdog is never fed and reboots the device.
            }
        }
    }
#endif

    // The USB link belongs here and not earlier: everything above has already
    // made the output safe, so the device serves presses with no app, no host and
    // no radio attached. That is what makes FR-42 structural rather than a
    // promise -- there is no ordering in which the link is required to boot.
    UsbLinkStart(hal, sys);

    /*
     * FR-32/FR-34: the maintenance radio is driven by the WINDOW's transitions,
     * here in the poll loop rather than inside `MaintenanceMode`.
     *
     * `MaintenanceMode` is pure state and is host-tested; the moment it named
     * NimBLE it would lose those tests. Spec 8.2 says the radio work "is driven by
     * the caller in response to `Active()` transitions", and this loop is that
     * caller. `last_maintenance` is the applied state, so the bring-up and the
     * teardown each run exactly once per transition rather than on every tick.
     *
     * **A start that FAILED is latched, not retried every tick.** A failed
     * bring-up means the radio could not come up (no heap, no MAC, a driver
     * error); retrying at 100 Hz would fill the log and burn heap while telling
     * the user nothing new. The failure count is published to the app instead, so
     * a user sees "the window is open and the radio is not up" rather than a mode
     * that silently does nothing.
     */
    bool last_maintenance = false;
    uint32_t last_requests = 0;
    uint32_t published_failures = 0;
    MaintenanceInfo last_info{};
    bool have_published = false;

    for (;;) {
        SystemOrchestratorTick(sys, hal->now_ms(hal->ctx));

        const bool maintenance_now = SystemOrchestratorIsMaintenanceActive(sys);
        if (maintenance_now != last_maintenance) {
            last_maintenance = maintenance_now;
            if (maintenance_now) {
                MaintenanceInfo info{};
                if (MaintenanceRadioStart(&info)) {
                    ESP_LOGI(TAG, "maintenance window open; radio up, page at %s", info.page_url);
                } else {
                    // Reported, not hidden: the window is still open (the
                    // orchestrator's state is its own) and the app is told the
                    // radio did not come up.
                    ESP_LOGE(TAG, "maintenance window open but the radio failed to start");
                }
            } else {
                // FR-32: the stacks are freed on the way out, so nothing radio-
                // shaped is resident while the device serves the wheel.
                MaintenanceRadioStop();
                ESP_LOGI(TAG, "maintenance window closed; radio torn down");
            }
        }

        // Keep the page's `config_state` current with the config the device is
        // RUNNING, so a commit during the window is reflected rather than frozen
        // at the boot value.
        if (maintenance_now) {
            MaintenanceRadioSetConfigState(SystemOrchestratorConfigStateWord(sys));
        }

        /*
         * FR-38's activity clock. A request served by the maintenance HTTP server
         * IS activity -- a user reading the status page or typing a WiFi password
         * -- so the window is bumped whenever the request count has MOVED since the
         * last tick. Without this the window would be a fixed deadline from entry
         * and would reap a user mid-provision, which is the gap N-35 recorded while
         * there was no request source to bump it from.
         *
         * A count compared against the last value, not a flag: the server's task
         * runs concurrently with this loop, so several requests can land between
         * two ticks and a flag would report only the first.
         */
        const uint32_t requests = MaintenanceRadioRequestCount();
        if (maintenance_now && requests != last_requests) {
            SystemOrchestratorNoteMaintenanceActivity(sys, hal->now_ms(hal->ctx));
        }
        last_requests = requests;

        // Publish the window's facts to the app (spec 8.3 option 1). Every tick,
        // so a connection that arrives mid-window is handled by the router's own
        // change detection; the values are only re-sent when something moved.
        MaintenanceInfo info{};
        info.active = maintenance_now;
        if (maintenance_now) MaintenanceRadioDescribe(&info);
        const uint32_t failures = MaintenanceRadioFailures();
        if (!have_published || info.active != last_info.active ||
            strcmp(info.pop, last_info.pop) != 0 || strcmp(info.token, last_info.token) != 0 ||
            failures != published_failures) {
            UsbLinkPublishMaintenance(info, failures);
            last_info = info;
            published_failures = failures;
            have_published = true;
        }

        // Drains one deferred router frame and whatever the TX buffer still
        // holds. A large config reply is chunked, so this must be called often
        // enough that a reply finishes in a reasonable time -- 10 ms per chunk
        // puts a maximum config out in well under a second.
        UsbLinkService();
        vTaskDelay(pdMS_TO_TICKS(SWC_POLL_MS));
    }
}

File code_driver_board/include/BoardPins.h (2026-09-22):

#pragma once

// Every GPIO the board connects, and every analog constant the tests need.
//
// PROVENANCE: each pin below was read out of `production/netlist.ipc`
// (IPC-D-356, the netlist KiCad generated from the live PCB) as the `U3` pad -> net
// assignment, and cross-checked against the firmware spec's section 2.2 pin map and
// `code/lib/HAL/PinMap.h`. Where any of those three ever disagree, the netlist wins.
//
// Do NOT renumber these from memory or from another ESP32-S3 board's definition.
// The S3's GPIO-to-ADC1-channel mapping is NOT the identity -- IO7 is ADC1_CH6 and
// IO1 is ADC1_CH0 -- so arithmetic here would silently misread one pin.

#include <stdint.h>

// ---------------------------------------------------------------------------
// Analog inputs (all ADC1 -- spec 2.2; ADC2 is unusable while WiFi is up, and
// WiFi is on for most of this tool's life)
// ---------------------------------------------------------------------------
#define PIN_SWC1_ADC      1    // /SWC1_ADC   ADC1_CH0, ladder 1, R1 10k series
#define PIN_SWC2_ADC      2    // /SWC2_ADC   ADC1_CH1, ladder 2, R2 10k series
#define PIN_TEMP_ADC      7    // /TEMP_ADC   ADC1_CH6, NTC RT1 divider
#define PIN_SENSE1        8    // /SENSE1     ADC1_CH7, KEY1 voltage / 2
#define PIN_SENSE2        9    // /SENSE2     ADC1_CH8, KEY2 voltage / 2
#define PIN_AUX1          4    // /AUX1_F     ADC1_CH3, 1k series, R17 10k pull-up
#define PIN_AUX2          5    // /AUX2_F     ADC1_CH4, 1k series, R18 10k pull-up
#define PIN_AUX3          6    // /AUX3_F     ADC1_CH5, 1k series, R19 10k pull-up

// ---------------------------------------------------------------------------
// Digital
// ---------------------------------------------------------------------------
#define PIN_VBUS_VALID   10    // D-in,  VBUS present via R56/R57 divider
#define PIN_BUZZ         13    // D-out, buzzer Q3 gate via R27 100R
#define PIN_LED2         14    // D-out, D12 via R26 1k
#define PIN_LED_STAT     47    // D-out, D6 via R7 1k
#define PIN_I2C_SDA      17    // I2C to U4 MCP4728
#define PIN_I2C_SCL      18    // I2C to U4 MCP4728
#define PIN_DAC_LDAC_B   48    // D-out, MCP4728 ~LDAC, R13 10k pulldown
#define PIN_BOOT          0    // STRAPPING. Recovery only -- never hold low at power-on.

// Broken out to test points only -- no header, no user-facing function (spec 2.2).
// They are here so the continuity test can exercise them and so the spare-pin test
// has one definition of "spare" rather than a list written at the call site.
#define PIN_SPARE_IO3     3    // TP1
#define PIN_SPARE_IO11   11    // TP2
#define PIN_SPARE_IO12   12    // TP3
#define PIN_SPARE_IO15   15    // TP4
#define PIN_SPARE_IO16   16    // TP5
#define PIN_SPARE_IO21   21    // TP6
#define PIN_SPARE_TXD0   43    // TP7, ROM UART0 TX
#define PIN_SPARE_RXD0   44    // TP8, ROM UART0 RX

// ---------------------------------------------------------------------------
// The AUX stimulus pins -- TEST RIG, not board hardware.
// ---------------------------------------------------------------------------
// Test 31 exercises AUX1-AUX3 by pulling each one to GND, and it used to do that by
// asking the operator to fit a jumper for every input, twice. That was slow, fiddly,
// and produced six prompts per run. With a wire from each AUX input to one of these
// spare test points, the board drives its own stimulus and the test runs unattended.
//
// The wiring AS FITTED ON THE BENCH (measured, not assumed):
//
//     J5.4 (AUX1)  <->  IO43 (TP7)
//     J5.3 (AUX2)  <->  IO21 (TP6)
//     J5.2 (AUX3)  <->  IO16 (TP5)
//
// THE ORDER DOES NOT MATTER. Test 31 discovers which spare pin reaches which AUX
// input before it measures anything, so any input may be wired to any test point --
// the constants below are the SET of points, not a pairing. An earlier version
// hard-coded the pairing and reported "no response" for two perfectly healthy lines
// when the wires went the other way.
//
// DRIVING LOW simulates the button/short (the input is pulled to GND through the
// wire). FLOATING (INPUT, no pull) simulates it being open, which is the released
// state -- the board's own 10k pull-up then sets the level, exactly as it does with
// nothing attached.
//
// IO43 is TP7, traditionally "UART0 TX". This build sets ARDUINO_USB_MODE=1, so the
// console is the USB peripheral and UART0 is free -- verified in platformio.ini.
// Driving it is safe HERE and would not be on a build using the UART console.
#define PIN_AUX_STIM1    16    // TP5, wired to J5.4 (AUX1)
#define PIN_AUX_STIM2    21    // TP6, wired to J5.3 (AUX2)
#define PIN_AUX_STIM3    43    // TP7, wired to J5.2 (AUX3)

// How AUX_STIMx relates to the AUX channels, in one place.
#define AUX_STIM_FOR(idx) ((idx) == 0 ? PIN_AUX_STIM1 : \
                           (idx) == 1 ? PIN_AUX_STIM2 : PIN_AUX_STIM3)
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

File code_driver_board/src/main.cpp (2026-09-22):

#include <Arduino.h>

#include "Adc.h"
#include "BoardPins.h"
#include "Driver.h"
#include "KeyLine.h"
#include "Log.h"

// The swc_logic library is pulled in from src/ (see the same include in
// Driver.cpp): PlatformIO's dependency finder follows src/ includes, not ones
// reached only through include/ headers.
#include "DriverHarness.h"
#include "swc_logic/Output.h"

// The rig driver board: it PRESENTS ladder voltages and a programming-switch
// state to the device under test, so the DUT firmware can be exercised end to end
// with no vehicle and no steering-wheel pod.
//
// This is a bench instrument, not the product. Read README.md for the wiring and
// the command list.
//
// Everything is single-threaded: a synthetic gesture is a real-time sequence of
// DAC writes and waits, and it must not be interleaved with anything else -- the
// DUT judges the timing, so a stutter in the driver is a wrong gesture.

static void PrintMenu()
{
    Log::Printf("");
    Log::Rule('=');
    Log::Printf("  RIG DRIVER -- commands");
    Log::Rule('=');
    Log::Printf("  %-4s %s", "cmd", "action");
    Log::Printf("  %-4s %s", "1", "present a SINGLE press on the selected channel");
    Log::Printf("  %-4s %s", "2", "present a DOUBLE press");
    Log::Printf("  %-4s %s", "3", "present a LONG press");
    Log::Printf("  %-4s %s", "p", "hold the key down (press and stay down)");
    Log::Printf("  %-4s %s", "r", "release the key line");
    Log::Printf("  %-4s %s", "l", "LEARN: close AUX1 (programming switch) + hold the key");
    Log::Printf("  %-4s %s", "L", "hold AUX1 ~3 s alone (open the maintenance window)");
    Log::Printf("  %-4s %s", "a", "toggle the AUX1 programming switch by hand");
    Log::Printf("  %-4s %s", "c", "toggle the selected DUT channel (1 <-> 2)");
    Log::Printf("  %-4s %s", "m", "cycle the gain mode (amplified / tracking)");
    Log::Printf("  %-4s %s", "M", "auto-select the mode from the released level");
    Log::Printf("  %-4s %s", "+/-", "nudge the commanded key level by 50 mV");
    Log::Printf("  %-4s %s", "d", "diagnostic: what the KEY line rests at, and reachability");
    Log::Printf("  %-4s %s", "w", "watch the DUT KEY output (loopback) for ~2 s");
    Log::Printf("  %-4s %s", "s", "status");
    Log::Printf("  %-4s %s", "?", "this menu");
    Log::Rule('=');
    Log::Printf("");
}

static void PrintStatus()
{
    Log::Section("RIG STATUS");
    Log::Printf("  channel          : %d", Driver::Channel());
    Log::Printf("  gain mode        : %s (gain %d/%d)",
                Output::ModeName(Driver::Mode()),
                Output::GainNum(Driver::Mode()), Output::GainDen(Driver::Mode()));
    Log::Printf("  commanded key    : %d mV", Driver::Rig().key_mv);
    const Harness::RigProblem v = Harness::Validate(Driver::Rig());
    Log::Printf("  timing config    : %s", Harness::ProblemName(v));
    Log::Printf("    press_on %u ms  inter_press %u ms  long %u ms  double_window %u ms",
                (unsigned)Driver::Rig().press_on_ms,
                (unsigned)Driver::Rig().inter_press_ms,
                (unsigned)Driver::Rig().long_press_ms,
                (unsigned)Driver::Rig().double_window_ms);
    Log::Printf("  AUX1 switch      : %s", Driver::AuxClosed() ? "CLOSED (pin low)" : "open (high-Z)");
    int mv = 0;
    if (Driver::ReadKeyMv(&mv)) {
        Log::Printf("  KEY line now     : %d mV", mv);
    } else {
        Log::Printf("  KEY line now     : (ADC read failed)");
    }
    Log::Printf("  released level   : ch1 %d mV, ch2 %d mV",
                KeyLine::FloatMv(1), KeyLine::FloatMv(2));
}

static void PrintDiagnostic()
{
    Log::Section("DIAGNOSTIC -- is the rig wired and reachable?");
    for (int ch = 1; ch <= 2; ++ch) {
        const int idle = KeyLine::FloatMv(ch);
        int now = 0;
        const bool ok = Driver::ReadKeyMv(&now);   // reads the SELECTED channel
        Log::Printf("  channel %d: released level %d mV", ch, idle);
        if (ch == Driver::Channel()) {
            Log::Printf("             now reads %d mV%s", now, ok ? "" : " (read failed)");
        }
        // The reachable band is everything below the released level, floored by
        // the servo envelope's low edge.
        const int reachable_hi = idle - Output::kCommandHeadroomMv;
        if (reachable_hi <= Output::kEnvelopeLowMv) {
            Log::Printf("             NO usable command band below %d mV "
                        "(is the DUT's pull-up present and is the wire attached?)",
                        Output::kEnvelopeLowMv);
        } else {
            Log::Printf("             commands reachable from %d mV up to %d mV",
                        Output::kEnvelopeLowMv, reachable_hi);
        }
    }
    Log::Printf("");
    // The LOOPBACK: the DUT's SWC out is wired to this board's SWC in, so the
    // driver's own ladder input reads back what the DUT is commanding on its KEY
    // line. This is the one place the rig can see the DUT's OUTPUT rather than
    // only its frames -- and it is how a "the DUT emitted an event but nothing
    // reached the head unit" fault is told from a reporting bug.
    uint32_t dut1 = 0, dut2 = 0;
    const bool l1 = Adc::ReadAvgMv(Adc::kSwc1, 16, &dut1);
    const bool l2 = Adc::ReadAvgMv(Adc::kSwc2, 16, &dut2);
    Log::Printf("  DUT KEY out (loopback) : ch1 %s%u mV, ch2 %s%u mV",
                l1 ? "" : "?", (unsigned)dut1, l2 ? "" : "?", (unsigned)dut2);
    Log::Printf("      (near the 3.3 V rail = the DUT is RELEASED; a low value = it is");
    Log::Printf("       driving a key. The DUT holds its line high when it has no head");
    Log::Printf("       unit to command -- see spec 6.2's envelope.)");
    Log::Printf("");
    Log::Printf("  A released level near 3.3 V says the DUT's 10k pull-up is doing its");
    Log::Printf("  job and the wire is attached. Near 0 V says the line is shorted or");
    Log::Printf("  nothing is driving it -- check the J3->J2 wiring and the common ground.");
}

// The learn entry the DUT's spec 7.4 describes: the programming switch (AUX1)
// held, then `slot` selection presses, then the key held while the DUT samples.
// The whole sequence lives in Driver::Learn, so the menu is only the prompt.
static void DoLearnPrompt()
{
    Log::Prompt("  which slot (1-8)? ");
    const uint32_t t0 = millis();
    int slot = 1;
    while (millis() - t0 < 4000) {
        if (Serial.available()) {
            const int c = Serial.read();
            if (c >= '1' && c <= '8') { slot = c - '0'; break; }
            if (c == '\r' || c == '\n') break;
        }
        delay(10);
    }
    Log::Printf("%d", slot);
    Driver::Learn(slot);
}
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

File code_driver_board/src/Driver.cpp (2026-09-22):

#include "Driver.h"

#include <Arduino.h>

#include "Adc.h"
#include "BoardPins.h"
#include "Dac.h"
#include "KeyLine.h"
#include "Log.h"
#include "driver/gpio.h"

// Included DIRECTLY here, not only through Driver.h. PlatformIO's library
// dependency finder scans the includes of files in `src/`; an include that is
// reached only through a header in `include/` is not followed, so the
// swc_logic library would never be linked and the build would fail with
// undefined references to Output:: at link time. The bring-up tool carries the
// same include in its own src/ for the same reason.
#include "swc_logic/Output.h"

// The AUX1 pad is an ADC channel on the DUT, but on the DRIVER it is only ever an
// output: it sinks the DUT's AUX1 node when the programming switch is closed.
//
// It is driven with the IDF gpio API rather than pinMode() because the pin is
// attached to the ADC peripheral (Adc::Begin configured it), and while that
// attachment holds, `pinMode`/`digitalWrite` do not reliably own the pad -- the
// same trap the bring-up tool's AUX probe documents at length. gpio_reset_pin
// detaches it from the ADC mux and hands it back to plain GPIO.
static const uint8_t kAuxStimPin = PIN_AUX1;   // J5.4

namespace Driver {

namespace {
int            s_channel = 1;
Output::Mode   s_mode    = Output::Mode::kAmplified;
bool           s_aux     = false;
Harness::RigConfig s_rig  = Harness::kDefaultRig;

// The mode auto-selection landed on, for the log line.
const char *ModeStr(Output::Mode m) { return Output::ModeName(m); }

void AuxApply(bool closed)
{
    gpio_reset_pin((gpio_num_t)kAuxStimPin);
    gpio_set_pull_mode((gpio_num_t)kAuxStimPin, GPIO_FLOATING);
    if (closed) {
        pinMode(kAuxStimPin, OUTPUT);
        digitalWrite(kAuxStimPin, LOW);      // sink the DUT's AUX1 to GND
    } else {
        pinMode(kAuxStimPin, INPUT);          // high-Z: the DUT's pull-up holds it open
    }
}
}  // namespace

bool Begin()
{
    Log::Section("RIG DRIVER -- SWC stimulus for the device under test");

    const bool dac_ok = Dac::Begin();
    Log::Printf("DAC at 0x%02X: %s", Dac::Address(), dac_ok ? "present" : "NOT FOUND");

    // The output MUST start released: a stray command on boot is a phantom key
    // press on the car the DUT is emulating.
    Dac::Release(1);
    Dac::Release(2);

    AuxApply(false);
    Log::Printf("AUX1 programming switch: OPEN (pin IO%d high-Z)", kAuxStimPin);

    Log::Rule('-');
    Log::Printf("  Wiring this rig expects (both boards are the same hardware):");
    Log::Printf("    driver J3.3 KEY1  ->  DUT J2.3 SWC1   (ladder stimulus)");
    Log::Printf("    driver J3.2 KEY2  ->  DUT J2.2 SWC2");
    Log::Printf("    driver J5.4 AUX1  ->  DUT J5.4 AUX1   (programming switch)");
    Log::Printf("    GND               ->  GND             (common ground is required)");
    Log::Rule('-');

    // Read the released level on each channel so the operator sees the rig is
    // connected before running anything that depends on it.
    for (int ch = 1; ch <= 2; ++ch) {
        const int idle = KeyLine::FloatMv(ch);
        Log::Printf("  channel %d released level: %d mV  (a command must sit BELOW this)",
                    ch, idle);
    }
    Log::Printf("");
    return dac_ok;
}

void SelectChannel(int ch) { s_channel = (ch == 2) ? 2 : 1; }
int  Channel()             { return s_channel; }

void SetMode(Output::Mode m) { s_mode = m; }
Output::Mode Mode()          { return s_mode; }

void AutoSelectMode()
{
    const int idle = KeyLine::FloatMv(s_channel);
    Output::Mode m = s_mode;
    const Output::Decision d = Output::SelectFromIdleKeyMv(idle, &m);
    s_mode = m;
    Log::Printf("auto mode: idle %d mV -> %s -> %s (gain %d/%d)",
                idle, Output::DecisionName(d), ModeStr(m),
                Output::GainNum(m), Output::GainDen(m));
}

int DriveKeyMv(int key_mv)
{
    // Reachability: on this rig the DUT's ladder node can only be pulled DOWN
    // from its resting level, so a target at or above the float level is a
    // release, not a command. Report it rather than writing a code that cannot
    // take effect.
    const int idle = KeyLine::FloatMv(s_channel);
    if (key_mv >= idle) {
        Log::Printf("drive %d mV refused: at or above the released level (%d mV) -- "
                    "this is a release, not a command", key_mv, idle);
        return -1;
    }

    int code = Output::CodeForTargetKeyMv(s_mode, key_mv);
    if (code < 0) {
        Log::Printf("drive %d mV refused: unreachable in %s mode", key_mv, ModeStr(s_mode));
        return -1;
    }
    if (code > Output::kDacMaxCode) code = Output::kDacMaxCode;

    const int wrote = Dac::SetSignal(s_channel, s_mode, (uint16_t)code);
    if (wrote < 0) {
        Log::Printf("drive %d mV: DAC write FAILED (bus error)", key_mv);
        return -1;
    }
    return code;
}

void Release()
{
    Dac::Release(s_channel);
    Dac::Release(1);
    Dac::Release(2);
}

bool ReadKeyMv(int *out_mv)
{
    int mv = 0;
    const Adc::Ch ch = (s_channel == 2) ? Adc::kSense2 : Adc::kSense1;
    uint32_t sense = 0;
    if (!Adc::ReadAvgMv(ch, 16, &sense)) return false;
    mv = Output::KeyMvFromSenseMv((int)sense);
    if (out_mv) *out_mv = mv;
    return true;
}

void SetAuxClosed(bool closed)
{
    s_aux = closed;
    AuxApply(closed);
}

bool AuxClosed() { return s_aux; }
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

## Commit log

2026-09-12 Resync C1/C2 to an Economic-eligible bulk input capacitor
    C3151829 (ROQANG RVT1H101M0607) carries JLCPCB `PCBA Type: Standard Only`,
    which forces the whole order onto Standard PCBA. Swap C1/C2 to C46550415
    (jieerrui JVJ50V100M6x8), which is `Economic and Standard`.
    Identical part class, so no layout change: 100 uF / 50 V, +/-20 %,
    2000 hrs @105 C, SMD D6.3 x L7.7 mm, same `Capacitor_SMD:CP_Elec_6.3x7.7`
    footprint and the same `100uF/50V` value. It also adds a published ripple
    rating (140 mA @120 Hz) that the ROQANG part never listed, and widens
    operation from -40..+105 C to -55..+105 C.
    Schematic-only edit: the five part-identity properties (LCSC, MPN,
    Manufacturer, Datasheet, Description)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
    [SWC.kicad_sch]
2026-09-12 Document the JLCPCB PCBA Type field and fix the assembly-cost discrepancy
    MANUFACTURING.md explained the assembly cost entirely in terms of the
    Extended-part tier and asserted the board targets Economic PCBA. Both were
    incomplete: the service level is decided by a part's `PCBA Type` field
    (`Economic and Standard` vs `Standard Only`), a separate axis from
    Basic/Extended that neither the tier tables nor the pcbparts MCP expose. A
    single `Standard Only` part forces the whole order to Standard.
    New MANUFACTURING.md section 3 covers this and names the board's two
    `Standard Only` parts -- C1/C2 (now cleared) and U3 (not clearable).
    Sections 4-6 are the old 3-5, renumbered, with the fee discussion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
2026-09-12 Correct the MCU part identity in the live-state docs
    Both AGENTS.md and README.md still named the MCU as the Espressif
    ESP32-S3-WROOM-1-N4 (C2913197) after the re-source to the DOIT
    ESPS3-32-N4 (C49164655) landed in 6e9c292. Those two tables describe
    what is actually on the board, so they were stating a part the board
    does not carry.
    The CHANGELOG's historical "Added" line keeps the Espressif name on
    purpose - that is what the redesign originally used.
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2026-09-13 Add the SWC enclosure: printable case, lid, logo inlay, and build loop
    Adds plastic_case/, a parametric 3D-printable enclosure for the SWC board,
    generated by script rather than hand-modelled so the design stays in step
    with the PCB:
    - casegeom.py holds every dimension in board frame; build_case.py derives the
    base, lid, and logo pocket from it, and verify.py cross-checks the result
    against the PCB geometry rather than against the constants that produced it.
    - build.sh drives the whole loop (geometry checks, STEP/STL export, mesh
    validation, OrcaSlicer slice) and hard-fails if the ASA profile does not
    resolve as ASA.
    - ventilation, USB-C, wire-entry, screwdriver, buzzer, LED, and bu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
    [Case_Assembly.step, Case_Body.step, Case_Body.stl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]
2026-09-18 Add the SWC firmware + Android app spec and implementation plan
    One spec and one phased 24-task plan under docs/superpowers/, for a new
    code/ tree in this repo. The spec is the binding authority; the plan argues
    from it.
    The plan pins framework = espidf on pioarduino's platform tag 55.03.311
    (IDF 5.5.5) rather than stock PlatformIO, whose framework-espidf stops at
    4.6.1 and so predates the mbedTLS GCM fix the project exists to avoid.
    Four plan/spec conflicts were corrected before execution, all in the HAL
    seam: IHAL.h is a C header with prefixed enumerators (not enum class), and
    /SENSE1//SENSE2 are ADC channels per spec 2.2 (KEY line / 2, read by the
    servo trim loop) rather than GpioPins.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
2026-09-19 Add ESP-IDF PlatformIO skeleton for the SWC adapter
    framework = espidf on pioarduino's pinned platform tag. Stock PlatformIO's
    espressif32 7.1.3 publishes framework-espidf only up to IDF 4.6.1, which
    predates the mbedTLS GCM fix this project depends on; the fork ships IDF 5.5.5.
    Main asserts the 4MB/no-PSRAM assumption so a wrong board definition fails at
    boot rather than as a mystery later.
    [partitions.csv]
2026-09-19 Fix the ESP-IDF skeleton so it actually builds
    The brief's verbatim files did not build. Three defects, all fixed and
    verified end-to-end:
    partitions.csv was rejected by IDF -- app partitions must be 64 KB
    aligned (gen_esp32part.py ALIGNMENT[APP_TYPE]) and app1's 0x208000 is
    not. app0/app1 are now 0x1E0000 (1920 KB, was 1952 KB) with app1 at
    0x200000, keeping coredump at 0x3F0000 and the table ending at 0x400000.
    This costs 32 KB per slot, so spec 9.2's 1952 KB budget is now 1920 KB.
    Flash size silently stayed at 2 MB: board_build.flash_size is not
    honoured on the ESP-IDF path (the board->sdkconfig injection is
    Arduino-gated), so CONFIG_ESPTOOLPY_FLASHSIZE_4MB=y is set explicitly.
    The choi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
    [partitions.csv]
2026-09-19 Correct the spec's ladder model and its bring-up plan
    The steering-pad ladder is a series chain whose common is tied to GND, so a
    press pulls the input DOWN and idle is the HIGH state. An earlier revision read
    it as a divider against the vehicle's 12 V rail, which inverts the direction a
    press moves and put the whole range above the ADC ceiling.
    The binding corrections are in 6.3 (V_pin = 3.3 * R_ladder / (R_ladder +
    R_pullup), R1/R2 are the anti-alias filter and are NOT in the divider, and the
    new consequence 4: R_ladder_idle <= 7.25 * R_pullup). Classification normalizes
    against the idle reading (n = V_ADC / V_ADC_idle), not against a rail.
    Propagated to 2.4, 3.2, 3.4, 3.7, 5.7, 11 (FR-6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
2026-09-19 Rewrite the plan against the corrected spec
    The plan's code blocks still carried the retracted ladder model: a 5 V-referenced
    ladder swept against an 11.0-14.8 V "vehicle rail", idle at 5000 mV, buttons
    ABOVE idle, and a decode that normalized against a rail rather than the idle
    reading. That would have been implemented literally.
    Structural fixes:
    - Shared contract gains the ADC AUX1-3 channels (spec 2.2 lists eight ADC1
    channels; the contract had five, and the AUX inputs are the headless learn
    fallback's buttons) and the correct four DAC channels. Verified against the
    netlist: U4.VOUTA->ch1 signal, VOUTB->/V_ADJ1, VOUTC->ch2 signal,
    VOUTD->/V_ADJ2. There is no spare channel and th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
2026-09-19 Remove the three inert sdkconfig keys
    Task 1 correctly identified that CONFIG_TINYUSB_CDC_ENABLED,
    CONFIG_ESP_ADC_CAL_USE_EFUSE_CALIBRATION and
    CONFIG_ESP_ADC_CAL_DEFAULT_ATTENUATION_12 are undefined in IDF 5.5.5, and
    reported them -- but left them in sdkconfig.defaults. A key that reads as
    configuration while doing nothing is worse than an absent one: the file claimed
    a TinyUSB CDC app interface and per-chip ADC calibration that do not exist.
    Each is now removed with a comment saying what actually implements the intent.
    TinyUSB is the managed component espressif/esp_tinyusb (spec 4.1). ADC
    calibration on the S3 is the runtime API adc_cali_create_scheme_curve_fitting()
    -- and the ADC_CALI_*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
2026-09-19 Freeze the HAL enums, and stop encoding one line twice
    Task 2 freezes the header every later task compiles against, so its conflicts
    had to be settled before dispatch. Four were found, and one was structural.
    The real defect: GpioPin listed GPIO_BUZZ and GPIO_DAC_LDAC_B while spec 10.2
    already froze dedicated members buzzer_on and dac_ldac for the same two lines
    (/BUZZ IO13, ~LDAC IO48). The plan's own Task 2 test was titled "the buzzer is
    an on/off line, not a GPIO pin" while its own enum said otherwise, and Tasks
    12/13 drove the buzzer through gpio_write(GPIO_BUZZ, ...) in five places. In
    MockHal those are separate storage, so an implementer obeying the frozen spec
    would watch GpioRead(GP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
2026-09-19 Make the host test harness actually run
    The native env was broken three ways. Every host-test task (3-13, 15-17, 19)
    would have died on its first `pio test`, so this was fixed before Task 2 was
    dispatched rather than discovered by an implementer.
    test_dir is a GLOBAL option, not a per-env one. The plan set test_ignore per
    env and relied on a default test_dir, which only works if test_dir is the
    project root -- and it was never set. Setting it inside [env:native] prints
    "Warning! Ignore unknown configuration option 'test_dir'" and silently does
    nothing. It is now test_dir = . at the top, with test/ (Unity, device) and
    test_native/ (GoogleTest, host) both under it.
    Nothing supplied main(). g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
2026-09-19 Add the bounded output trim loop
    A step cap and a total authority cap are what keep this from fighting the
    hardware integrator: the loop mops up resistor tolerance and servo offset only.
    Tested against a 3% gain error and against an unreachable target, which must not
    walk the code to an extreme.
    [ServoLoopTest.cpp]
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2026-09-19 Add the config model with validated JSON and CRC'd blob codecs
    The model is the entity layout shared by firmware, app and web page. Validation
    rejects what would make classification ambiguous or the device unable to serve
    input -- centres closer together than the wider tolerance, a long-press
    threshold inside the double-press window, a button voltage above the ADC
    ceiling. A newer schema version is refused as its own condition, never
    misparsed, and nothing is written to the output until every field has decoded
    and the result validates.
    The blob is a version header plus CRC32 over the same JSON bytes ConfigEncodeJson
    produces -- one codec, so the two forms cannot drift.
    cJSON is pinned by g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
    [ConfigCodecTest.cpp]
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2026-09-20 Add the ESP32-S3 HAL implementation and wire up main
    ADC uses the curve-fit calibration scheme at 12dB attenuation (the 2.9V ceiling
    this board's divider assumes); a read error returns -1 rather than a fabricated
    zero, because zero is a legal reading. One time source feeds both now_ms and
    now_us so the host tests' semantics hold on device. main establishes safe idle
    before anything else, and aborts rather than rebooting into service if it cannot.
    The CMake changes are the load-bearing part. lib/ was never registered as an IDF
    component, so the device build compiled ONLY src/ and linked none of the eleven
    tasks below it -- while reporting SUCCESS and producing a valid image. The
    give-away wa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
    [main.cpp]
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2026-09-20 Add maintenance mode with BLE provisioning, the web page and both OTA paths
    The radio is never initialized in normal operation: MaintenanceMode is pure state
    (which trigger, whether the window is open, when it closes) and never touches
    NimBLE, so the timeout that decides whether a user is stranded is host-testable.
    The window is bounded at 5 minutes and every entry starts a fresh one.
    The web page is embedded in flash because spec 9.2's partition table has no
    filesystem, generated at build time by tools/gen_assets.py so the served page
    cannot drift from assets/index.html. It is token-gated with a per-device token
    salted differently from the BLE PoP, compared without an early return.
    Both O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
    [main.cpp]
2026-09-20 Add the USB CDC app link and the managed component it needs
    IDF 5.5.5 has no TinyUSB, so spec 4.1's app interface did not exist: the console
    worked and nothing else did. This adds espressif/esp_tinyusb via
    src/idf_component.yml and the CDC transport over it, keeping the console on the
    ROM USB-Serial-JTAG peripheral so a debug printf can never be read as a protocol
    frame. The TX byte buffer is sized for two maximum frames -- a single-frame buffer
    would make the second Send drop, which an app sees as a randomly missed key.
    Three things the plan had wrong, all found by building it:
    - The manifest must live in src/, the MAIN component. At the project root IDF
    never reads it and the only symp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
    [main.cpp]
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2026-09-20 Teach the app's GainMode about AUTO, or it rewrites the user's policy
    The firmware now accepts a channel gain_mode of "AUTO" (the spec's own worked
    example uses it), but the app's enum had only TRACKING and AMPLIFIED. The
    decoder's firstOrNull then fell back to TRACKING on a name it did not know, and
    the next save wrote a CONCRETE gain the user never chose -- silently overriding
    settings.gain_policy for that channel. An unknown enum member in a round-trip
    codec is data loss, not a cosmetic gap, so this is the other half of the kAuto
    change rather than a follow-up to it.
    Verified against the real thing rather than in principle: the app re-emits the
    fixture and the firmware decodes it byte-id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
    [ConfigCodecTest.kt, ConfigJson.kt]
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2026-09-20 Bound aux_count in ConfigValidate like every other array count
    BindingNamesARealInput loops `i < c.aux_count` over `c.aux[i]`, and aux_count
    was the one counted array ConfigValidate never bounded. channel_count,
    ladder.count, binding_count and action_count are all checked against their
    arrays in the same function; an aux_count past the 3-entry table therefore ran
    the validation loop off the end of the array it exists to protect.
    Not reachable from a config on the wire -- DecodeAux refuses a count over the
    max, and both NVS paths pass through the decoder -- so this is a latent fault
    that a future caller with no decoder in front of it would hit. The new
    assertion in ValidationRejectsInconsist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
    [ConfigCodecTest.cpp]
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2026-09-21 Refuse a fractional value in an integer config field, not truncate it
    ReadU32/ReadU64 cast a double to an integer after bounding the MAGNITUDE but
    never noticing a fractional part, so `long_press_ms = 750.9` silently became
    750 -- a config the device accepts and then behaves differently from what was
    sent, the same wrong-value-accepted class as the uint32 wrap these readers
    already guard against. config_patch refuses a fraction for these same fields
    (previous commit), so truncating here left the two paths with two answers to
    one question.
    Mutation-tested: removing the fraction check fails the new codec case.
    [ConfigCodecTest.cpp]
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2026-09-21 Correct a gain_mode comment that described a mechanism that does not exist
    The decode of `output.gain_mode` carried a comment saying an unknown name "must
    NOT be silently coerced" and that unknown names "are recorded so a caller can
    refuse to round-trip". Neither half is true: no such recording exists anywhere,
    no caller refuses a round trip, and the code performs exactly the `?: TRACKING`
    coercion the comment forbids. The behaviour is in fact correct -- the firmware's
    own decoder REFUSES an unknown gain_mode name, so a real device cannot emit one
    -- but the comment would send a reader looking for a safeguard that is not
    there. Replaced with why the fallback needs no such machinery.
    [ConfigJson.kt]
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2026-09-21 Use each mode's own gain in the servo step, ratio the learn noise gate, order semver pre-releases
    Three numeric defects found by audit, none reachable through the shipped
    tuning but all wrong on the arithmetic:
    - ServoLoop converted a sense-pin error to DAC codes with the TRACKING-mode
    figure (0.4 mV/code) in both modes. Amplified mode is 1.82x coarser
    (0.733 mV/code), so the computed step was 1.82x too large -- a loop gain
    near unity that rings rather than converges. Masked today because
    max_step_codes is 8 and every error past the 20 mV deadband saturates it;
    it bites the moment the step cap is raised while the gain is measured on
    hardware (spec 6.5).
    - LearnSession's noise g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
    [ServoLoopTest.cpp]
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2026-09-21 Bring-up on hardware: 30/30 tests pass. Fix nine defects it exposed.
    Ran the full suite against the assembled board and worked every failure to
    root cause. All 30 device tests and 48 host tests now pass.
    ONE CRITICAL BUG, which would have made the whole tool worthless:
    Adc::Begin() was never called. The ADC unit was never created, ReadMv
    returned false, and every caller's out-param stayed at its initialized 0
    -- so all 30 tests would have measured 0 mV and declared the board
    comprehensively broken. Nothing warned: the function has external
    linkage, so -Wunused-function cannot fire. Found by a review pass, not
    by the tests, and fixed by calling it in the boot sequence with a
    l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
    [Dac.cpp, KeyLine.cpp]
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2026-09-21 Run tests on their own task, and rebuild the web UI around clear status
    The web UI locked up during any test and asked for vague "any click"
    input. Both were symptoms of one architectural mistake: tests ran
    synchronously inside loop(), so the HTTP server was never serviced for the
    duration of a test -- 9 s for test 20, 12 s for test 22, up to 90 s for the
    two operator tests. During that window the page could not load, could not
    refresh, and a click did nothing, so a test running perfectly looked like a
    dead page. Earlier attempts (a pump inside the wait, a deferred-request
    flag, a spinner) all treated the symptom.
    THE FIX IS THE SPLIT:
    loop()'s task the web server and the serial m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
    [Log.cpp]
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2026-09-22 Test 31 drives its own stimulus: unattended, 180 s -> 340 ms
    The AUX test was six operator prompts per run, slow, and the web UI made it
    worse by re-asking after every Continue. Replaced with a self-driven rig:
    J5.4 (AUX1) <-> IO16 (TP5)
    J5.3 (AUX2) <-> IO21 (TP6)
    J5.2 (AUX3) <-> IO43 (TP7)
    Pulling the spare pin LOW pulls the AUX input to GND through the wire
    (button pressed); floating it lets the board's 10k pull-up set the level
    (released). The test does both, plus a recovery read, entirely on its own.
    Measured: 341 ms, zero prompts, versus 178 s and six prompts before.
    It also reports honestly about its own rig rather than assuming it:
    - no swing on any input -> SKIP, wit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
    [BoardPins.h]
2026-09-22 Discover the AUX rig instead of assuming it; measure servo response time; RT1 notes
    TEST 31 ASSUMED ITS OWN WIRING AND WAS WRONG
    It hard-coded stim1->AUX1, stim2->AUX2, stim3->AUX3. The real rig has two
    wires crossed, so it reported "no response" for two perfectly healthy
    lines -- the hardware was right and the code's assumption was not.
    It now DISCOVERS the mapping before measuring anything: drive each spare
    pin low in turn and record which AUX inputs move. Any input may go to any
    test point. Measured here: IO21->AUX2, IO16->AUX3, and IO43->AUX1 not
    connected. Result is PASS on all three when the wires are fitted.
    Two things had to be right for IO43 (TXD0) to work as a stimulus:
    - gpio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
    [BoardPins.h]
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2026-09-22 Land the host-verified firmware and app, and make CI honest
    Repairs the CI path defect first, because without it none of the rest was
    being checked: both workflows sat at `code/.github/workflows/`, which is not
    where Actions reads them (N-33), so the gates never ran. They now live at the
    repo-root `.github/workflows/`, and the six static gates the workflow invokes
    by name (`check_app_limits`, `check_frame_handlers`, `check_hal_contracts`,
    `check_sdkconfig_keys`, `check_stack_usage`, `check_task_ownership`) plus their
    self-tests are tracked rather than untracked, so a clean checkout's CI runs
    them instead of failing on a missing file.
    The body is the accumulated audit work across both halves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
    [ConfigCodecTest.cpp, ConfigCodecTest.kt, ConfigFixtures.h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]
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2026-09-22 Headless learn names its input instead of a menu (N-23)
    The AUX1 learn had no channel selector, so every no-app learn landed on
    SWC1 and SWC2 was learnable by no shipping means (the app has no learn
    screen). Replace the slot menu with the 2022 interaction the user pointed
    at: hold AUX1, press the input being programmed, release to commit. The
    wizard names the target by which input LEFT ITS IDLE -- exactly
    is_key_pressed()'s rule -- so one hold programs one input and SWC1/SWC2
    learn identically.
    LearnWizard takes a LearnInputs list (wire channel, ADC pin, live idle,
    ladder-vs-switch, id) and drops its GestureTimings arg; SystemOrchestrator
    loses learn_channel_/learn_idle_mv_, gains ApplyLear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
    [ConfigJson.kt]
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2026-09-22 Bring the app's config validator to rule-level parity (N-40)
    `ConfigJson.problems()` mirrors the firmware's `ConfigValidate`, but it checked
    only the numeric limits: the ladder-geometry rules, the two remaining string
    widths, and the "binding names a real input" rule had no app-side check, so a
    config the app accepted was refused by the device at decode -- the failure the
    local gate exists to prevent, reported as a nack naming a check rather than the
    field.
    The missing rules now mirror the firmware: learned_idle_mv and mv_center ranges
    against the ADC ceiling, the derived window's positive-ratio rule,
    `LadderWindowsAreDistinguishable`, `BindingNamesARealInput`, and the device-id /
    channel-n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
    [ConfigCodecTest.kt, ConfigJson.kt]
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2026-09-23 Prove FR-37's A/B rollback on the board, with a real panicking image
    Spec 10.4's level-4 test is explicit: "flash a deliberately-faulting image
    (compiles, panics at startup), assert the bootloader rolls back and the device
    comes up on the old image. This must be tested with a genuinely broken image,
    not a mocked failure, or it proves nothing." The board is here, so it is done.
    `src/main.cpp` gains a bench-only hook, guarded by `-D SWC_BENCH_PANIC_IMAGE`
    (no shipping env sets it, so the product image cannot contain the path): a NULL
    dereference as the FIRST statement of `app_main`, before any HAL or
    orchestrator work, so the image can never reach
    `esp_ota_mark_app_valid_cancel_rollback`. Tha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
    [main.cpp]
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2026-09-24 Prove FR-40's watchdog reset on the board; report status.reset_reason
    The WDT reset was previously written off as unreachable (task-WDT panic
    unset, brownout needs a power cut). The interrupt watchdog DOES panic and
    reboot here, so -D SWC_BENCH_WDT_RESET stalls with interrupts off on a
    non-WDT boot (self-limiting: it falls through on a WDT boot). Proven with
    three signals: status.reset_reason == 5 (ESP_RST_WDT, the device's own
    report), a multi-second silent stall, and uptime restarting; afterwards
    output_safe=true and the loopback shows the KEY line idle.
    reset_reason was ADDED to status (IHAL reset_reason) because the console
    is on the ROM USB-Serial-JTAG the firmware stops writing to onc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
    [main.cpp]
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2026-09-28 No-app gesture programming: hold AUX1, gesture, head unit learns (N-89)
    Restores the 2022 Pico flow the user asked for: hold AUX1, perform the gesture
    on a learned wheel button, and the adapter HOLDS that gesture's voltage on the
    KEY line while the head unit's own "set key function" screen learns it; release
    AUX1 to release the line. Previously the output was suppressed during the hold,
    so there was nothing on the line to program.
    Three coupled changes:
    - Output/GestureLevels.{h,cpp}: a predefined ascending slot table (48 slots,
    ~20 permille apart) mapped as a fraction of the output band, so a gesture's
    voltage is fixed and correct on both 5 V and 3 V head units.
    - spec 6.6 rule 4 corre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
    [ConfigCodecTest.cpp, ConfigFixtures.h, ConfigJson.kt]
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

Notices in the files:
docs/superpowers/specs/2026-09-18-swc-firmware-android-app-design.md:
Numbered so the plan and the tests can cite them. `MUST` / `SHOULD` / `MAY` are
